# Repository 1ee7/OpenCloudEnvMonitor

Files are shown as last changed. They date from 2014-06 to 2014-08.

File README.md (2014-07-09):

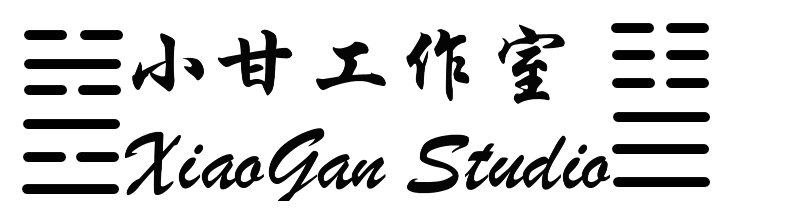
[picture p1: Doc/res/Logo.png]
小甘工作室

OpenCloudEnvMonitor
===================

**开源个人环境监测平台**

##系统简介
  系统框图请参考[这里](https://github.com/xiaogan-Studio/OpenCloudEnvMonitor/blob/master/Doc/design/%E7%B3%BB%E7%BB%9F%E6%A1%86%E5%9B%BE.xlsx)
  (Tips：点击 View Raw 下载excel文件查看。或者感兴趣的话，可以clone下来整个项目再查看。各种资料请到Doc目录下查看.)
  
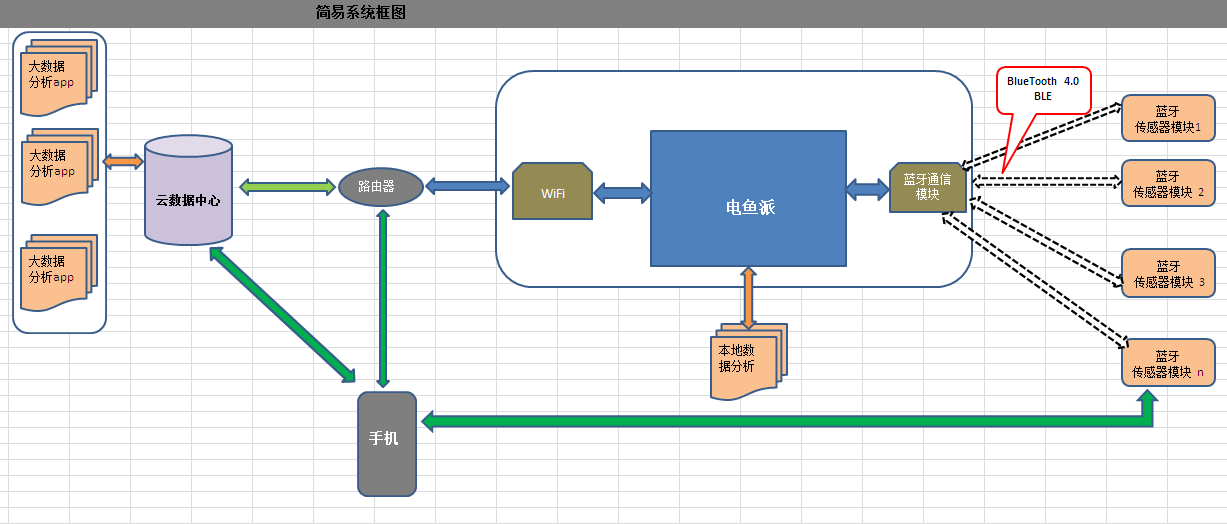
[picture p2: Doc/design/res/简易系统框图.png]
简易系统框图
         

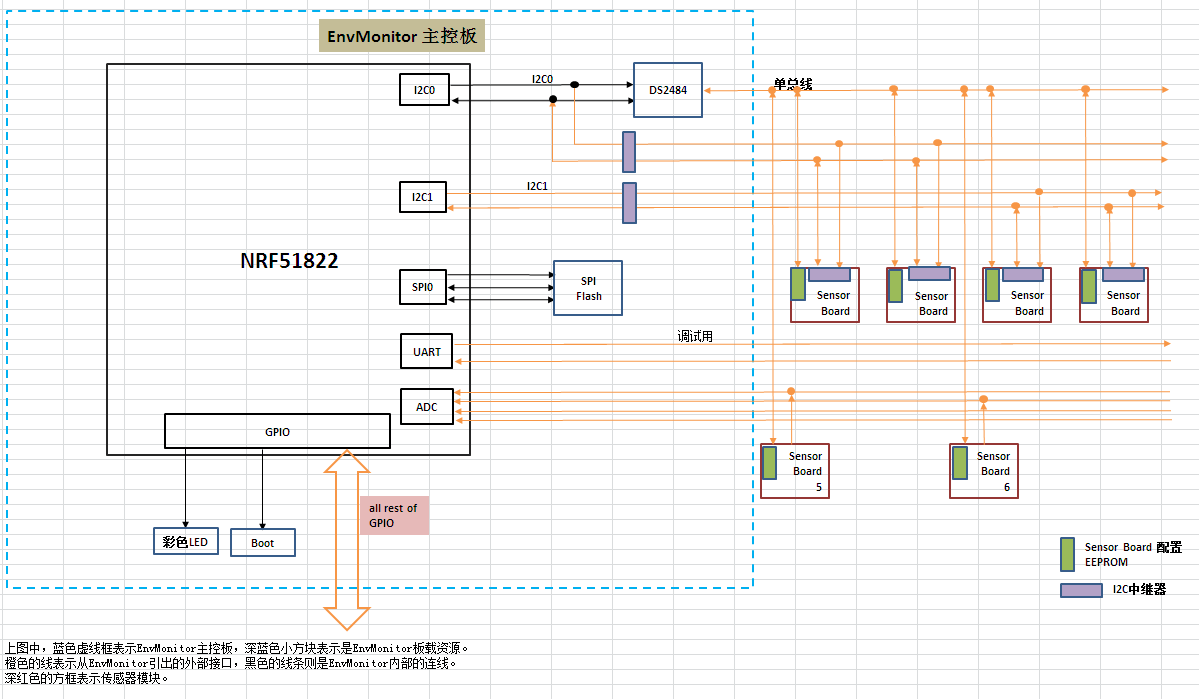
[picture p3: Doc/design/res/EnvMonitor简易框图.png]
蓝牙采集模块简易框图
  

## 相关资源列表
[oneNote共享笔记](https://onedrive.live.com/edit.aspx/Knowledge/OpenCloudEnvMonitor?cid=be5c272d3ffda8af&id=documents?&)，用于记录软硬件开发过程，包括各种问题的探讨资料。共享笔记，任何人均可编辑。其中：
- *envMonitor软件UML设计* 包含软件前期设计时一些分析资料。
- *硬件相关探讨* 与硬件相关的探讨。

### 硬件设计资源
[envMonitor MainBoard工程目录](./Doc/hardware/原理图),包含PDF版本的原理图以及AD工程文件

[envMonitor MainBoard原理图设计分析](./Doc/design/EnvMonitor原理图分析.docx)，简单分析，等硬件稳定后会提供详细分析文档。

### 软件设计资源

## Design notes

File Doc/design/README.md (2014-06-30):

# 本目录主要存放一些设计方面的文档资料。

## 系统框图.xlsx
  保存整个系统硬件方面的详细设计框图。包括如下内容：
  - 系统整体简略示意图                  （已作成）
  - EnvMonitor系统框图                  （已作成）
  - EnvMonitor的详细设计图              （TODO）
  - 各个Sensor board的系统框图          （TODO）
    1. 粉尘传感器Module框图              (TODO)
  - 各个Sensor board的详细设计图        （TODO）

## nRF51822硬件设计相关分析.xlsx
  保存硬件设计时的一些检讨资料。比如电源方案的探讨，外部通信接口的探讨等一些在设计时讨论资料。
  目前有如下内容：
  - 电源方案选择
  - 硬件模块化探讨
  - 增加USB功能的探讨：讨论与上位机USB通信的方法

## 软件框图.xlsx
   保存软件前期设计中的一些检讨资料。
   目前有如下内容：
   - EnvMonitor整体功能拆分
   - Sequence Diagram: 系统比较典型的一些序列图
   - BootLoader模型详细设计
   - Main模块详细设计
   - Initializer模块详细设计
   - Scheduler模块详细设计
   - SensorManager模块详细设计
   - SensorCapture模块详细设计
   - SensorUpload模块详细设计
   - SensorQuery模块详细设计
   - ConfigParser模块详细设计
   - BoardManager模块详细设计
   - OneWire Driver模块设计
   - I2C Driver模块设计
   - ADC Driver模块设计
   - DataCapture模块设计
   - SPI FlashDriver模块详细设计
   - SPI Driver模块详细设计
   - GPIO Driver模块详细设计
   - UART Driver模块详细设计
   - SystemDebug模块详细设计
   - PinMuxCfg模块详细设计
   - BLE Service Driver模块详细设计

## envMonitor.asta
  系统UML设计图表,保存系统软件设计相关的UML图纸。请使用[astah打开](http://astah.net/editions/community)
  - System overview
  - 用户升级序列图(sequence diagram)
  - 固件启动序列图(sequence diagram)
  - System Detail Design

## memory_layout.xlsx
  内部Flash和外部SPI Flash数据布局设计文件。标明数据在Flash中的摆放顺序。
  - 内部Flash Layout
  - 外部SPI Flash Layout
  - 1-Wire EEPROM Layout

## EnvMonitor原理图分析.docx
  关于原理图设计的一些简单分析。后期会提供比较详尽的电路分析资料
  
## 原理图Review记录.md
  EnvMonitor MainBoard原理图Review记录。保存Review过程中的一些问题。

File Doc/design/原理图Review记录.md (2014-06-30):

#EnvMonitor MainBoard原理图第一次Review
**时间:** 2014年6月27日

**参加人员：** 不限，有兴趣者都可编辑此文件，参与探讨

**6月29日 Review完成，TODO List如下**  
- [ ] 系统强制断电：由张建芳完成
- [x] USB转SPI芯片选型
      - → **放弃该方案**
- [x] SPI Flash 芯片SPI线和WP信号引出来，方便烧写器直接烧写
-     图纸更改时，可直接引出。
- [x] SPI Flash更换大容量的型号
-     型号已有，可以使用MX66L1G45G，1Gb，合计128MB。旺宏电子，SPI Flash最大的容量。

##1.EnvMonitor MainBoard图纸
- 原理图PDF版本：[6月27日原理图](https://github.com/xiaogan-Studio/OpenCloudEnvMonitor/blob/master/Doc/hardware/%E5%8E%9F%E7%90%86%E5%9B%BE/EnvMonitor%202014-6-27.pdf)
- 关于原理图的设计，请参考[here](https://github.com/xiaogan-Studio/OpenCloudEnvMonitor/blob/master/Doc/design/EnvMonitor%E5%8E%9F%E7%90%86%E5%9B%BE%E5%88%86%E6%9E%90.docx)

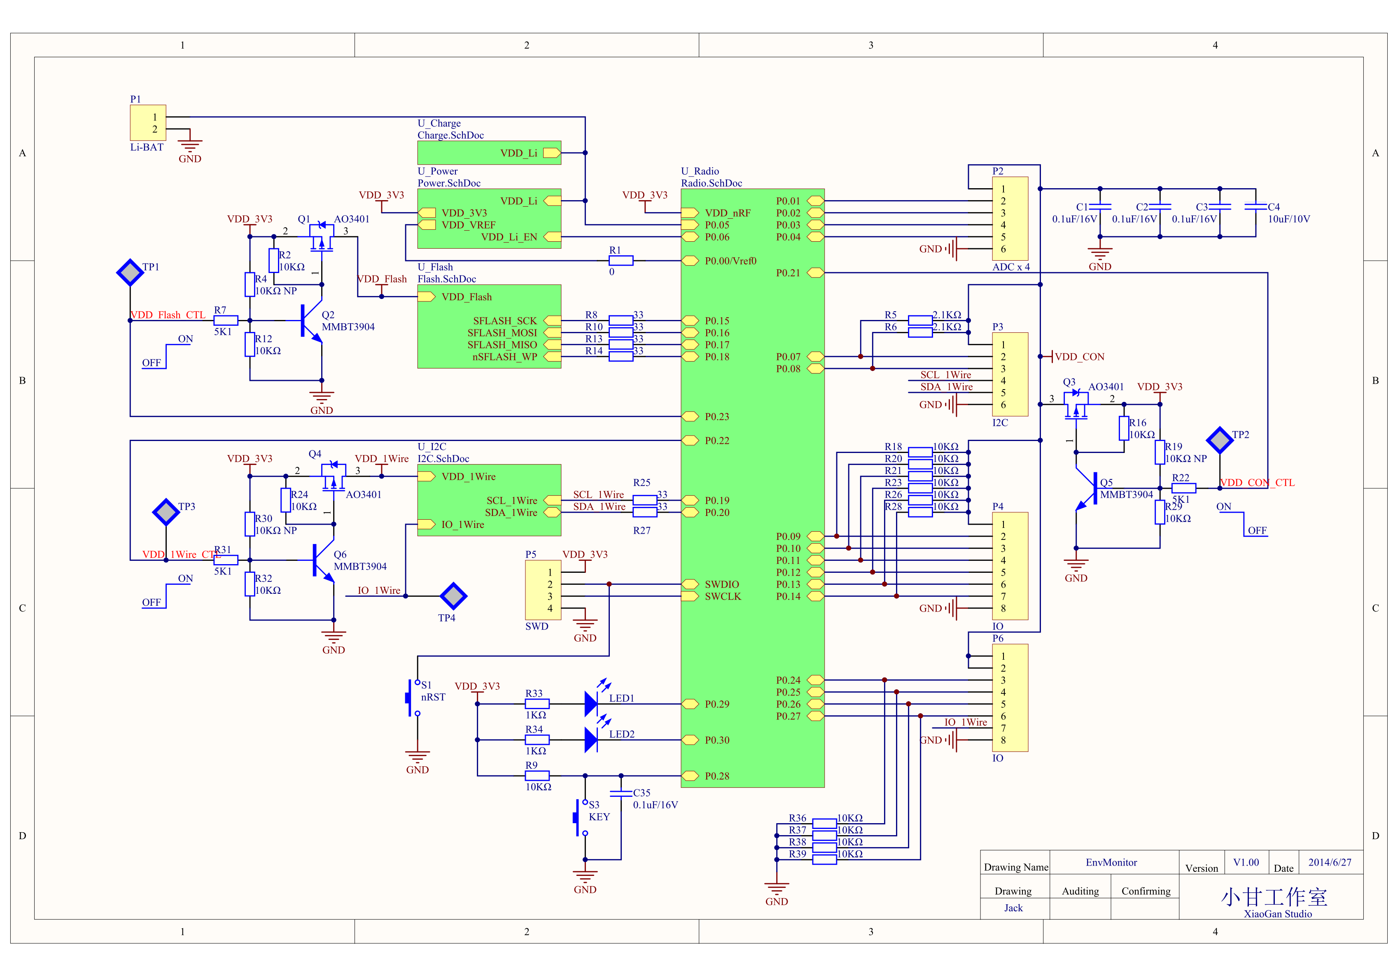
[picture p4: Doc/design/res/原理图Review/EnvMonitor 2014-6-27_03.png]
Overview

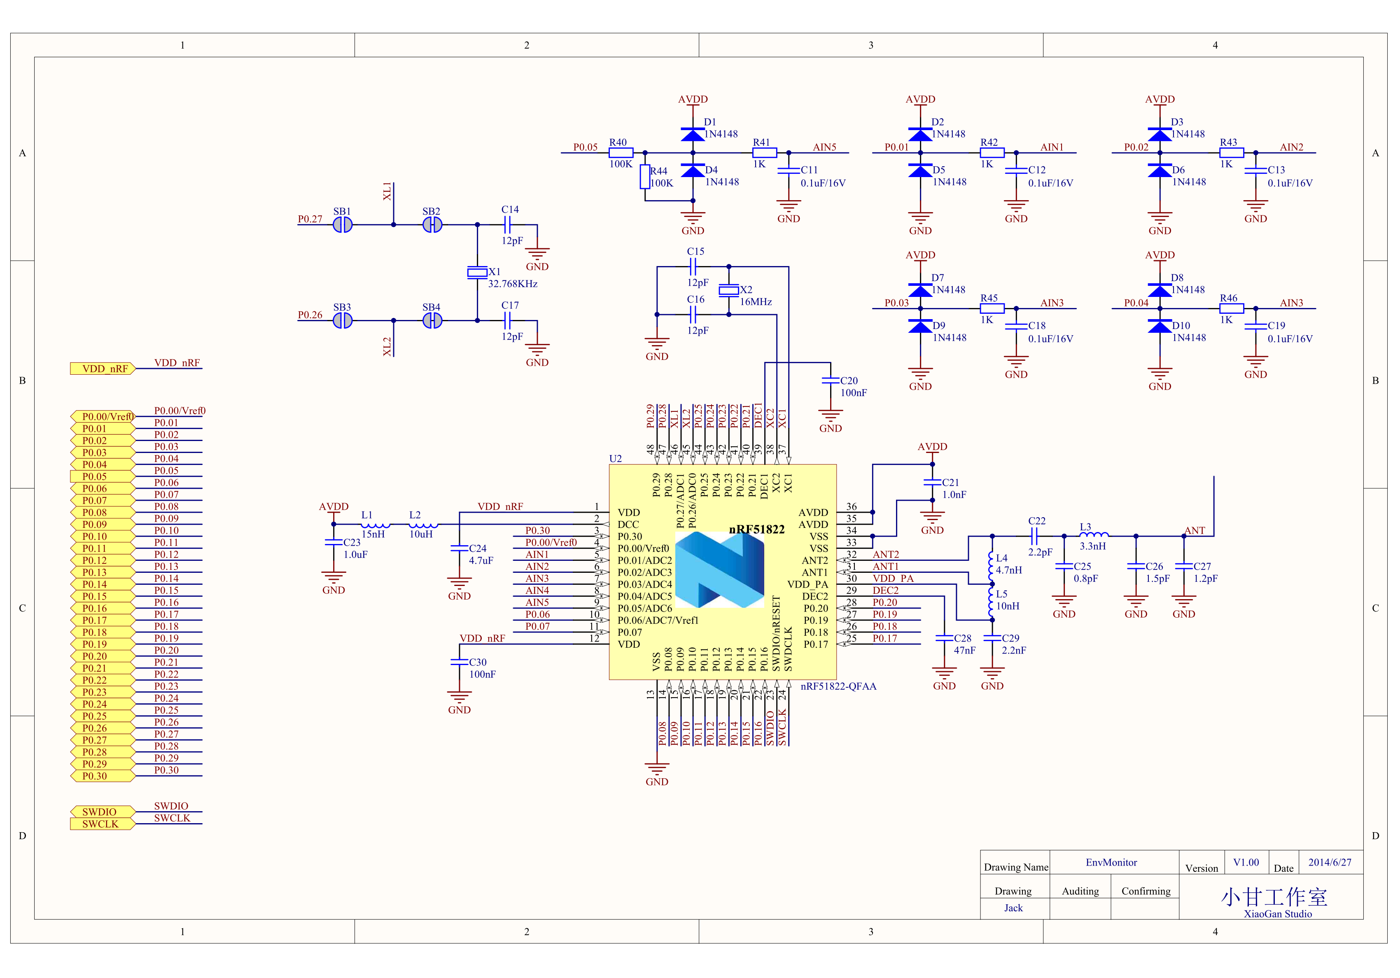
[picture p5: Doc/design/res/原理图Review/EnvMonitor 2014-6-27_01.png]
nRF51822

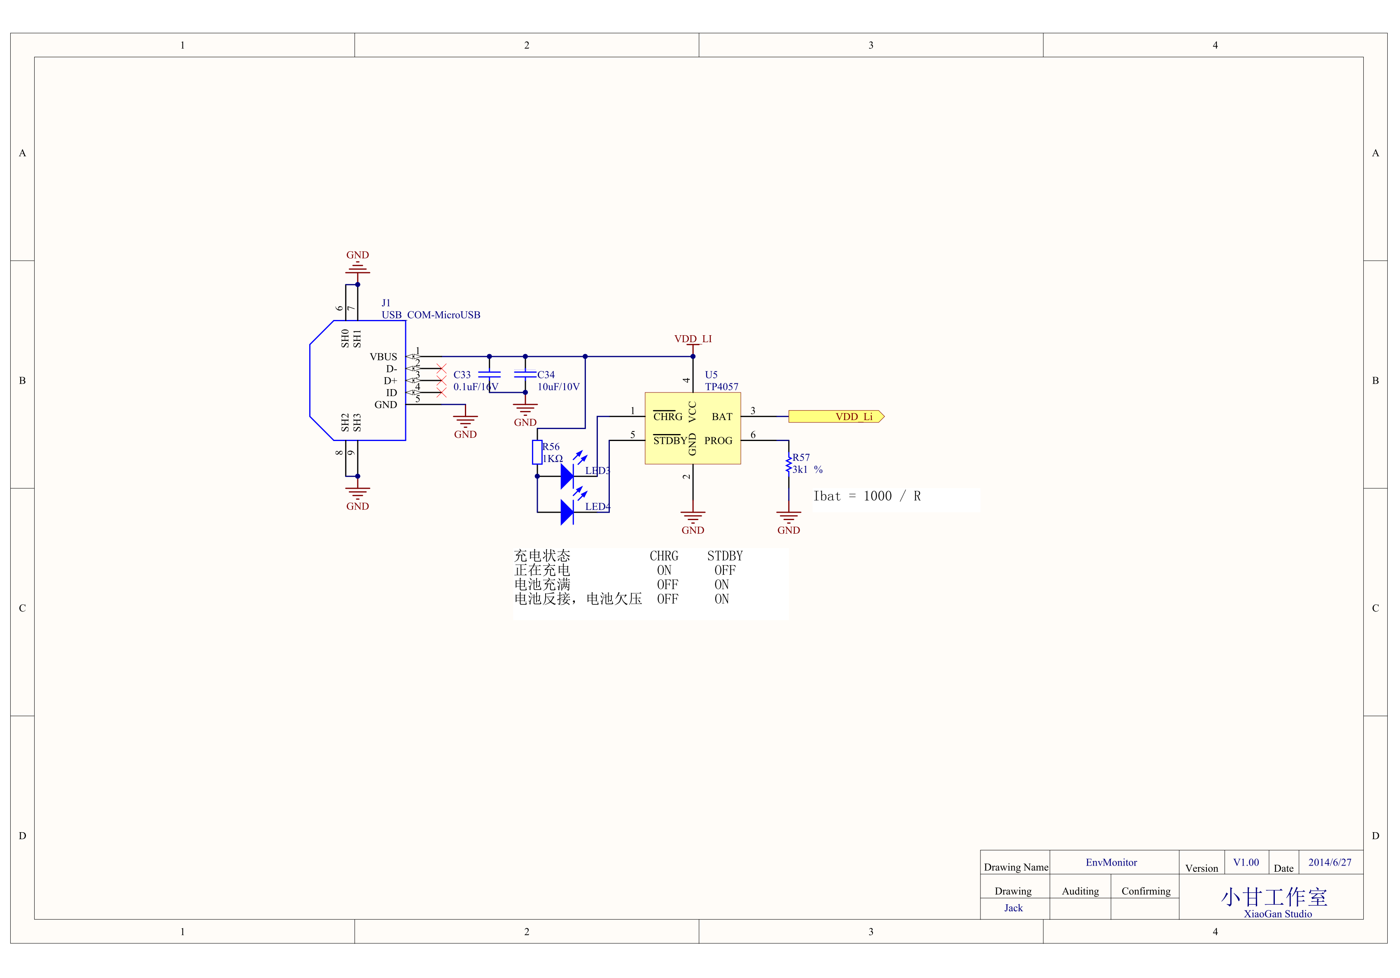
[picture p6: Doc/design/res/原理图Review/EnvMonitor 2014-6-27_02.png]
充电电路

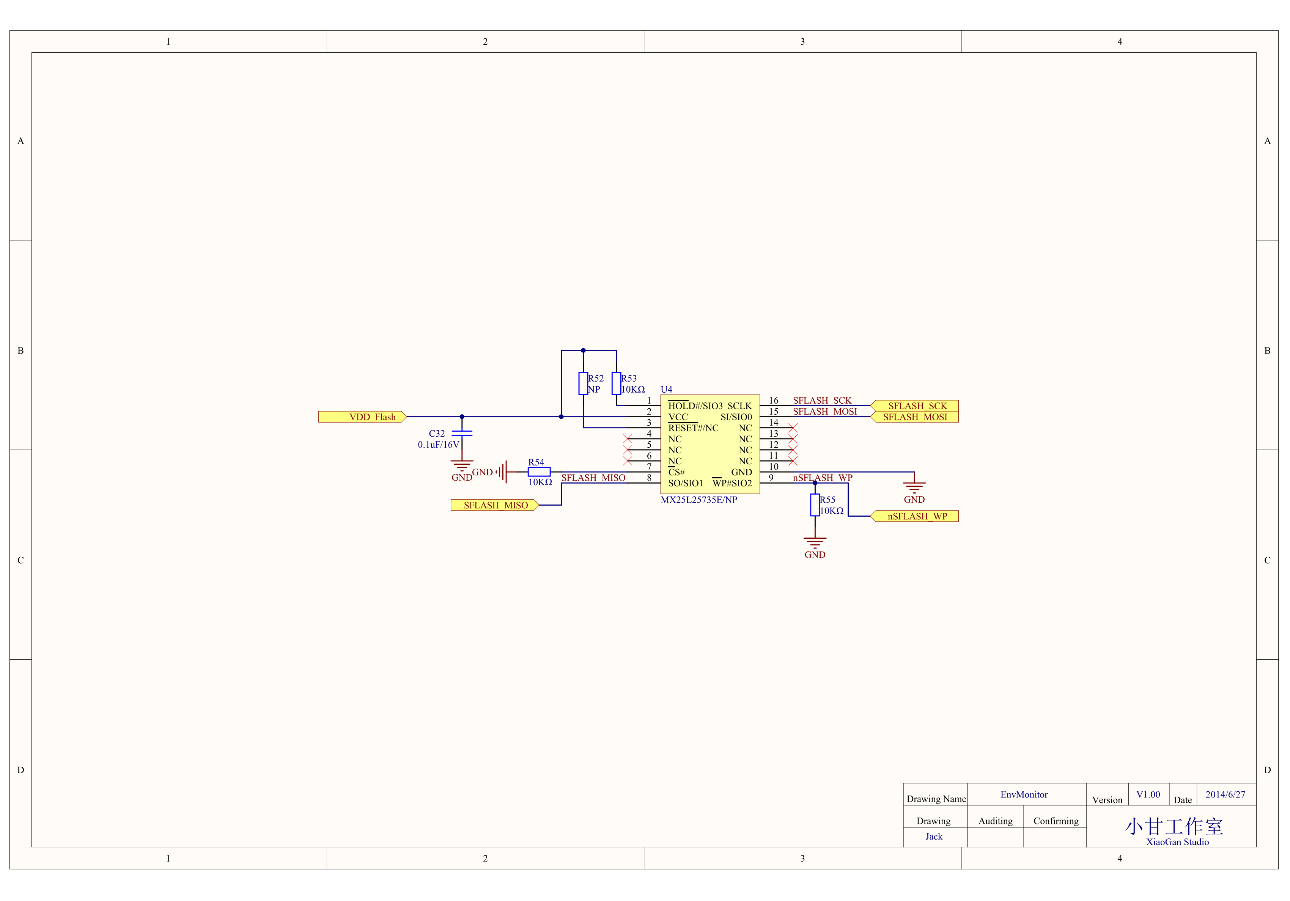
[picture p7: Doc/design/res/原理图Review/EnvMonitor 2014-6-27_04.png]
SPI Flash

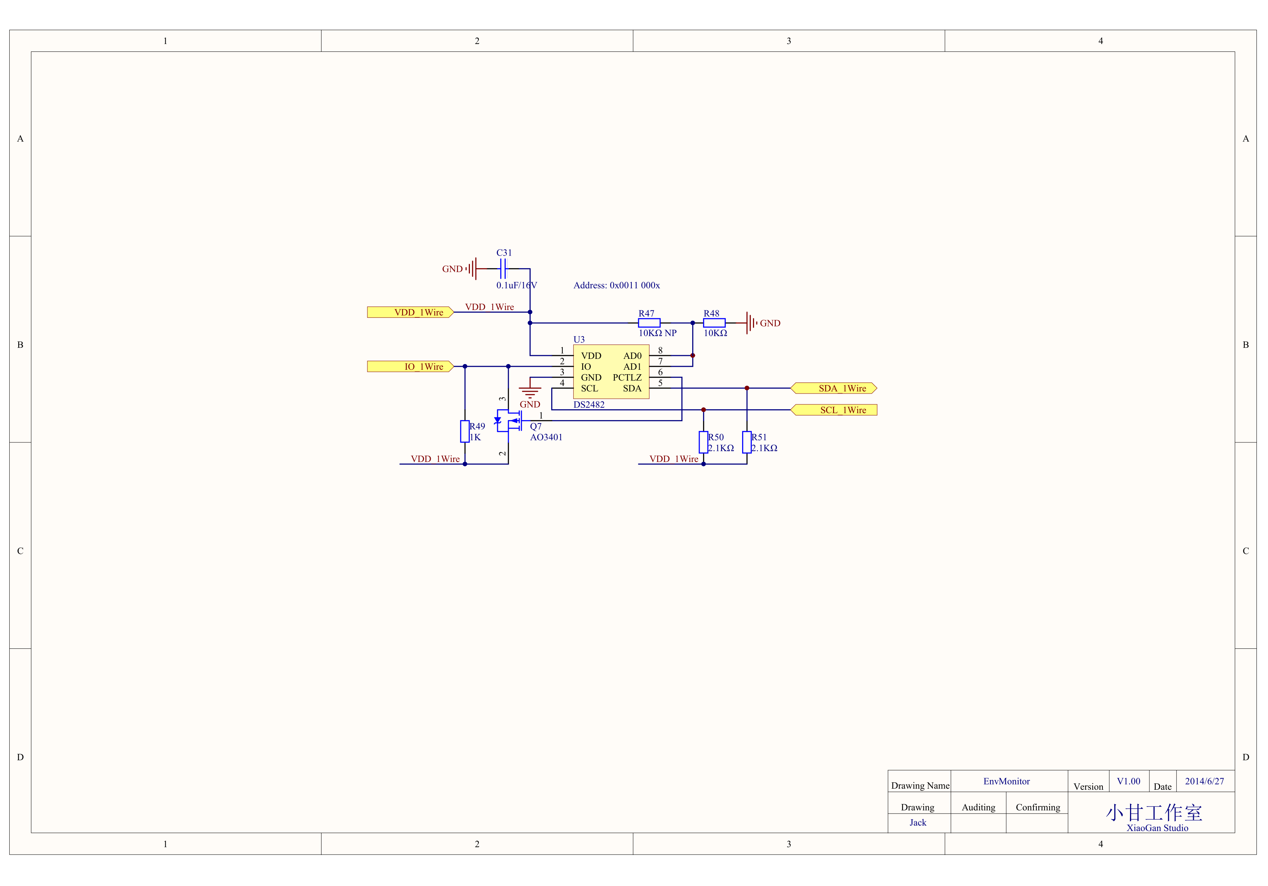
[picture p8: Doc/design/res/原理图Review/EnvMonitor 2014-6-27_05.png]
单总线

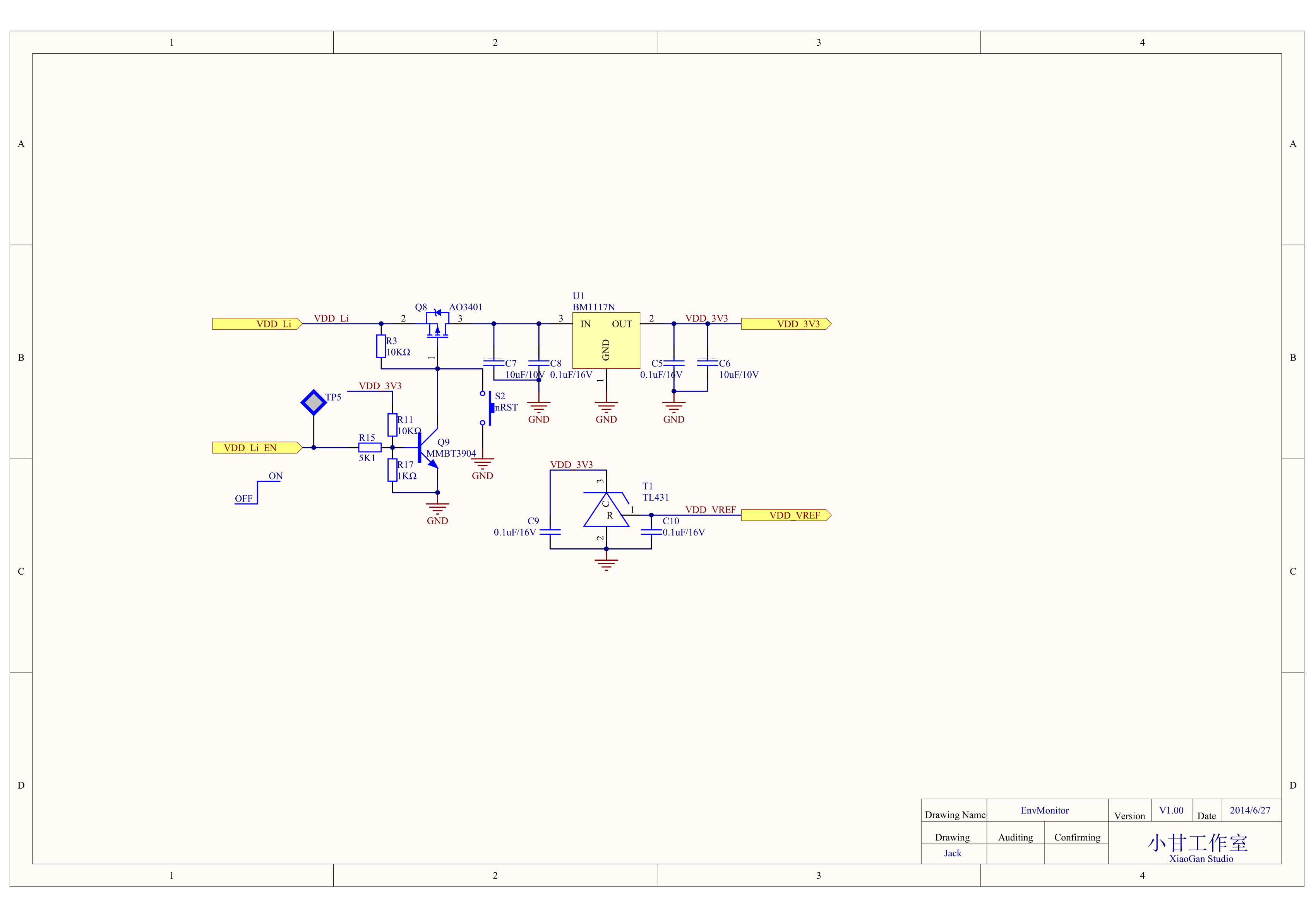
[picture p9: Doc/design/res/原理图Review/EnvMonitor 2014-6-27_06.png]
电源及ADC Reference


## 2.相关问题探讨
### 2.1 按键升级
添加一个按键，用来指示是否进入升级模式。即，在Bootloader启动过程中，判断该按键的状态，从而判断是否进入升级模式。

### 2.2 消减一路I2C
目前单总线芯片DS2482独占一路I2C（P0.19 P0.20）。浪费资源，并且系统只有两路硬件I2C，考虑从下面两路I2C中去除一路：
- P0.07 P0.08
- P0.09 P0.10
然后将P0.19 P0.20这一路I2C同时导出给外设(SensorBoard)使用。

最新版图纸已修改。

### 2.3 电源启动方式修改
将`VDD_Li_EN`信号上拉到`VCC_3V3`，之所以这样做，原因如下：

目前的启动方法是，长按S2开关，等系统启动后，立马去拉高`VDD__Li__EN`，这时才可以松开S2。在nRF1822置高`VDD_Li_EN`之前，不能松开S2，但是这个时机比较难掌控
恐用户使用起来不方便。
不能在原来基础上增添`VDD_Li_EN`的上拉电阻，但是只能从`VDD_3V3`上拉，而不是`VDD_Li`上拉，否则会造成系统无法断电。

最新版图纸已修改。将`VDD_Li_EN`信号上拉到`VCC_3V3`后，开机时，S2不需要按下很长（如2S），即可启动系统。

**强制断电，需要如何操作？**

### 2.4 USB访问SPI Flash功能
**第一版不准备使用该功能，因为有蓝牙和串口通信，感觉USB通信没什么必要**

想法是这样的：当插入USB后，不仅可以对锂电池充电，而且可以更新固件，读取存储在Flash中的环境数据。

但是由于nRF51822不支持USB，只能外扩芯片来解决。目前想到的方法有如下两种：
- [ ] 通过USB转SPI芯片，上位机直接访问SPI Flash。
      - 优点 ：简单，nRF51822不需要增加太多的代码
      - 缺点 ：USB连接时，无法进行数据采集工作。因为SPI Flash由USB上位机控制，nRF51822无法访问，此时只能采集一次数据就上传给蓝牙主机。
- [x] nRF51822外扩一个SPI转USB的芯片，从而增加USB功能。上位机通过USB与nRF51822通信，然后再由nRF51822将SPI Flash的数据传输给上位机
     - 优点： SPI Flash由nRF1822控制，所以USB连接时，可以同时进行数据采集。交互性更好，可以实现更多其他的功能。
     - 缺点： 增加代码空间较大，调试复杂 

待探讨确认问题：
- [x] 方案选择: 使用第二种方案，nRF51822外扩SPI转USB芯片，与上位机通信。
- [ ] 确保USB上位机及nRF51822不同时访问SPI Flash。
    - 方法1： 通过某种方式让nRF51822知道USB的连接状态，当USB连接后，自动禁止本身对SPI Flash的访问
    - 方法2： 上位机与nRF51822通信，相互协商，确保不同时访问SPI Flash。通信方式可以选择SPI，nRF51822支持SPI从机功能。
- [ ] 芯片选型，目前找到如下三款芯片：
   -  [Silicon Labs CP2130](http://www.silabs.com/products/interface/usbtouart/pages/usb-to-spi-bridge.aspx)
   -  [MAX3421](http://www.maximintegrated.com/cn/products/interface/controllers-expanders/MAX3421E.html) 芯片太贵  
   -  [MCP2210](http://www.microchip.com/wwwproducts/Devices.aspx?product=MCP2210)

更详细的讨论，请参考[硬件设计文档](https://github.com/xiaogan-Studio/OpenCloudEnvMonitor/blob/master/Doc/design/nRF51822%E7%A1%AC%E4%BB%B6%E8%AE%BE%E8%AE%A1%E7%9B%B8%E5%85%B3%E5%88%86%E6%9E%90.xlsx)
中“增加USB功能的探讨”一页。

### 2.5 充电时间的考虑
目前USB充电电流为1000/R57= 1000/3000 约为333mA。是否考虑增大充电电流，从而减少充电时间。

充电时间取决于锂电池的容量，一般的充电电流建议在0.2C~1C（C即锂电池的容量，如果锂电池的容量为700mAH，C即为700mA），电流越大，充电越快，同时电池发热也越大。而且，过大的电流充电，容量不够满，因为电池内部的电化学反应需要时间。就跟倒啤酒一样，倒太快的话会产生泡沫，反而不满。
还有，后期如果选择电池容量较大，充电时间较长，可根据实际需要进行调整电阻的阻值。

### 2.6 SPI Flash Reset时序
就原理图上看，MX25L25735E芯片的RESET引脚是上拉VDD_Flash的。会不会影响芯片上电时序？

不会。这里的上拉电阻为兼容设计，对于MX25L芯片来说，引脚对应的是NC，电阻不焊接。

### 2.7 S1防抖
S1复位开关，需要接防抖电路吗？

个人认为，加不加，对于复位电路来说，意义不大。

### 2.8 SPI Flash 容量
目前为256Mb，32MB，感觉有点小。在价格合适的情况下，考虑增大容量。

容量粗略计算：

每秒10次采样，最多10个设备，那么按照每秒1KB的数据量(平均每个设备10字节/次的数据量)，则一天的数据量为：`1KB*60*60*24=86400KB` 约85MB。

再考虑到固件及其他的数据，使用128MB是最小的容量。

可以考虑加大容量。

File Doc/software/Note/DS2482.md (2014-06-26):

# DataSheet学习
## 1.简介
## 2.状态寄存器
状态寄存器位图
DS2482用只读状态寄存器来向上位机报告1-Wire总线状态。所有1-Wire总线命令和DS2482复位命令，会将读指针放置到状态寄存器的位置，从而减少
协议开销。
状态寄存器只在执行某些特定的命令时才会被更新。
详情描述如下：
### 2.1.1 1-Wire Busy(1WB)
1-Wire总线忙标志位，1表示总线上有数据通信，0表示总线空闲。有关何时1WB状态变更，以及持续时间请参考[Function Commands一节](##Function Commands)。

### 2.1.2 Presence-Pulse Detect (PPD)
每次1-Wire复位命令会更新PPD位。在presence-detect阶段，如果DS2482在tMSP时间内检测到从机发送过来的在线脉冲，则PPD被置为1。

### 2.1.3 Short Detected（SD）
SD位在每次执行1-Wire复位操作时被更新。在presence-detect阶段，如果DS2482在tSI时间内检测总线为0，则SD被置为1。如果SD为1，则PPD为0。

### 2.1.4 Logic Level（LL）
LL位表示1-Wire总线的逻辑状态，而不需要初始化任何1-Wire通信。LL位在每次读取状态寄存器的时候被更新。

### 2.1.5 Device Reset（RST）
如果RST为1，则表明DS2482执行过内部复位流程，无论是上电复位或者是因为响应设备复位命令(Device Reset Command)引起的。当DS2482执行Write Configuration
命令后，RST被置为0。

### 2.1.6 Single Bit Result（SBR）
- 在1-Wire Single Bit命令时，SBR表示命令的结果；
- 在1-Wire Triplet命令时，SBR表示返回结果的第一位，第二位由TSB表示。 

### 2.1.7 Triplet Second Bit（TSB）
1-Wire Triplet命令的返回结果的第二位。只在Triplet命令时被更新，在其他情况下无意义。

### 2.1.8 Branch Direction Taken（DIR）
在1-Wire Triplet命令执行时，DIR表示在搜索时选择的方向。只在Triplet命令时被更新，在其他情况下无意义。

## Function Commands

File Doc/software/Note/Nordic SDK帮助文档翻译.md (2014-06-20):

# Scheduler handling library
  调度器的作用是将执行流程从中断上下文(Interrupt context)切换到Main上下文(Main context).

## 必要条件：
   - Main上下文：
     - 为所需要的所有事件定义一个处理函数(handler);
     - 在进入主循环之前，调用APP_SCHED_INIT()函数初始化调度器;
     - 在主循环中调用app_sched_execute()，当系统从任何一个等待事件中唤醒后（典型情况是`sd_app_evt_wait()`函数返回）。
  - Interrupt上下文：
    - 在中断处理函数中，调用`app_sched_event_put()`函数，将事件插入到调度器的队列中。`app_sched_execute()`函数将会从队列中取出该事件，并且
    调用该事件的处理函数。    
    
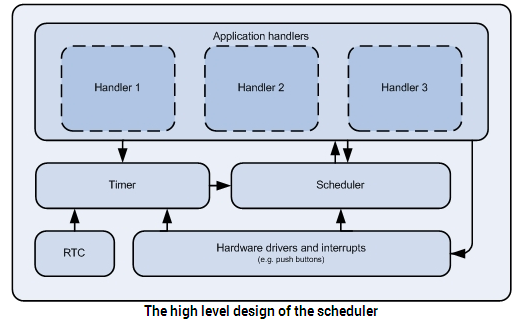
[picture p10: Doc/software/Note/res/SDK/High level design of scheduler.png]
调度器顶层设计


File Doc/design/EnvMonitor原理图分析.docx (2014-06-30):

EnvMonitor原理分析

1.电源

1）供电电源

系统使用单节锂电池供电。锂电池满电情况下是4.2V，最低可放电至3.0V，再低则有可能对锂电池造成永久性破坏。故系统软件需检测锂电池电压，建议放电低至3.3V，系统软关闭。

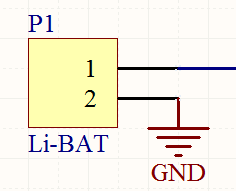
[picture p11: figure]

2）系统电源

系统电源通过Q8、BM1117N（低压差LDO芯片）进行降压至3.3V，BM1117N的输入与输出压差最低至0.2V左右，可最大限度的使用锂电池的电量。

系统通过IO口来控制是否使用锂电池放电。初始上电时，按下按键S2，Q8的栅极电压为低电平，Q8导通，BM1117N输出电压3.3V，然后MCU控制VDD_Li_EN输出高电平，维持Q8导通。当检测到锂电池电压欠压时，拉低VDD_Li_EN，使得Q8不导通，则MCU处于断电模式。

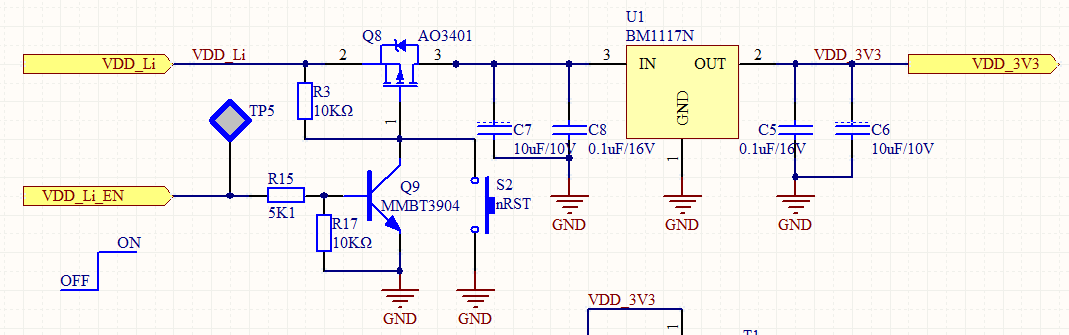
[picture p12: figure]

Q8：小功率P沟道MOS管。Vgs = -10V，Id = -4A，Rds = 42m欧姆，在本系统中的电压损耗为：Vmos = 0.04 x 0.02 = 0.0008V，基本可忽略。BM1117N输入电压基本与VDD_Li等同；

R3：默认拉高MOS管的栅极，避免MOS管关断不彻底；

R15：限流电阻，防止IO口输出高电平烧坏Q9；

R17：默认拉低VDD_Li_EN信号，使LDO没有输出；

Q9：小功率三极管，用来控制Q8的栅极电压；

S2：用来直接控制Q8是否导通，初始上电时用作开关；

C6、C7：储能电容；

C5、C8：滤波电容，滤除高频信号；

BM1117N：LDO芯片，输出200mA时，仅需压差200mV。芯片最大可输出1A电流。

3）充电电路

系统通过Micro-USB端口，对锂电池进行充电。

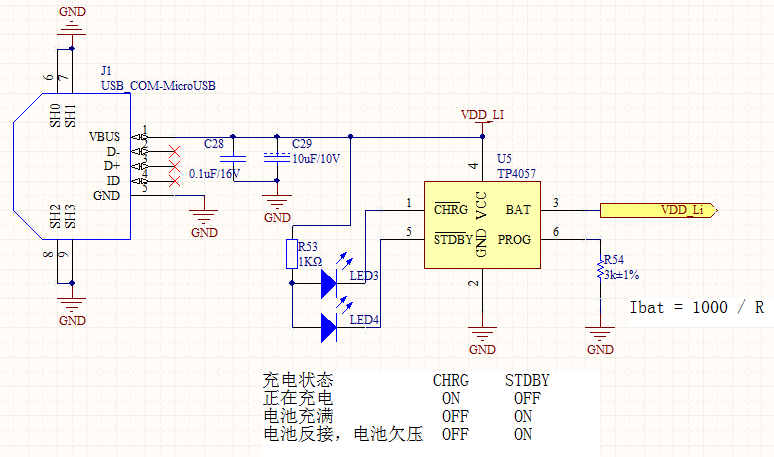
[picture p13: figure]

C28、C29：储能和滤波电容；

R53：充电状态指示灯的限流电阻；

LED3、LED4：充电状态指示灯；

R54：充电电流配置电阻，Ibat = 1000 / R，如果R54为3K欧姆，则Ibat = 333mA。

4）参考电源

AD使用的参考电源，使用TL431，可输出2.5V的参考基准电源。

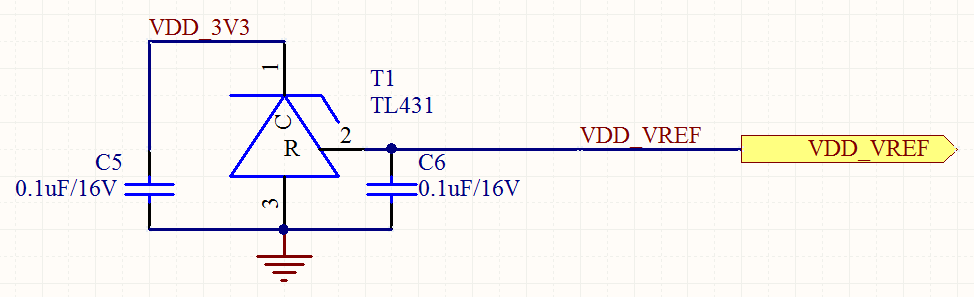
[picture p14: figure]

C5、C6：滤波电容。

5）其他电源

其他电源，如VDD_Flash、VDD_1Wire、VDD_CON，均通过IO口、MOS管进行独立控制。控制电路如下图所示。

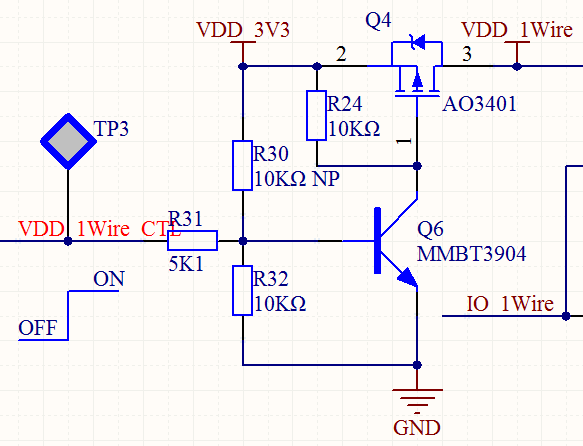
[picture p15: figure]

R31：限流电阻，防止IO口输出高电平时，烧坏Q2；

R30、R32：保持初始电平，默认Q4不导通，即不对外供电；

R24：默认拉高MOS管的栅极，避免MOS管关断不彻底；

Q4：小功率P沟道MOS管，导通损耗小；

Q6：小功率三极管，用来控制Q4的栅极电压；

2.I2C to 1Wire

通过DS2482，将I2C转换为1Wire，用于连接单总线设备。

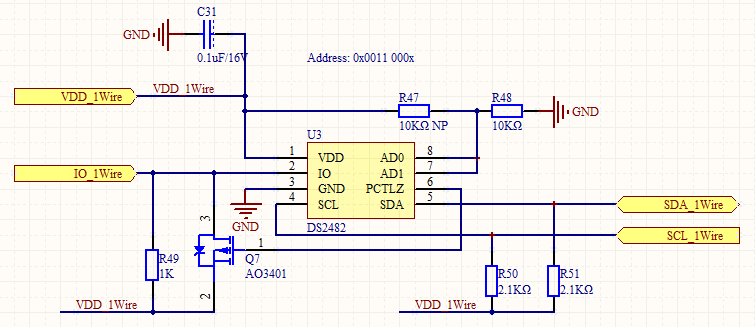
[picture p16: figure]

C31：退耦电容；

R47、R48：配置I2C地址；

R49、Q7：用于拉高1Wire，参数参考手册；

R50、R51：I2C上拉电阻，速度较高时，上拉电阻较小。这里取2.1K的电阻，使得I2C的速度可不受上拉电阻限制。

3.Flash

通过SPI接口，扩展一片Flash，容量为256Mb。

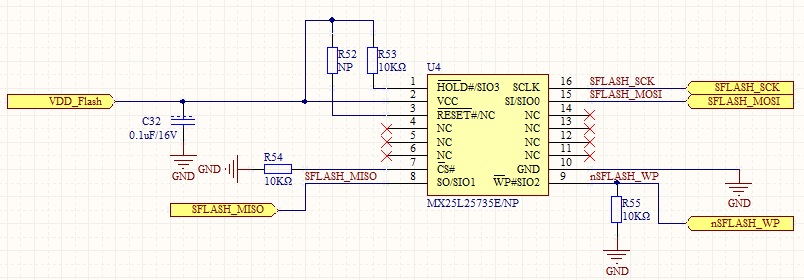
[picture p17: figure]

R32：兼容设计，有些Flash（如MX25L25735）的3脚为NC，有些为复位信号；

R51：拉高HOLD，不使用Flash内部的保持功能；

R33：拉低CS信号，默认有效；

R52：拉低WP信号，默认写保护。

4.MCU

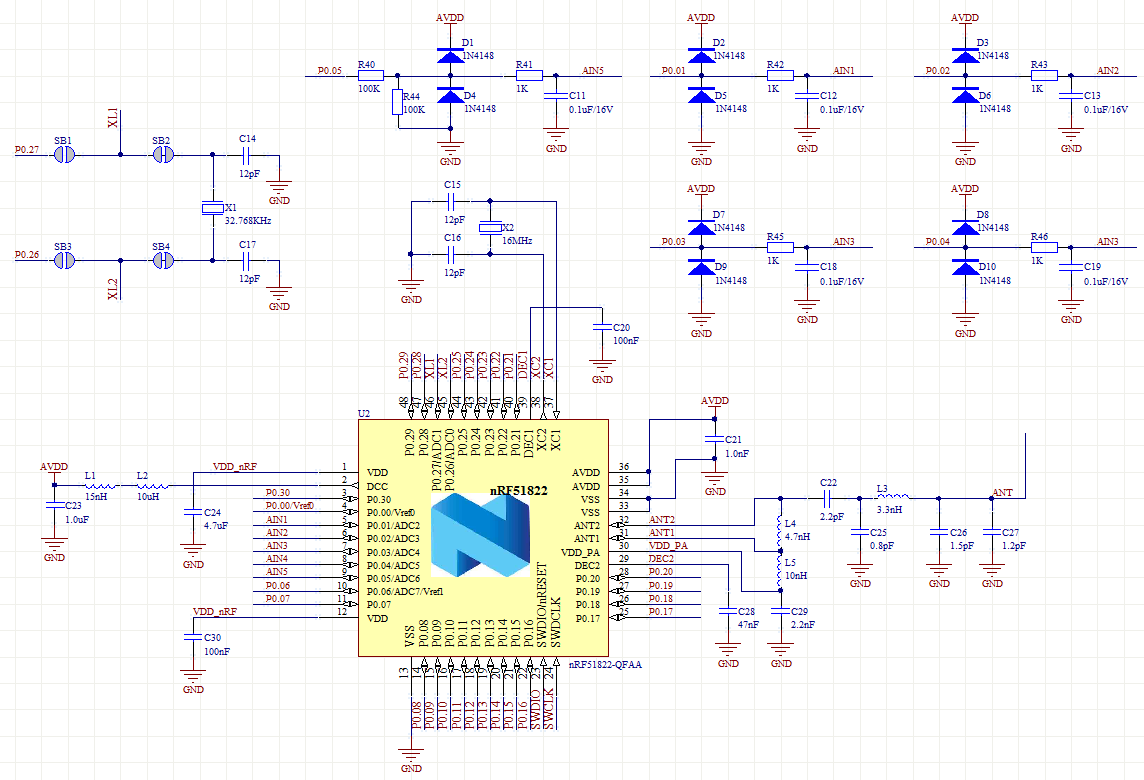
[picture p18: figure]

1）电源

使用芯片内部的DC-DC，输入电源通过VDD_nRF进入MCU，然后经过内部的DC-DC输出电压至系统内部使用，并通过L1、L2电感输出至AVDD，供模拟部分使用。

AVDD、VDD、DEC1、DEC2的滤波电容，均采用MCU推荐值。

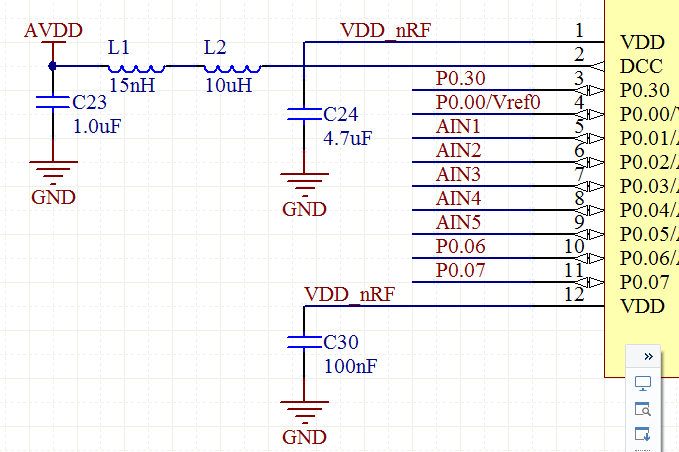
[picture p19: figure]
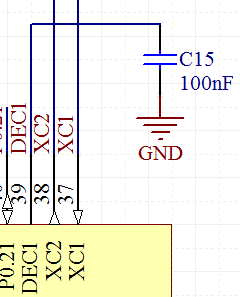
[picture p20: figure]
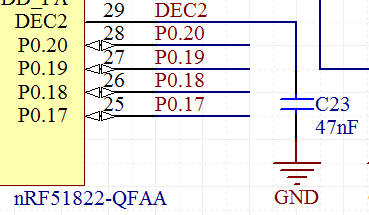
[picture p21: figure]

2）天线

天线部分使用MCU推荐电路，参数未作修改。

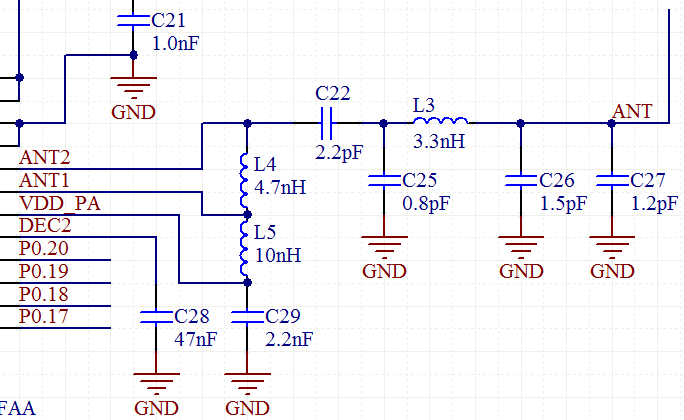
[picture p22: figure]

3）晶振

使用普通的无源晶振32.768KHz和16MHz。

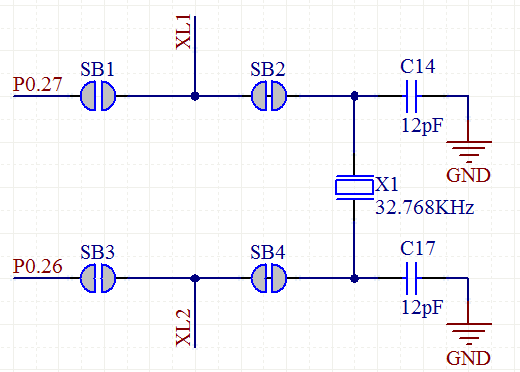
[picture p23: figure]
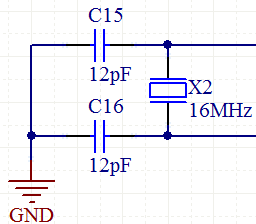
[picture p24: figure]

4）ADC

预留4路AD，用来连接输出模拟量的传感器。

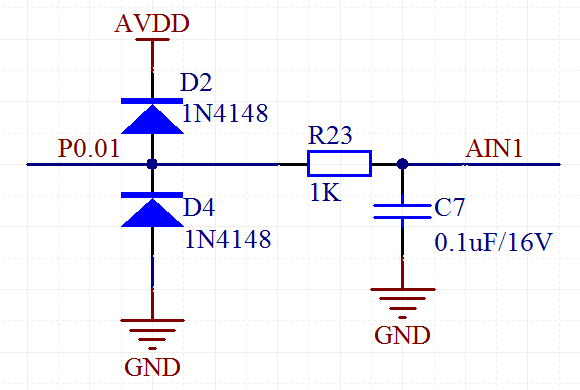
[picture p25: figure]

D2、D4：用来钳位，限制模拟量的输入电平，输入过高时，D2导通，将电压钳位在3.9V左右；如果输入电压过低，D4导通，将电压钳位在0.6V左右；

R23、C7：用来组成RC滤波，滤除不必要的信号。截至频率为 f = 1 /（2 pi R C），约等于1.6KHz。

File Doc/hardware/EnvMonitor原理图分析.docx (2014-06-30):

EnvMonitor原理分析

V1.0

小甘工作室 2014-6-27

1.电源

1）供电电源

系统使用单节锂电池供电。锂电池满电情况下是4.2V，最低可放电至3.0V，再低则有可能对锂电池造成永久性破坏。故系统软件需检测锂电池电压，建议放电低至3.3V，系统软关闭。


2）系统电源

系统电源通过Q8、BM1117N（低压差LDO芯片）进行降压至3.3V，BM1117N的输入与输出压差最低至0.2V左右，可最大限度的使用锂电池的电量。

系统通过IO口来控制是否使用锂电池放电。初始上电时，按下按键S2，BM1117N输出3.3V电压，继而通过电阻R11，使得Q9导通，Q8的栅极电压为低电平，Q8导通，维持BM1117N继续输出电压，然后MCU控制VDD_Li_EN输出高电平，维持Q8导通。当检测到锂电池电压欠压时，拉低VDD_Li_EN，使得Q9处于关断状态，Q8不导通，BM1117N无输出，则MCU处于断电模式。

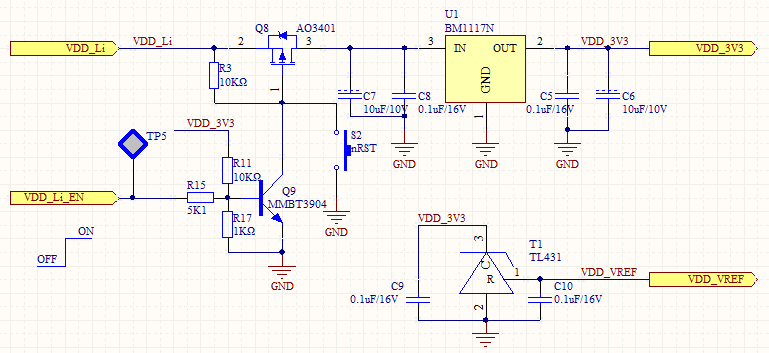
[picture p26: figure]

Q8：小功率P沟道MOS管。Vgs = -10V，Id = -4A，Rds = 42m欧姆，在本系统中的电压损耗为：Vmos = 0.04 x 0.02 = 0.0008V，基本可忽略。BM1117N输入电压基本与VDD_Li等同；

R3：默认拉高MOS管的栅极，避免MOS管关断不彻底；

R11：上拉电阻，当VDD_3V3有电时，拉高VDD_Li_EN信号；

R15：限流电阻，防止IO口输出高电平烧坏Q9；

R17：下拉电阻，使Q9可以可靠的截止；

Q9：小功率三极管，用来控制Q8的栅极电压；

S2：用来直接控制Q8是否导通，初始上电时用作开关；

C6、C7：储能电容；

C5、C8：滤波电容，滤除高频信号；

BM1117N：LDO芯片，输出200mA时，仅需压差200mV。芯片最大可输出1A电流。

3）充电电路

系统通过Micro-USB端口，对锂电池进行充电。


C28、C29：储能和滤波电容；

R53：充电状态指示灯的限流电阻；

LED3、LED4：充电状态指示灯；

R54：充电电流配置电阻，Ibat = 1000 / R，如果R54为3K欧姆，则Ibat = 333mA。

4）参考电源

AD使用的参考电源，使用TL431，可输出2.5V的参考基准电源。


C5、C6：滤波电容。

5）其他电源

其他电源，如VDD_Flash、VDD_1Wire、VDD_CON，均通过IO口、MOS管进行独立控制。控制电路如下图所示。


R31：限流电阻，防止IO口输出高电平时，烧坏Q2；

R30、R32：保持初始电平，默认Q4不导通，即不对外供电；

R24：默认拉高MOS管的栅极，避免MOS管关断不彻底；

Q4：小功率P沟道MOS管，导通损耗小；

Q6：小功率三极管，用来控制Q4的栅极电压；

2.I2C to 1Wire

通过DS2482，将I2C转换为1Wire，用于连接单总线设备。


C31：退耦电容；

R47、R48：配置I2C地址；

R49、Q7：用于拉高1Wire，参数参考手册；

R50、R51：I2C上拉电阻，速度较高时，上拉电阻较小。这里取2.1K的电阻，使得I2C的速度可不受上拉电阻限制。

3.Flash

通过SPI接口，扩展一片Flash，容量为256Mb。


R32：兼容设计，有些Flash（如MX25L25735）的3脚为NC，有些为复位信号；

R51：拉高HOLD，不使用Flash内部的保持功能；

R33：拉低CS信号，默认有效；

R52：拉低WP信号，默认写保护。

4.MCU


1）电源

使用芯片内部的DC-DC，输入电源通过VDD_nRF进入MCU，然后经过内部的DC-DC输出电压至系统内部使用，并通过L1、L2电感输出至AVDD，供模拟部分使用。

AVDD、VDD、DEC1、DEC2的滤波电容，均采用MCU推荐值。


2）天线

天线部分使用MCU推荐电路，参数未作修改。


3）晶振

使用普通的无源晶振32.768KHz和16MHz。


4）ADC

预留4路AD，用来连接输出模拟量的传感器。


D2、D4：用来钳位，限制模拟量的输入电平，输入过高时，D2导通，将电压钳位在3.9V左右；如果输入电压过低，D4导通，将电压钳位在0.6V左右；

R23、C7：用来组成RC滤波，滤除不必要的信号。截至频率为 f = 1 /（2 pi R C），约等于1.6KHz。

5）Update和LED

系统包含有1个检测是否升级的按键和2个LED指示灯。但S3按下时，系统通过蓝牙或者串口升级固件。

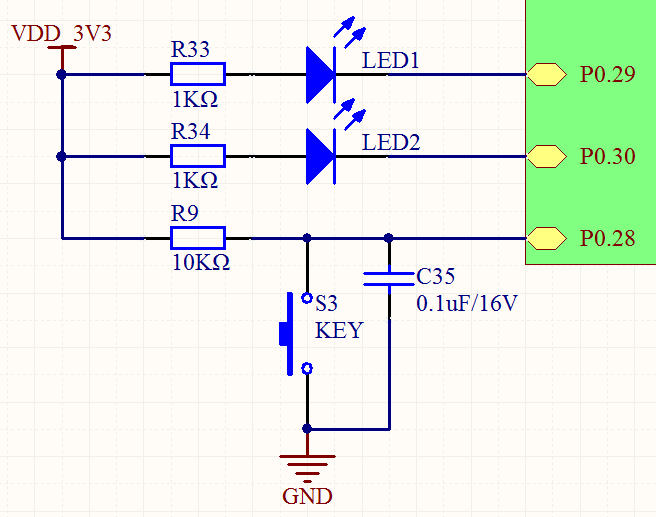
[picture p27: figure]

R33、R34：限流电阻；

R9：上拉电阻；

C35：消抖电容；

S3：检测是否升级的按键。

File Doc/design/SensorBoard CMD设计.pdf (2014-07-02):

存储位置; 页。page由ROMDriver管理。; 都由ROMDriver来封装。; 存储在SensorBoard上的EEPROM中，偏移位置为0x8; 存储位置 命令存储格式 分隔符 命令返回; ● 命令集分割符; 每个命令集必须由||包围，即命令集开头和结尾必须是||。; ● 命令分隔符; 每条命令必须包含命令分隔符;，即使命令集中仅有一条命令。; 使用空格分隔。; ● 参数分隔符; 分隔符; ● 命令采用字符格式存储； ● 区分大小写。; 命令存储格式; 命令返回; 无法引用上一条之前的命令的结果。; ● 数据型。返回结果为char或者int。; ● 指针型。返回结果为一个缓冲区指针。; 返回结果分类; 返回结果; 可变长度比较难管理，每条命令的返回结果具体有多长，需要参照手册，比较麻烦。; 对于只返回一个结果的命令，一般情况下，4字节足够盛放。; 对于返回多于一个结果的命令，此时可以使用缓冲区返回，返回结果为指向该缓冲区的指; 针，在32位机的情况下，正好是4字节。; 不如固定为4字节。考虑如下：; 返回结果长度固定为4字节？还是可变？; SensorBoard CMD设计

Tips:EEPROM是有Page的概念的，但是为了通用性考虑，这里忽略Page概念，不考虑是否跨

同时，也有可能更改存储芯片，所以这里的偏移位置只是针对存储器的开始来讲。具体实现

所谓命令集，是指attachCMD或者captureCMD或者detachCMD。每个CMD可以包含很多命令。而命令集分隔符是用来区分这些CMD集的。

example：||I2C 1 W 0x10 0x3;||GPIO 2 O H;||;||

有可能一条命令需要使用上一条命令的返回结果。目前限制，每条命令只能引用上一条命令的结果，

分区 SensorManager服务相关 的第 1 页

实现：只需定义一个全局变量即可。也不算浪费空间。; 位于ROM固定位置，每条命令执行完后，将结果都放于此位置。; 浪费又麻烦; ● 每条命令都分配，使用完后释放。; 与第一种情况类似，区别是不占用ROM，而是RAM。为了方便，还是使用第一种方; 法吧。不用malloc。; ● 模块初始化时分配，模块卸载时再释放。; 动态从堆上分配空间，并将返回结果存入。; 返回结果如何存储？; 指针型返回结果的长度; 数据类型; 由引用符号决定，定义如下：; ● $P1 表示缓冲区中的数据是以一个字节为单位的，例如char*类型; ● $P2 表示缓冲区中的数据是以两个字节为单位的，例如int16*类型; Tips：暂不支持结构体类型; ● $p4 表示缓冲区中的数据是以四个字节为单位的，例如int32*类型; 缓冲区长度; 很容易出错。; 冲区长度。; 虽然会浪费一个字节，但是不容易出错，比如缓冲区越界访问。; ► 在缓冲区第一个字节指定缓冲区的大小。; 的缓冲区的长度以及数据类型(char*、int*)？; 返回结果的引用; 在命令中用 $ 字符代表上一条命令的返回结果。; 为指针的话。; ► GPIO ● GPIO R GPIONumber; 参数说明：; R/W 表示读或者写GPIO端口，R表示Read，W表示Write; State: 只在输出有效，表示GPIO输出状态，0表示低，1表示高电平 返回结果：; Read返回当前输入状态，Write返回当前输出状态; ● GPIO W GPIONumber State; ► I2C ● I2C busNum R/W slvAddr subAddr data……; ：表示读取或者写入; slvAddr; ：I2C设备从地址; subAddress：设备子地址; ► 数学运算; 需要注意的是，运算操作类似forth语言。请参考forth语言编程指南。; ● 支持常用的数学运算符，+、-、*、/、|、&、~、^（求反）; ► 逻辑运算; 命令列表

由命令决定。每条命令具体返回多少数据，在命令手册中指定，然后引用者必须确保不会超过缓

数据型返回结果固定为4字节，但是对于返回缓冲区指针的指针型返回结果，如何确定其所指向

$P 表示以指针的方式来引用返回结果，后面跟数字表示指针类型，具体参考指针引用数据类型 $D 表示以数据的方式来引用返回结果，即将返回结果强制转换为数据，如果上一条命令的返回结果

- GPIONumber GPIO端口号。0~31，但是有些端口用途已固定，无法使用GPIO。具体哪些可以端口请参考引脚资源图 (https://github.com/xiaogan-Studio/OpenCloudEnvMonitor/blob/master/Doc/hardware/%E7%AE%A1%E8%84%9A%E8%B5%84%E6%BA%90.xlsx)
- | busNum | : 表示I2C总线号，目前支持两路I2C，所以busNum的取值为0,1
- | Data | ：要写入的数据。当为Read时，表示连续读取多少次；当为Write时，表示要写入的数据

分区 SensorManager服务相关 的第 2 页

● && || ！ 与C语言一致 ► 流程控制语句; ● LOOP n expression

- IF $D expression：根据上一条语句的执行结果，判断本条语句是否执行。当为True时，才执行。

循环执行本条语句。n表示执行次数，n为0表示不执行。expression表示要执行的语句

分区 SensorManager服务相关 的第 3 页

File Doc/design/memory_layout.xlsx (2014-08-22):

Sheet: 内部Flash Layout
SoftDevice | 0x0 | 80KB Nordic蓝牙协议栈
 | 0x00013FFF
Firmware | 0x00014000
 |  | 156KB系统固件
 | 0x0003AFFF
Bootloader | 0x0003B000 | 19KB BootLoader
 | 0x0003FBFF
Config Data | 0x0003FC00 | 1KB Configuration Data
 | 0x0003FFFF

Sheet: 1-Wire EEPROM Layout
Size | 0x0
 | 0x01
UUID | 0x2
 | 0x3
sensorType | 0x4
 | 0x4
busType | 0x5
 | 0x5
address | 0x6
 | 0x6
dataLength | 0x7
 | 0x7
保留 | 0x8
 | 0x8
detach CMD Size | 0x9
 | 0x9
capture CMD Size | 0xa
 | 0xa
attach CMD Size | 0xb
 | 0xb
Attach CMD | 0xc
Capture CMD
Detach CMD

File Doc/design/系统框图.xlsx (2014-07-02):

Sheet: 简介
简易系统框图

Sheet: EnvMonitor MainBoard框图
 |  | 上图中，蓝色虚线框表示EnvMonitor主控板，深蓝色小方块表示是EnvMonitor板载资源。
 |  | 橙色的线表示从EnvMonitor引出的外部接口，黑色的线条则是EnvMonitor内部的连线。
 |  | 深红色的方框表示传感器模块。
☆ | EnvMonitor主控板与Sensor模块通信方式
 | EnvMonitor主板与Sensor Board的数据通信，有I2C和ADC两种，以I2C为主。EnvMonitor预留有两路I2C，最大接入设备限制为10个。
 | 如上图所示，每个Sensor Board上有一个I2C中继器，用紫色方块表示。同时，在EnvMonitor一端也有中继器。目的有两个：
 | ● | 减少设备之间的干扰和降低总线电容特性
 | ● | 热拔插。在总线通信的过程中，可以接入其他设备，而不会影响总线通信。
 | 每个Sensor Board的配置信息都写入在Sensor Board板载的EEPROM中，并且EnvMonitor通过单总线读取这些信息。
 | 配置信息主要包括如下一些分类，但是不限于这些:
 | ● | 传感器类型：标示采集何种环境信息。
 | ● | 通信类型：I2C还是ADC
 | ● | 通信地址：对于I2C通信方式就是I2C从机设备地址。ADC就是所使用的ADC编号。
 | ● | 通信频率：多久需要EnvMonitor采样一次数据。
 | ● | 通信数据量：每次通信的数据的长度
 | ● | 通信命令：由于不同的传感器，采集数据的命令可能不一致，此处保存采样命令。对于I2C，就是需要读写哪些寄存器才能或得数据。而对于ADC则是采样的ADC值与实际物理量之间的转换关系。
 | ● | 校验码：对存储在设备中的配置信息的校验。防止意外更改。
 | 对于ADC，只是作为备用通信方式使用。当以模拟量为输出的传感器的个数比较少，可以直接考虑使用ADC总线。
☆ | EnvMonitor数据暂存方案
 | 考虑到NRF51822本身只用256KB ROM，而且蓝牙协议栈占用了固定的80KB，只剩下176KB的空间。当设备离线时，根本不够保存采集到的环境数据。
 | 故增加一块SPI Flash，保存一定时间的离线数据。
 | 最小容量，有待计算。
☆ | EnvMonitor GPIO
 | ● | 彩色LED留2个。
 | ● | 预留一个按键
 | ● | 剩余GPIO全部引出，并且有一半上拉，一半下拉。或者上下拉都有，焊接时确定使用哪个，方便调试。

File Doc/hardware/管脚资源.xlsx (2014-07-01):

NRF51822管脚配置表 QFN48封装
 |  |  |  |  |  |  |  | OpenCloudEvnMonitor
管脚位置 | 管脚名称 | 复用功能 1 | 复用功能 2 | 复用功能 3 | 描述 | 注意事项 | 输入/输出 | 用途 | 默认状态 | 上拉/下拉 | 其他考虑 | 描述
1 | VDD | 电源输入 | 无 | 无 | 供电引脚 Power Supply |  | - | POWER | -
2 | DCC | 电源 | 无 | 无 | DC/DC output voltage to external LC filter. |  | - | DC/DC Output | -
3 | P0.30 | GPIO | 无 | 无 | 通用IO口 |  | 输出 | Debug LED2 | - | 无
4 | P0.00 AREF0 | GPIO | ADC/LPCOMP参考输入 AREF0 | 无 | 模拟输入和低功耗比较器的输入参考电压 |  | 输入 | ADC 输入参考电压 | - | 无
5 | P0.01 AIN2 | GPIO | ADC/LPCOMP输入2 AIN2 | 无 | ADC/LPCOMP 输入 |  | 输入 | ADC总线 AIN1 | - | 无
6 | P0.02 AIN3 | GPIO | ADC/LPCOMP输入3 AIN3 | 无 | ADC/LPCOMP 输入 |  | 输入 | ADC总线 AIN2 | - | 无
7 | P0.03 AIN4 | GPIO | ADC/LPCOMP输入4 AIN4 | 无 | ADC/LPCOMP 输入 |  | 输入 | ADC总线 AIN3 | - | 无
8 | P0.04 AIN5 | GPIO | ADC/LPCOMP输入5 AIN5 | 无 | ADC/LPCOMP 输入 |  | 输入 | ADC总线 AIN4 | - | 无
9 | P0.05 AIN6 | GPIO | ADC/LPCOMP输入6 AIN6 | 无 | ADC/LPCOMP 输入 |  | 输入 | 电池电压采样 ADC For Battery | - | 无
10 | P0.06 AIN7 AFRE1 | GPIO | ADC/LPCOMP输入7 | ADC/LPCOMP参考输入1 | ADC/LPCOMP 输入或者其输入参考电压 |  | 输出 | 锂电池供电控制 VDD_Li_EN | - | 无 |  | 高电平使能锂电池供电 低电平关闭锂电池
11 | P0.07 | GPIO | 无 | 无 |  |  | 输出 | I2C0 SCL信号 | High | PullUp
12 | VDD | 电源输入 | 无 | 无 | Power Supply |  | 输入 | POWER | - | -
13 | VSS | 电源 | 无 | 无 | Groud（地） |  | - | GND | - | -
14 | P0.08 | GPIO | 无 | 无 | GPIO |  | 输出 | I2C0 SDA信号 | High | PullUp
15 | P0.09 | GPIO | 无 | 无 | GPIO |  |  | GPIO | High | PullUp
16 | P0.10 | GPIO | 无 | 无 | GPIO |  |  | GPIO | High | PullUp
17 | P0.11 | GPIO | 无 | 无 | GPIO |  |  | GPIO | High | PullUp
18 | P0.12 | GPIO | 无 | 无 | GPIO |  |  | GPIO | High | PullUp
19 | P0.13 | GPIO | 无 | 无 | GPIO |  |  | GPIO | High | PullUp
20 | P0.14 | GPIO | 无 | 无 | GPIO |  |  | GPIO | High | PullUp
21 | P0.15 | GPIO | 无 | 无 | GPIO |  | 输出 | SPI SCK for SPI Flash |  | 无
22 | P0.16 | GPIO | 无 | 无 | GPIO |  | 输出 | SPI MOSI For SPI Flash
23 | SWDIO nRESET | RESET(低有效) | Debug接口 | 无 | DEBUG Interface |  |  | SWD Debug IO/ RESET Key |  | PullUp |  | 内部有上拉
24 | SWDCLK | SWDCLK Debug时钟输入 | 无 | 无 | DEGUB Interface |  | 输入 | SWD Debug Clock |  | PullUp |  | 内部有上拉
25 | P0.17 | GPIO | 无 | 无 | GPIO |  | 输入 | SPI MISO for SPI Flash
26 | P0.18 | GPIO | 无 | 无 | GPIO |  | 输出 | SPI Flash写保护 nSFLASH_WP | low | PullDown |  | R55 10K下拉
27 | P0.19 | GPIO | 无 | 无 | GPIO |  | 输出 | I2C1 SCL 单总线 | High | PullUp
28 | P0.20 | GPIO | 无 | 无 | GPIO |  |  | I2C1 SDA 单总线 | High | PullUp
29 | DEC2 | Power decoupling | 无 | 无 | 电源去耦用接口 |  | - | 去耦电容
30 | VDD_PA | Power Output | 无 | 无 | Power supply output (+1.6 V) for on-chip RF power amp |  | 输出
31 | ANT1 | RF | 无 | 无 | Differential antenna connection (TX and RX). |  | 输出 | 天线
32 | ANT2 | RF | 无 | 无 | Differential antenna connection (TX and RX). |  | 输出 | 天线
33 | VSS | 电源地 | 无 | 无 | Ground（0V） |  | 输入 | POWER
34 | VSS | 电源地 | 无 | 无 | Ground（0V） |  | 输入 | POWER
35 | AVDD | 模拟电源输入 | 无 | 无 | Analog Power supply |  | 输入 | POWER
36 | AVDD | 模拟电源输入 | 无 | 无 | Analog Power supply |  | 输入 | POWER
37 | XC1 | 晶振输入 | 无 | 无 | 16/32MHz晶振或外部16/32MHz时钟输入 |  | 输入 | 16MHz晶振
38 | XC2 | 晶振输出 | 无 | 无 | 16/32MHz晶振输出 |  | 输入 | 16MHz晶振
39 | DEC1 | Power decoupling | 无 | 无 | 电源去耦用接口 |  | - | 去耦电容
40 | P0.21 | GPIO | 无 | 无 | GPIO |  | 输出 | 外扩总线电源控制 VDD_CON_CTL |  |  |  | 高电平打开电源 低电平关闭电源
41 | P0.22 | GPIO | 无 | 无 | GPIO |  | 输出 | 单总线芯片供电控制 VDD_1Wire_CTL |  |  |  | 高电平打开电源 低电平关闭电源
42 | P0.23 | GPIO | 无 | 无 | GPIO |  | 输出 | SPI Flash供电控制 VDD_Flash_CTL |  |  |  | 高电平打开电源 低电平关闭电源
43 | P0.24 | GPIO | 无 | 无 | GPIO |  |  | GPIO
44 | P0.25 | GPIO | 无 | 无 | GPIO |  |  | GPIO
45 | P0.26 AIN0 XL2 | GPIO | ADC/LPCOMP输入0 | 32.768KHz晶振输出 |  |  |  | GPIO
46 | P0.27 AIN1 XL1 | GPIO | ADC/LPCOMP输入1 | 32.768KHz晶振输入 | 32.768KHz晶振或外部32.768KHz时钟输入 |  |  | GPIO
47 | P0.28 | GPIO | 无 | 无 | GPIO |  | 输入 | 升级按键 | High | PullUp
48 | P0.29 | GPIO | 无 | 无 | GPIO |  | 输出 | Debug LED1

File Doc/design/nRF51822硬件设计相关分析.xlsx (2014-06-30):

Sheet: 电源方案选择
一、相关引脚介绍
可以分为如下类：
● | VDD | Input | 数字电源输入
● | AVDD | Input | 模拟电源输入
● | DEC |  | 内部LDO输出电源去耦用
● | DCC | Output | DC/DC模块滤波电路
● | VSS | Input | 电源地
● | VDD_PA | Output
二、nRF51822电源简介
nRF51系列芯片支持三种不同的电源输入方式：
 | ● Internal DC/DC Converter
 | ● Internal LDO
 | ● Low Voltage Mode
1.Internal DC/DC输入方式
 | 示意图如下（从Reference Manual中摘抄）
 |  |  |  | ☆ DC/DC降压模块可通过内部DCDCEN寄存器使能或禁能
 |  |  |  | ☆ DC/DC降压模块需要一个外部LC滤波电路，从DCC引脚接入
 |  |  |  | ☆ AVDD和VDD在CPU内部直接连接，当DC/DC禁能时。这样会在VDD和AVDD之间引入一个阻值很小的串联电阻。
 |  |  |  | ☆ DC/DC使用时机：
 |  |  |  | ☆ 输入电压范围：
2.Internal LDO输入
 | 示意图如下
 |  |  |  | ☆ 注意与DC/DC输入方式的连接区别，DCDCEN寄存器禁能DC/DC模块。并且VDD和AVDD在芯片外部就相连。
 |  |  |  | ☆ 输入电压范围：
3.Low Voltage模式
 | 示意图如下
 |  |  |  | ☆ 内部LDO被bypass，VDD直接给芯片内部供电。所以VDD必须确保稳定性。
 |  |  |  | ☆ 输入电压范围：
△电源输入电压VDD Setup Time（最大值）
三、方案对比及选择
 | ☆ 输入电压范围对比
 | △ 建议三种方式都留着位置，等板子做好后，调试下，看看哪种情况最省电。
 | △ 这三种方式，如果可以通过两个I/O口控制会更好。到时候可以动态切换。
四、电源草案
 | 使用三种输入方式动态切换。ADC采样电池电量，决定使用哪一种方式。
 | □ 默认状态是哪种？或者寻找可以记住状态的开关？
 | □ 在开发板上测试切换
 | □ 计算功耗，如果功耗大，是否可以考虑预留直流电源接口（不使用电池）
 | □ 考虑IO电平。当VDD低于1.9V时，IO口最大才输出1.9+0.3=2.2V，正好是TTL电平的阀值。是否需要使用1.8V的器件？
☆ | 由于考虑到功耗和使用时间，电源准备使用可充电电池，输出为3~4.2V。使用DC/DC输入方式。
 | TODO: | 上图中电感电容计算：

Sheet: 硬件模块化探讨
一、需求
 | ○ 热拔插，自动侦测设备状态。是否有设备插入或拔出。
 | ○ 自动识别传感器类型
 | ○ 传感器模块上不希望使用MCU。如果能使用MCU，还不如直接集成到一块板子上。
二、拔插检测方案探讨
☆ | ADC检测模块的分压电阻。
 |  | …
☆ | 1-Wire总线方案
三、 | 方案选择
 | 使用单总线的形式，每个Sensor Board都添加一个EEPROM用来标示自己。

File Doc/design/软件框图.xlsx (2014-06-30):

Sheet: 目录
目录
EnvMonitor System Overview
 | 各模块功能简介

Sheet: EnvMonitor整体功能拆分
一、EnvMonitor系统功能划分简图
 | 上图中的方块表示系统中的一个功能模块，负责处理某些特定的事情。各模块之间的虚线表示模块之间的依赖关系
 | 根据项目情况，将系统拆分为22个子模块，每个模块的介绍及功能如下
二、各模块功能简介
 | 1.Bootloader模块
 |  | ●判断系统有效性，并启动系统主模块Main。
 |  |  | 计算固件的校验码，并跟Flash中保存的校验码比较。若一致，则启动Main模块。如果不一致，则尝试启动保存在SPI Flash中的固件。
 |  |  | 若两个固件都无效，则调用SystemDebug模块提示用户启动失败。
 |  | ●升级系统固件。
 |  |  | 如果在启动Main模块之前，用户押按Boot按键，则进入升级模式。支持蓝牙和串口升级。
 |  |  | 固件在NRF51822 Internal Flash和外部SPI Flash中各保存一份。这样做为了防止升级失败后，系统无法正常启动。
 | 2.PinMuxCfg模块
 |  | 负责记录每个管脚的功能，比如串口的TX使用哪个管脚。
 |  | 讨论：是否提供动态切换的功能？
 | 3.SystemDebug模块
 |  | 系统调试模块，负责系统调试信息输出。输出方式有三种：
 |  | ●串口输出
 |  | ●蓝牙输出
 |  | ●彩色LED灯：通过两个彩色LED灯的不同颜色和不同频率，来提示系统运行情况。
 | 4.Main模块
 |  | ●调用Initializer模块，初始化系统所有子模块；
 |  | ●启动Scheduler模块，开始所有系统服务。系统有四个服务：
 |  |  | ＊传感器状态监测服务：由SensorManager模块提供。主要提供如下功能：
 |  |  |  | ○ 负责SensorBoard拔插检测；
 |  |  |  | ○ SensorBoard配置信息读取解析，并将SensorBoard的状态写入到SPI Flash中；
 |  |  |  | ○ 向数据采集服务注册或注销传感器采集请求。
 |  |  | ＊数据采集服务：从传感器采集数据，并保存到SPI Flash中。由SensorCapture模块提供。
 |  |  |  | ○ 根据数据采集请求队列中的请求，向相应传感器发送采集命令采集数据；
 |  |  |  | ○ 将采集来的数据转换为实际物理量，并保存到SPI Flash中。
 |  |  | ＊数据上传服务：将保存在SPI Flash中的数据上传给server，由SensorUpload模块提供。
 |  |  | ＊数据查询服务：分析用户从蓝牙或者串口发送过来的查询命令，并将结果返回。由SensorQuery模块提供
 | 5.Scheduler模块
 |  | 负责任务调度。时分复用，优先级排序。
 |  | 讨论：如何在Nordic SDK的基础上实现scheudler
 | 6.Initializer模块
 |  | 负责系统所有子模块的初始化任务（除了Main模块和Bootloader模块）
 |  | 讨论：如何简单且统一得初始化所有模块？
 | 7.I2C Driver模块
 |  | 提供访问I2C总线的函数。
 | 8.SPI Driver模块
 |  | 操作SPI总线的函数。
 | 9.ADC Driver模块
 |  | 从ADC总线上读取传感器数据
 | 10.GPIO Driver模块
 |  | 操作GPIO的函数的总和
 | 11.UART Driver模块
 |  | 操作串口的模块
 | 12.BLE Services Driver模块
 |  | 抽象Nordic BLE Stack提供的服务，提供统一简单的接口给其他模块使用
 | 13.oneWire Driver模块
 |  | 单总线驱动模块。
 | 14.SPI FlashDriver模块
 |  | 管理SPI Flash设备，抽象出统一的Flash读写函数
 | 15.DataCapture模块
 |  | 数据采集模块。抽象隔离I2C总线和ADC总线的差异，为其他模块提供统一接口。
 | 16.DataStorage模块
 |  | 数据管理模块，管理和组织所有SPI Flash上的数据。
 |  | 讨论：FATFS的可行性。主要限制是Internal Flash 和 SRAM的大小，寻找对内存和Flash要求都比较低的库。
 | 17.BoardManager模块
 |  | SensorBoard管理模块，负责读取和解析SensorBoard的配置信息，并写入到SPI Flash中备份。同时，为SensorManager提供设备状态查询接口。
 | 18.ConfigParser模块
 |  | SensorBoard配置信息解析模块，对其他模块隐藏板子的配置信息存储方式及每个字节的含义。
 | 19.SensorManager模块
 |  | 定时查询SensorBoard的连接情况，实时更新存储在Flash中的SensorBoard的状态信息。并向SensorCapture服务注册数据采集请求
 | 20.SensorCapture模块
 |  | 数据采集模块。按照指定的频率从指定的传感器采集指定的数据。
 | 21.SensorUpload模块
 |  | 定时向Server发送采集到的传感器数据
 | 22.SensorQuery模块
 |  | 接收从串口或蓝牙发送的数据查询命令，执行并将结果返回给server。

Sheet: Sequence Diagram
一、用户升级
二、固件启动
三、

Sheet: Scheduler模块详细设计
一、方案探讨
 |  | 预设的四个系统服务：
 |  | 名称 | 优先级 | 运行周期(ms) | 备注
 |  | SensorManager | 2 | 2000 | 考虑到实际应用时，用户动态插入采集板的概率很低，2分钟运行一次多有点多。
 |  | SensorCapture | 1 | 100 | 采样频率尽量快，为了能较好的还原数据动态曲线，每秒采集10次数据
 |  | SensorUploader | 3 | 1100 | 由于有本地数据备份，运行周期可以相对长一些，但是当存储空间不足时，应该缩减运行周期
 |  | SensorQuery | 4 | 1300 | 每秒响应一次用户查询命令
 |  |  |  |  |  | SensorCapture
 |  |  |  |  |  | SensorUploader
 |  |  |  |  |  | SensorQuery
 |  |  |  |  |  | SensorManager
 | ☆调度原理分析
 |  | 基于Nordic SDK中app_timer实现四个服务的调度，先看下app_timer的实现

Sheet: SensorManager模块详细设计
一、SensorManager需求
 | ○ SensorBoard配置信息
 |  | □长度：整个配置的总长度，以字节为单位.uint32 → SensorManager不需要知道
 |  | □传感器类型：char
 |  | □总线地址：目前准备支持I2C总线 char
 |  | □设备地址：char
 |  | □数据长度:以字节为单位的数据长度。char
 |  | □Attach命令：插入时，需要执行的命令，用来初始化设备
 |  | □Capture命令：每次采集数据时，需要执行的命令
 |  | □Detach命令：卸载时，执行的命令，当系统电源不足，需要关闭某些设备时，执行该命令卸载设备。
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

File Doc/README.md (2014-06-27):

#目录介绍
## design目录
一些设计相关的资料会放在这里，比如软硬件框图。

## hardware目录
硬件相关的资料，比如原理图、芯片的datasheet、协议等资料，还有一些开发板的资料。

## software
开发笔记，相关技术资料的翻译，各模块Review记录，代码静态检查等一些软件开发相关的资料。

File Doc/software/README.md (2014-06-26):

#目录介绍
## Note
主要收集整理一些软件开发中遇到的问题，或者开发需要涉及的资料的翻译及分析。

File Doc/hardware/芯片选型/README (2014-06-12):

注意点：

  1. 由于将传感器模块独立化，与nRF51822主控板的主要通信方式为I2C和ADC。
     所以选型时，尽量选择有I2C接口的传感器。没有的话，寻找下是否有可用的转换到I2C的芯片。
     
  2. 功耗。选型时注意芯片的功耗，尽量选择低功耗的。因为系统是使用电池供电的。

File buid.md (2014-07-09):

**目录**
===============
- [开发环境](#建立开发环境)
- [编译](#编译)
- [下载](#下载)

-----------------------

#建立开发环境

EnvMonitor支持三种开发环境，这三种环境都支持Windows和Linux系统。

- Leo Editor开发环境

- Eclipse开发环境

- 命令行开发环境
  
##0. 交叉工具链
###0.1 Windows
Windows版本的交叉工具链，已经放在仓库中，不需要下载及安装。

###0.2 Linux
- [ ] TODO:添加Linux下交叉工具链的安装方法。

##1. Leo Editor

Leo编辑器是一款大纲编辑器，基于Python和QT开发。其最大的特点是文学编程和强大的扩展性。Leo官网是这样描述其自身的：
 
“Leo是一个可以帮组程序员、作家、网页设计者等人员加速其工作流程及工作效率的PIM工具、IDE、大纲编辑器。Leo独一无二的功能让你以革命性的新方式管理你的数据。”

[Leo官网链接地址](www.leoeditor.com),其中包含有Leo编辑器的教程。

由于Leo是基于Python和QT，要建立Leo开发环境，需要安装如下软件：

- python

- PyQt

- Leo Editor 

### 1.1 Windows
#### 1.1.1 安装Python

到[Python官网](https://www.python.org/downloads/)下载Windows版本安装软件。根据自己的喜好，下载Python3或者Python2，然后安装提示安装Python。

#### 1.1.2 安装PyQt
到[官网](http://www.riverbankcomputing.co.uk/software/pyqt/download)下载PyQt二进制安装包，并安装提示安装。注意需下载与你安装的Python版本相对应的PyQt安装包。

Tips：可以到[这里](http://www.mirrorservice.org/sites/pythonxy.com/)下载安装Python(x,y),该软件包含了Python，PyQt，iPython，numpy等一系列Python相关的常用工具。这是比较简单的安装方法。

#### 1.1.3 Leo Editor
到[官网](http://www.leoeditor.com/download.html)下载Leo。建议到[SourceForge](http://sourceforge.net/projects/leo/files/)上下载[Leo Windows安装包](http://sourceforge.net/projects/leo/files/Leo/4.11-final/LeoSetup-4.11-final.exe/download)

leo截屏

### 1.2 Linux
#### 1.2.1 Python

Linux常用发行版本中一般都会默认安装Python。

#### 1.2.2 PyQt

- Ubuntu：`sudo apt-get install python-qt4`

- gentoo: `emerge -av pyqt`

- fedora: `yum install python-qt`

#### 1.2.3 Leo

1. 到[这里](http://sourceforge.net/projects/leo/files/Leo/)下载Leo最新的稳定版,下载zip压缩包。
2. 解压缩到任何目录,uzip /path/to/leo-4.11-final.zip. 例如：将leo-4.11-final.zip下载到了~/download,则用如下命令解压：

    `cd ~/download`
   
    `unzip leo-4.11-final.zip`
3. 进入上一步解压缩的目录中，例如 `cd leo-4.11-final`，然后执行`sudo python setup.py install` 安装Leo。

##2. Eclipse
Eclipse的安装方法网络上已有很多，就不在此赘述了。但注意请安装Eclipse for C/C++版本。

##3. 命令行

- [ ] 添加Windows和Linux下使用的编译脚本

# 编译

# 下载

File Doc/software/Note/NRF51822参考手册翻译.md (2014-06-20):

# 14 GPIO Task and Event(GPIOTE)
## 14.1 功能描述
GPIOTE(GPIO Task and Event的简称)模块为开发人员提供了一种通过Task和Event来操作GPIO的功能。

Task可以对GPIO输出端口执行如下三种操作:
- 输出高电平;
- 输出低电平;
- 翻转输出状态，由高变为低或由低变为高。

通过GPIO Detect信号，Event可以被以下三种方式触发：
- 上升沿;
- 下降沿;
- 任意状态变化，即从高电平变为低电平或从低电平变为高电平;

### 14.1.1 Pin tasks and envents
GPIOTE模块有4个Task和4个Event，可以操作单个GPIO端口；用OUT[n] Task和IN[n] Event来表示，其中n<4。
Task可以用来操作单个GPIO输出端口的状态，而任何一个GPIO输入端口的状态变更都可以触发IN[n] Event

Tasks和Events由CONFIG[n]来配置。每一对OUT[n] Task和IN[n] Events共用一个CONFIG[n]寄存器。也就是说OUT[n] Task
和IN[n] Events的总数不能超过4。

GPIOTE模块和GPIO模块互斥，并且GPIOTE模块的优先级高于GPIO模块。一个GPIO端口如果被GPIOTE模块控制，
则GPIO模块就无法操作此端口，任何GPIO模块对该端口的操作都会被忽略，直到GPIOTE模块释放对该端口的控制权。

GPIO端口的初始状态可由CONFIG[n]寄存器的OUTINIT配置，当该端口被配置为Task。

### 14.1.2 PORT事件
PORT事件是一个可由多个GPIO输入端口来触发的一个事件，并且只能由GPIO Detect信号的上升沿来触发。请参考_13.1小节_
以便获取关于GPIO Detect信号更多的信息。

这个功能（PORT事件被触发）一直有效，尽管设备有可能处于空闲状态，换句话说，该功能不需要时钟和额外的电源。因此，
该功能可以用来将CPU从WFI、WFE类型的睡眠状态唤醒，当系统处于System ON并且所有外设和CPU都处于空闲状态，也就是
说System On模式下的最低功耗状态。

## 14.2 寄存器描述
寄存器概览 

### 14.2.1 CONFIG\[n\] \(n=0,1,2,3\)
CONFIG寄存器描述

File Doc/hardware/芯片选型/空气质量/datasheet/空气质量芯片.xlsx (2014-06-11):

型号
传感器增益
安装类型
宽度
封装类型
尺寸
引脚数目
接口类型
最低工作温度
最大工作电源电压
最小工作电源电压
最高工作温度
精确度
输出类型
长度
高度

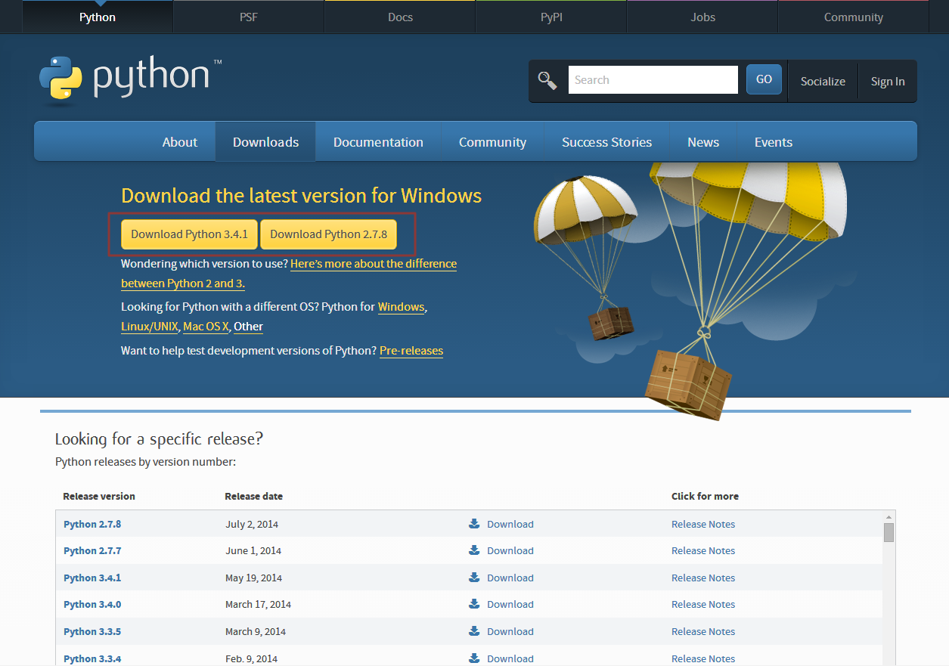
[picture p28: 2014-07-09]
Doc/res/python-website.png

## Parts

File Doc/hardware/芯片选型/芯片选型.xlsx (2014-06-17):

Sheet: 目录
目录

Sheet: 电磁辐射
一、目的：
 | 用来检测空气中的电磁辐射强度，为特殊人群提供参考信息。

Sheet: 毒性气体
一、目的

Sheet: 粉尘浓度
本来有找到另外一款SM-PWM-01A的传感器，但是没有找到DataSheet，所以就放弃使用。就不需要选型了。
GP2Y1010A粉尘检测传感器

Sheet: 温度
名称 | 精度（℃） | ADC分辨率 ℃/bits | 工作温度（℃） | 工作电压（V) | 功耗 | 转换时间 | 通信接口 | 封装 | 厂商 | 报价
~~AD595~~
~~LM35~~
~~MAX31855~~
~~MCP9700~~ | ~~±2(MCP9700A) ±4(MCP9700)~~ | ~~10mV/℃ 19.5mV/℃~~ | ~~-40~125 -40~150~~ | ~~2.3~5.5 3.1~5.5~~ | ~~6uA (typ.)~~ |  | ~~电压输出~~ |  | ~~MicroChip~~
TC74 | ±2(25~85℃) ±3(0~125℃) | 0.234/8 0.488/8 | -40~125 | 2.7~5.5 | 200uA(Operation) 5uA(shutdown) | 125ms | I2C | SOT-23/ TO-220 | MicroChip | ~5元
LM75AD LM75ADP | ±2 | 0.125/11 | -25~100 -55~125 | 2.8~5.5 | 1000uA(Operation) 35uA(shutdown) |  | I2C(400K) | SO8 MSOP8 | NXP | ~1元
SE95D SE95DP | ±1 | 0.03125/13 | -25~100 -55~125 | 2.8~3.6 | 1000uA(Operation) 7.5uA(shutdown) |  | I2C(400K) | SO8 MSOP8 | NXP | ~10元
SE98DP | ±2 | 0.125/11 | -20~125 | 3.0~3.6 | 250uA(Operation) 15uA(shutdown) |  | I2C(400K) | TSSOP8 | NXP | 淘宝很少卖，周立功有卖 | 8个地址 | DDR温度监控
~~NE1619~~ | ~~±3~~ | ~~1.0/8~~ | ~~-55~125~~ | ~~2.8~5.5~~ | ~~500uA(Operation) 100uA(shutdown)~~ |  | ~~I2C(400K)~~ | ~~QSOP16~~ | ~~NXP~~ | ~~10~20~~
DS1631 | ±0.5(0~70℃） | 12Bits | -55~125 | 2.7~5.5 | 1mA | 750ms(MAX) | I2C(400K) |  | MicroChip | 8~10
DS1731 | ±0.5(-10~70℃） |  |  |  | 1mA |  |  |  | MicroChip | 10~35
TMP102 | ±2(-25~80℃） | 12Bis | -40~125 | 1.4~3.6 | 10uA |  | I2C |  | TI | 5~10
TMP103 | ±3(-40~125℃） | 12Bits | -40~125 | 1.4~3.6 | 1.5uA |  | I2C |  | TI | 5~10 | 8个地址
目前暂定TI的TMP103芯片
低功耗且有8个I2C地址。

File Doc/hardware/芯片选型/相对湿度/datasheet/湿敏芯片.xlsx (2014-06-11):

型号 | SHT25 Humidity and Temperature | 6100 Series Humidity-Temperature | HIH-5030-5031 Low Voltage Humidity | SHT75/11/71 | HS1101LF
传感器增益 | 分辨率12位 | 分辨率14 位 |  |  | 湿敏电容 HS1101LF 为宽温度工作范围：-60---140度 且为环保型产品，符合欧美标准 HTF3223:用HS1101做的频率输出湿度模块，适用于需要精确可靠检测湿度的OEM用户，有很小的易于安装 的接头，可以非常节省成本的机械自动安装。由于它是线性的频率输出湿度检测模块，因此可以 直接与微处理器相接，HTF3223比HF3223多一个热敏电阻在PCB板上用于温度测量，采用专利电容HS1101设计制造 宽量程：10~95%RH，稳定，比例线性的频率输出 精度±5%RH ，工作温度范围 –40~80℃ 可选的10KΩ+/-3% NTC 温度传感器（HTF3223）
安装类型 | 表面贴装 | 表面贴装 | 表面贴装 | 通孔
宽度 | 3mm | 1.905mm | 4.17mm | 5.08mm
封装类型 | DFN | SOIC | 表面安装器件 | DIP-4
尺寸 | 3 x 3 x 1.1mm | 4.9 x 3.9 x 1.905mm | 8.59 x 4.17 x 2.67mm
引脚数目 | 6 | 8 | 3 | 4
接口类型 | 串行 - I2C | I2C |  | 表面安装器件:：单列直插
最低工作温度 | -40 °C | -25 °C | -40 °C | -40°C
最大工作电源电压 | 3.6 V | 5.5 V | 5.5 V | 2.4V DC 至 5.5V DC
最小工作电源电压 | 2.1 V | 2.3 V | 2.7 V
最高工作温度 | +125 °C | +85 °C | +85 °C | 123.8°C
精确度 | ±1.8%RH | ±4%RH | ±3%RH | ±1%
输出类型 | 数字 | 数字 | 模拟
长度 | 3mm | 4.9mm | 8.59mm | 3.1mm
高度 | 1.1mm | 1.905mm | 2.67mm | 3.1mm
备注 |  |  | 纯粹湿度传感器

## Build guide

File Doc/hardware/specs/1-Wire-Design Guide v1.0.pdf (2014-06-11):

# SPRINGBOK DIGITRONICS

# Innovative Hardware and Software for the modern world

# Design Guide v1.0

# 1-Wire

# FFAAQQ

INNOVATIVE HARDWARE A N D SOFTWARE

# Understanding 1-Wire Series

## Credits:

Much of this document was taken from papers written by Dan Awtrey. In particular, our thanks to Dan for sharing his recent private papers, without which this document would not have been created.

## Standard Document Format

Use of Icons: Through out this document you may find various help icons. By clicking on the icon you will be linked to information about each category of information. Valuable information may include links to datasheets, manuals and other reference material. Contact information is assumed to be names and addresses of people and companies. Internet links are hyperlinks to reference documents available on the Internet; quite often they are original sources for public information like data sheets. Always consult these links for the latest information from other companies.

MORE I N FO
Valuable information
Contact information

Internet links

Application notes

- Springbok Digitronics

# Table of Contents

STANDARD DOCUMENT FORMAT | I

The Reset Sequence with Reset Pulse and Presence

What sort of cable should we use to make our

Example 2 - With a single 1-Wire slave at the end

Example 3 - With one slave at midpoint and a

Calculating the slowest slew rate - example........34

Review of how 1-Wire communications works......54

Inductance and NEXT (Near-End Crosstalk)......80

FINAL THOUGHTS - A GENERAL REMARK... 95 Contact info to the authors and contributors.......95

# A design guide for the layman: understanding, designing and building MicroLan™ (1-Wire)

networks.

# Or an introduction to everything you wanted to know but didn’t know

enough to ask.

# Chapter

1

DESIGN GUIDE – INTRODUCTION TO 1- W I RE NETW ORK ISSUES

# OOvveerrvviieeww

Our doubts are traitors, And make us lose the good we oft might win, By fearing to attempt. – William Shakespeare,Measure for Measure

## Introduction

### What is 1-Wire?

The 1-Wire® network, originally known as a MicroLAN™, as defined by Dallas Semiconductor (http://www.maxim-ic.com/1-Wire.cfm) is a communication system between electrical devices. It consists of three main elements: the 1-Wire interface called a bus master, slave devices, and the electrical connection between the bus master and slave devices.

Taking a quick
look at 1-Wire.

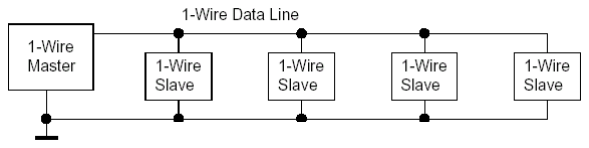
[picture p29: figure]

Figure 1. Drawing of a 1-Wire network with 1 bus master and 4 slaves In many ways it’s similar to a very old fashion party line telephone system. In a party line telephone communications system, one person places a call to another. The caller or the originator of the call (known as the 1-Wire bus master) dials onto the communications network (the 1-Wire network). The signal (traveling through wires) may be first routed through a switch at a central office (Not shown in above drawing), where it is routed to the correct party line. This can be done using what is known as MicroLan hubs in the case of a 1-Wire system. All members of the party line (this is known as multi-drop capability) receive the rings of the incoming call. The number of rings (the address) tells you which person (a slave device) should answer the call. Like a telephone conversation, where one person talks while the other listens, the bus master tells the slave(s) who answer the call what it wants. It can ask for information or tell it what to do. And the person (the slave device(s)) on the other end of the phone listens to what is said and responds. Like a telephone conversation if both people were to talk at the same time, they could not understand one another, the same holds true for 1-Wire communications. So in the case of a 1-Wire system it is up to the calling system (the bus master) to control the conversation

Version 1.0 8/19/04 | 4

### A more technical description

All 1-Wire communications takes place digitally (on or off logic states), over a wire cable (typically twisted pair). The network is defined with an open drain (wired-AND) master/slave multi-drop architecture that uses a resistor pull-up to a nominal 5 Volt supply at the master. We will talk later more about this pull-up resistor and the important part it plays later in this document.

The master device initiates and controls all activities on the network bus. This is why it is known as the bus master. The bus master acts as a protocol and timing interface between a PC or microcomputer and the 1-Wire network. Both the bus master and all slave devices internally act as transceivers. These are devices that can both send and receive data on a single data line. You can think of this single communications line as a single lane road, where traffic takes turns, first going one way, then the other. So data can flow in either direction, but only one direction at a time (half duplex operation). Data transfers are bit sequential with the least significant bit of a byte being transmitted first, over a single pair of wires, a data and a ground return line. Synchronizing of the devices is handled by the 1-Wire data protocol (regulating who talks and who listens at any given time). This allows tight control of the data bus because the protocol allows no slave to speak unless requested by the master, and then communication is only allowed between the selected slave and the bus master; no communication is allowed slave to slave.

## The Signals

In order to understand how all this works and the implications for a network design we have to delve deeper into our understanding of the data signals used, the protocol and the effects of how we interconnect the various elements, on the data signals. Since we know the 1-Wire information is transmitted digitally, let’s start by taking a quick look at the logic levels used in 1-
Wire components.

What voltages
define the 1-Wire
signals?

### The Logic Levels

A 1-Wire network’s logic levels are roughly compatible with conventional CMOS/TTL logic levels, with an approximate1 maximum 0.8V (known as the V
IL MAX) for logic “zero”
and an approximate minimum 2.2V (known as VIH MIN) for logic “one”. In the region between these two voltages, the logic level is indeterminate. Consequently any signal transi-

Logic0Area

Indeterminate Area

Logic 1 Area

0 volts

2.2

.8v

5 volts

Version 1.0 8/19/04 | 5

1 Approximate values are given because this varies slightly according to the 1-wire slave devices used. Consult your device datasheets.

tions through this area should ideally be fast since the logic state is undefined in this region.

### Defining the 1-Wire bus lines

What are the two The Data or OWIO line lines in a 1-Wire
network called?

The actual 1-Wire data signal line is commonly marked as the DQ, Data or OWIO (One Wire I/O) line. In this document, we will use the name OWIO or data line interchangeably when referring to this line. Though the actual voltage on this line changes as the logic level changes, for the purposes of this document it will be assumed to be a signal falling between 0 and 5 volts, and operating at a frequency of up to 1MHz. (1µs pulse duration) This signal carries the bi-directional data based on the 1-Wire protocol. The name 1-Wire is derived from the fact only 1 wire is used to carry communications in both directions. The actual data bit stream is read as a series of discreet timed events defined by the 1-Wire protocol.

The Ground return or OWRTN line

The ground return line
The second line of the 1-Wire network is the 1-Wire signal return line (or ground return). Again it is commonly marked as GND or Return or OWRTN. We will use the nomenclature OWRTN (One Wire Return) or return for this line. Though this line is often at ground level it should NOT be confused with a true ground in that it may or may not be tied to a true earth ground level depending on the system. There is only one ground point in a 1-Wire network, and that is done at the 1-Wire bus master device.

### The Pull-Up resistor

A resistor typically connects the data line of the 1-Wire network to the 5V supply of the bus master (this acts as a “resistive” or “weak” pull-up). So the data line is constantly being pulled towards the logic 1 state by this weak pull-up resistor. By means of their open-drain output (think of it as a switch that can be closed to ground) the master and slaves can short-circuit the data line (over coming the weak-pull-up resistor) to the ground reference to change the logical state from a 1 to a 0. So the non-transmitting or default idle state of the bus is a logic 1 or high level (≥2.2 volts). And the transmitting state is a logic 0 or low level (≤.8 volts,). This defines the bus as what as known as an inverted logic bus.

What is the pull-up
resistor and what
function does it
perform?

1-Wire Data

Resistor

+5V

Version 1.0 8/19/04 | 6

While the bus is in the default idle (high or logic 1 state), a small amount of current (power) limited by the size of the pull-up resistor is available to slave devices during that time. This fact is used in the clever design of 1-Wire components to power the interface logic of slave devices. The high level charges a small internal capacitor (typically 800pf) in the slave device, which can hold enough reserve power for slave operations while the bus is in a low state. In other words it acts as a small battery for the device. Since its energy storage capacity is small, it must be recharged constantly or the device will lose too much power (the battery dies) and turn off.

Some devices are able to use only this power for all their normal operations and are known as true parasitic devices (they draw their power from the data signal line only). Other more power hungry 1-wire devices require additional power sources for their operation. But all 1-wire slave devices use this parasitic power for their fundamental 1-wire interface power.2

The resistance value
The pull-up resistor value must be low enough to provide sufficient current through it to power devices on the bus, but not so low that the open drain slaves are unable to successfully pull the data line down to a logic 0 level.

Slave devices are typically able to pull the bus line down to about 0.4 volts when faced with 4 ma of pull-up current due to their internal resistance of approximately 100 ohms. Any additional resistance (due to wiring or other devices) will limit this ability even more. This defines what is referred to as the base floor for logic 0 states. As you may have recognized from this the theoretical noise immunity has been cut in half. To only 0.4 volts (0.8 -0.4 = 0.4 volts)

Typical values for the pull-up resistor are between about 1K ohms to 4.7K ohms. This sets the current range to between 5 ma and 1.06ma. A DS2480B (DS9097, etc) based bus master’s range is between 1.5-5ma, and is typically 3 ma3. The LINK bus master (a more advanced design) weak-pull-up is about 4.93ma by comparison4.

While this weak pull-up current (the power source for the data line) is adequate for powering small 1-Wire nets, large networks or networks with parasitic device (explained latter in this document) may require additional pull-up current at times. This is known as the active pull-up current. The DS2480B can increase it’s pull-up current

2 This is why slave devices may show up on the 1-wire bus even if they are not connected to any other power device.

3 Consult the Dallas semiconductor DS2480B datasheet (http://pdfserv.maxim-ic.com/en/ds/DS2480B.pdf) for actual values

4 Calculated from the Link (http://www.ibuttonlink.com/) schematic. Note the Link uses an out of spec higher logic 0 level to increase the noise immunity at the bus master.

Version 1.0 8/19/04 | 7

to 9-15ma while the LINK can generate as much as 47.08 ma. Consult your manufacturer’s datasheets for details on these and other bus master devices.

## The 1-Wire Protocol

Now that we know about the 1-Wire signal levels used, let’s take a closer look at how the 1-Wire protocol allows you to transmit and receive data at a signal level. 1-Wire signals require a strict protocol to insure data integrity. The bus master as we said before, initiates all communications on the bus. The basic 1-Wire protocol consists of four types of signaling on the data or OWIO line: These are

How does it work?

### 1. Reset Sequence with Reset Pulse and Presence Pulse

The reset pulse is used to put all devices on the 1-wire bus into a known state. When a slave, or slaves, sees the Reset Pulse, they acknowledge receipt by returning a Presence Pulse to indicate their “presence” or existence in an active state on the bus.

### 2. Write 0

Send a ‘0’ bit to the 1-Wire slaves (Write 0 time slot).

### 3. Write 1

Send a ‘1’ bit to the 1-Wire slaves (Write 1 time slot)

4. Read Data

Read data sequences are similar to the write 1 time slot but the bus master samples the bus state after it releases the line to read data back from a slave device. In this manner it is able to read back either a 0 or a 1 from the slave.

Lets take a closer look at each of these signals and see exactly how they are done.

Version 1.0 8/19/04 | 8

### The Reset Sequence with Reset Pulse and Presence Pulse

The initialization sequence required to begin any communication with a slave device is shown below. It starts out when the bus master transmits the negative going Reset Pulse (TX) of tRSTL µs duration.

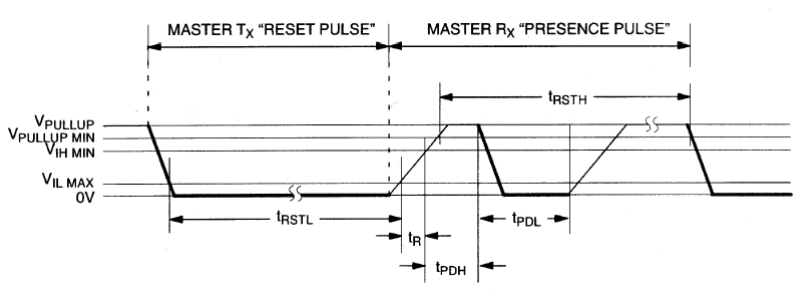
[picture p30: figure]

Figure 2. Reset Sequence with reset pulse and presence pulse. The bus master then releases the line and goes into receive mode (RX). The 1-Wire bus is pulled back to a high state via the pull-up resistor. After detecting the rising edge on its data line, any slave device on the bus will wait (tPDH) µs and then transmit a Presence Pulse (tPDL) back to the bus master. The line is again pulled back (if needed) to its high state via the pull-up resistor.

In this way the bus master is able to detect if any 1-Wire slave devices are on the bus.

But what does this look like in the real world? Let’s take a look at an oscilloscope image of a real Reset sequence waveform.

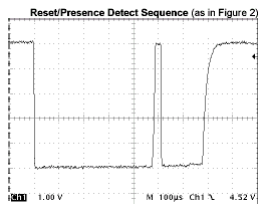
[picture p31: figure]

Figure 2a. You can clearly see the negative going reset and the presence pulse

Version 1.0 8/19/04 | 9

### Writing data

A write time slot is initiated when the bus master pulls the data line from a high (inactive) logic level to a low logic level. There are two types of write time slots: Write 1 time slots and Write 0 time slots. All write time slots must be a minimum of 60 µs in duration with a minimum of a 1 µs recovery time between individual write cycles. The slave device samples the I/O line in a window of 15 µs to 60 µs after the I/O line falls. If the line is high, a Write 1 occurs. If the line is low, a Write 0 occurs (See Write 0 drawing below). . For the bus master to generate a Write 0 time slot, the data line must be pulled to a logic low level and remain low for the duration of the write time slot. For the bus master to generate a Write 1 time slot, the data line must be pulled to a logic low level and then released, allowing the data line to pull up to a high level within 15 microseconds after the start of the write time slot. (See Write 1 drawing below)

Write 0

Figure 3. An example of typical slave device, the DS2438 write 0 time slot.

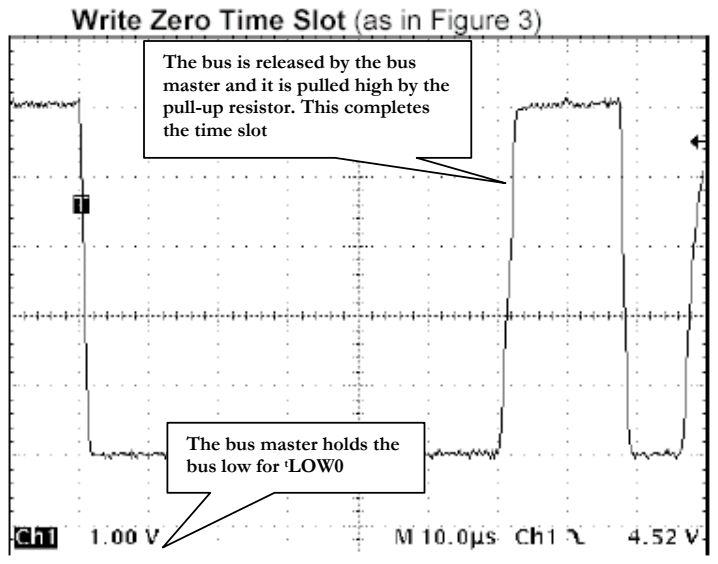
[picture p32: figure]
The bus is released by the bus master and it is pulled high by the pull-up resistor. This completes the time slot; The bus master holds the bus low for t; LOW0

In this real world
image of a write 0
timeframe you can
see the write 0
time slot. It is
being followed by
the next time slot,
which is a write 1.
Version 1.0 8/19/04 | 10

Write 1

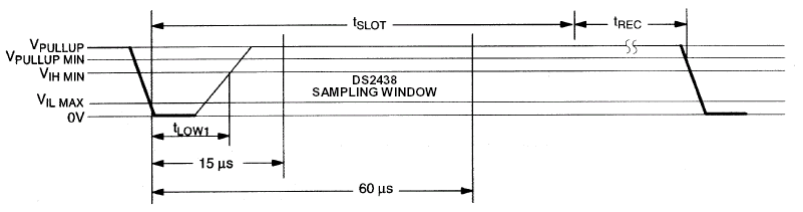
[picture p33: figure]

Figure 4. An example of typical slave device, the DS2438 write 1 time slot.

In this real world image you can see a write 1 time slot. Note that this is the same wave shape as a read 1 time slot.

Version 1.0 8/19/04 | 11

### Read Data

The bus master generates read time slots when data is to be read from the slave device. A read time slot is initiated when the bus master pulls the data line from a logic high level to logic low level. The data line must remain at a low logic level for a minimum of 1 µs; output data from the slave is then valid within the next 14 µs maximum. The bus master therefore must stop driving the I/O pin low in order to read its state 15 µs from the start of the read slot. (See the following idealized drawing). By the end of the read time slot, the I/O pin will pull back high via the external pull-up resistor. All read time slots must be a minimum of 60 µs in duration with a minimum of a 1 µs recovery time between individual read slots.

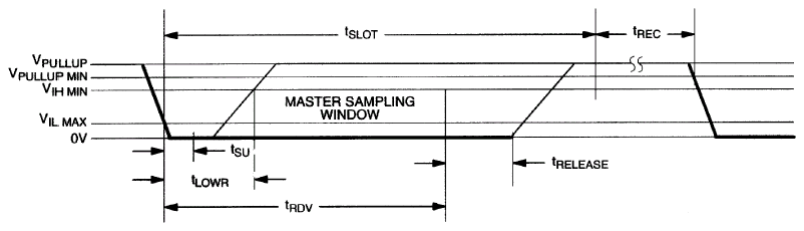
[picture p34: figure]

Figure 5. A read time slot

In this real world image of a read 0 wave shape you can clearly see when the slave device took over control of the bus from the bus master and continued to hold down the bus. Thus returning a 0 to the bus master. The bus voltage rises slightly but is still ≤.8 volts

Version 1.0 8/19/04 | 12

### A typical 1-Wire conversation

Ok… but how is all
this put together?

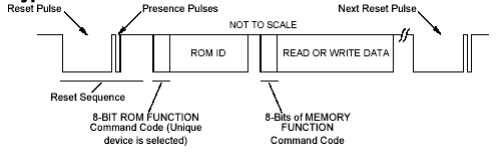
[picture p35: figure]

Diagram 1 typical 1-Wire communication sequence.
So in a typical 1-Wire communication sequence:
- The master resets the network by holding the bus low for at least 480 microseconds, (See Diagram 1 again) releasing it, and then looking for a responding Presence pulse from any slave connected to the line. This is the Reset Sequence with Reset Pulse and Presence Pulse that we talked about before.
- If a Presence pulse is detected, it then accesses the slave by calling its address. Using Write 0 and Write 1 sequences.
- Within each 1-Wire slave created is stored a lasered ROM section with its own guaranteed unique, 64-bit serial number (assigned at the factory), that acts as its node address. This unique address is composed of eight bytes divided into three main sections.
- Starting with the LSB, the first byte stores the 8-bit family code5 that identifies the device type. The next 6 bytes store the unique 48-bit address, while the last byte (MSB) contains a cyclic redundancy checksum (CRC6) with a value based on the data contained in the first seven bytes. This allows the bus master to determine if an address was

5 For a good table of 1-wire family codes try this internet web site: Complete 1-wire family command codes (http://owfs.sourceforge.net/family.html)

6 Refer to Dallas Semiconductor Application note #27: Understanding and Using Cyclic Redundancy Checks with Dallas Semiconductor iButtonTM Products (http://www.maxim-ic.com/appnotes.cfm/appnote_number/542) for details of calculating 1-Wire CRC’s.

Version 1.0 8/19/04 | 13

read without error. With 2⁴⁸ serial numbers set by the factory, conflicting or duplicate node addresses on the 1-Wire network will never be a problem.

- The master issues any device specific commands required (the memory function desired), and performs any needed data transfers between it and the slave. It controls the information transfer by generating time slots and examining the response from the slave. These may include both reads and write sequences.
- Except for the presence detect cycle, Search, Skip and Read ROM commands, only one slave device of then will be responding when addressed by the bus master.

Details of how a 1-wire bus master can search for a particular device can be found in the App Note 187: 1-Wire Search Algorithm (http://www.maxim-ic.com/appnotes.cfm/appnote_number/950)

Version 1.0 8/19/04 | 14

## Building a network of devices

So you now have a rough idea of the protocol and what the idealized form of the signals on the bus should look like. Let’s put a bus master together with some slave devices to form a 1-Wire network. Like this:

How do I organize
the 1-Wire parts
into a system?

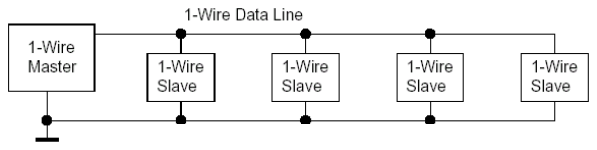
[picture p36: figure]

In the above drawing, you can see the single bus master to the left (there is only one on a 1-Wire network) connected to four slave devices. The 1-Wire data bus line (OWIO) is on the top and the ground return line is on the bottom (OWRTN). These two wires form the 1-Wire bus communications network. A network with this sort of topology is known as having a linear topology. We will talk more about this later in this document.

Version 1.0 8/19/04 | 15

### 1-Wire Slave Devices

We will start looking at our 1-Wire devices in more detail by looking at a slave device first. A typical slave device model, has an internal interface that might be represented like this:

Internal power for the slaves 1-wire network operation is developed from
the data line when it in its high state. A
blocking diode (Di) keeps power from

being lost when the data line is low. The current is limited in the slave by the internal 1000-ohm resistor (Ri). The current charges the 800pf capacitor (CLOAD), which acts as a local power source for the chip. This power source is known as the parasitic power circuitry and is used to power the basic 1-Wire functions of the chip. Some chips require additional power sources for their operation (not shown in the drawing). Also notice that there is a 30pf (average) input capacitance (CIN) between the Data and Return lines

How do all the 1-
Wire parts work?

Every slave contains an internal oscillator that is synchronized by each falling edge of the data signal. This oscillator controls the slaves timing responses. Timing responses are basically done as self-timed events (think of it as 1-shots timers) triggered by the falling edge of the data line. Because the protocol allows for considerable slop in timing responses while not an issue in communications, it explains why devices may respond at slightly different times.

When the slave device wishes to transmit (TX), it does so through the open drain transistor. This port transistor inside the slave allows it to place a logic zero on the network. While this structure allows multiple paralleling of slaves on a single pair of conductors (multi-drop), it does not allow for the bus or cable to be terminated in its characteristic impedance. When the 1-Wire port transistor is on, its impedance is nominally less than 100Ω, which provides a 0.4V logic zero with a 4mA current sink.

A constant discharge current 5µ (Idisc) per slave is required to keep its interface synchronized with the communication protocol. This increases to 10µA (Iop) during communications

If multiple 1-Wire devices are residing on the bus, you should multiply Cin, Idisc, Iop and Cload by the number of slave devices. Ri needs to be divided by the number of devices.

Version 1.0 8/19/04 | 16

### 1-Wire Master Device

While there are many possible forms a Master device can take we will look at only at a simplified model for now. The weak current pull-up resistor (Rpullup) is used to pull the data line high. Values for this resistor typically are between 1000-4700 ohms with a Vs voltage of 5 volts. This works out to a possible weak current range of 5ma to 1.06ma. You must supply enough current for quick pull-up
of the line but not too much which would raise the
0 state voltage floor of the farthest slave device.

An internal buffer is used to sense the level of the data line (RX). A pull-down transistor switch is used to short the data line to the return line in order to pull the data line low.

There are other features of most bus master devices, some of which we will touch on later in this document. But this simplified version is enough for our understanding for now.

Version 1.0 8/19/04 | 17

### Connecting the Slave and the bus master

So far we have defined both our 1-wire slave and bus master devices, we now need to interconnect them. This is where things begin to get complex and where most of the issues in designing and building successful 1-wire networks happen.

What sort of cable should we use to make our network?
To answer that, we first need to look at the characteristics of 1-Wire slave and bus master devices along with some details about cable (wire) itself.

What sort of wire
should I use in my
network?
Basic Cable Factors
When selecting a cable for 1-Wire use it is helpful to start with the basic factors affecting all wire. Every wire cable has certain
characteristics such as resistance, capacitance,
inductance and impedance. The wiring (between the
master and the slaves), can be modeled by the inductance and resistance of the data and return lines, and the lumped capacitance of the cable. A simple model for a 1-Wire cable is shown in the
image to the right.

What is Cable capacitance and resistance?

Cable capacitance is simply the product of cable length times its unit capacitance. This is roughly about 50pF/m for Category 5 twisted pair cable. Better quality CAT5E or CAT6 cable can have lower numbers. Similarly, line resistance represents cable length multiplied by the specified resistance per meter of a single wire.

What is cable impedance?
Characteristic impedance is the impedance that a cable would have if the cable were infinitely long. Impedance is a type of resistance that opposes the flow of alternating current (ac). A cable's characteristic impedance is a complex property resulting from the combined effects of the cable's inductive, capacitive, and resistive results. These values are determined by physical parameters such as the size of the conductors, distance between conductors, and the properties of the cable's insulation material.

The characteristic impedance of a cable is given in its simplified form by:

Zo = √L/C | Equation 1

Where Zo = square root of ( L / C ), where L is inductance per unit length, and C is capacitance per unit length. This is the input impedance of either an infinite length of the cable, or more practically of a finite length terminated by impedance equal to the

Version 1.0 8/19/04 | 18

characteristic impedance. Real cables have resistive losses, which must also be taken into account.

The characteristic impedance (Zo) of a cable is independent
of its length.

### Twisted Pair versus Ribbon Cable

The two most popular cables used for 1-Wire networks today are twisted pair cable (typically CAT5 or better) and flat ribbon cable.

Example of a 6-conductor flat ribbon cable used for a 1-Wire network

}

30m 6 Conductor Phone (26 AWG) Red/Green ~ 96 Ohm Impedance

1,870pf

Connecting conductor No. 5 (Shown as Yellow) to No. 3 (Red) raises the load capacitance to 2,150pf

POWER

POWER

GND

DATA

NC

NC

COMPARISON OF CAT 5 (RECOMMENDED) AND 6-CONDUCTOR PHONE CABLE

Type | Wire Size | Resistance | Capacitance | Inductance | Impedance
CAT 5 UTP | 24AWG | .083Ω/m | 48.5pF/m | .58µH/m | Zo = 100Ω
6 Conductor phone¹ | 26AWG | .133Ω/m | 62.5pF/m | .52µH/m | Zo = 96Ω

Table 1. - ¹Data given for the inner most 2 wires Twisted pair cabling is currently the preferred cabling choice for 1-Wire networks because of its lower capacitance, and resistance values. As network cable lengths increase this becomes very important. There are relatively few variations from manufacture to manufacture due to standard testing and it is widely available at low cost. However flat ribbon “silver satin” type telephone cable was the original 1-Wire network cable used even though it does not have these benefits and is still found in many older 1-Wire installations.

Version 1.0 8/19/04 | 19

Let’s look at what twisted pair cable actually looks like. The individual pairs are twisted together, and then these pairs are twisted also. This helps lessen crosstalk (induced noise) between any two wires.

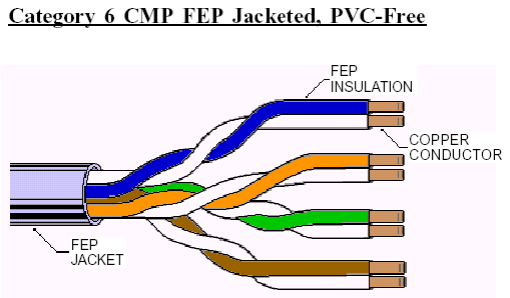
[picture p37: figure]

If we were to compare the inner most twisted pair wires with a flat ribbon cable of the same length it would look like the following image. Note that the capacitance figures are lower in the twisted pair cable, both in the wires and in between wires. This is very important, as wire lengths get longer.

30m CAT 5 UTP (24 AWG) 100 Ohm | 30m 6 Cond.Phone (26AWG) red/grn ~96 Ohm

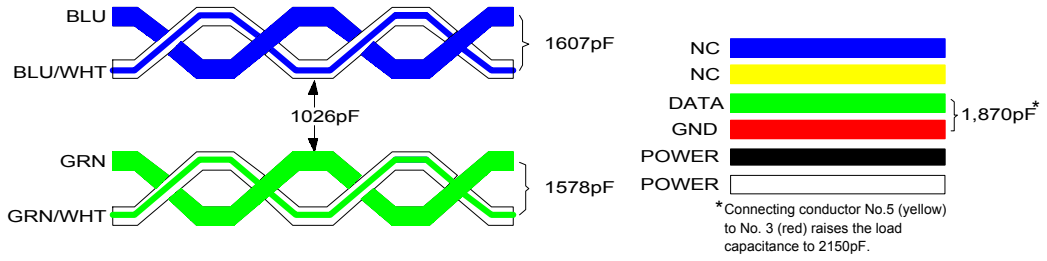
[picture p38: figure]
Connecting conductor No.5 (yellow) to No. 3 (red) raises the load capacitance to 2150pF.; DATA GND POWER; POWER *; BLU; BLU/WHT; GRN; GRN/WHT

Version 1.0 8/19/04 | 20

Categories of Twisted-Pair Cable
Twisted-pair cable has been used for decades to transmit both analog and digital information. The existing telephone system is mostly wired with voice-grade twisted-pair wires (the wire is not twisted in some cases). As we said before, twisted-pair wire is now the preferred wire for 1-Wire network cabling. The twisting of pairs, the quality of the conductive material, the type of insulator, and the shielding largely determine the rate at which data can be transmitted over twisted-pair cable.

The following categories of cable are recognized throughout the industry, and Category 3, Category 4, and Category 5 cable are specified in the TIA/EIA 568-A specification.

- Category 1 Traditional unshielded twisted-pair telephone cable that is suited for voice. Most telephone cable installed before 1983 is Category 1 cable. It is not recommended for network use, although modems do a good job of transmitting over it.
- Category 2 Unshielded twisted-pair cable certified for data transmissions up to 4 Mbits/sec. This cable has four twisted pairs. It was commonly used for IBM mainframe and minicomputer terminal connections and was also recommended for low-speed ARCNET networks. This cable should not be used for high-speed networking or 1-Wire network use.
- Category 3 This category is rated for signals up to 16 MHz and supports 10-Mbit/sec Ethernet, 4-Mbit/sec token ring, and 100VG-AnyLAN networks. The cable has four pairs and three twists per foot (although the number of twists is not specified). Costs are around 10 cents per foot. Plenum cable costs about 40 cents per foot. This cable is installed at many sites as telephone cabling. While some installations use this cable for 1-Wire networks using the newer CAT5 or above cable is a better choice due to its stricter design. Best to use a better cable such as CAT5E than save a few pennies. You will have fewer problems if you do.
- Category 4 This category is rated for signals up to 20 MHz and is certified to handle 16-Mbit/sec token ring networks. The cable has four pairs and costs under 20 cents per foot. Plenum cable costs less than50 cents per foot. While some installations use this cable for 1-Wire networks using the newer CAT5 or above cable is a better choice due to its stricter design tolerances.
- Category 5 This category has four twisted pairs with eight twists per foot and is rated for signals up to 100 MHz at a maximum distance of 100 meters. Ethernet 100Base-TX, FDDI, and ATM at 155 Mbits/sec use this cabling. The cable has low capacitance and exhibits low crosstalk due to the high number of twists per foot. It costs less than 30 cents per foot. Plenum cable costs under 60 cents per foot. This is the predominant cable installed in all new
Version 1.0 8/19/04 | 21

buildings since the early 1990s. This is the lowest CAT type cabling currently recommended for 1-Wire installations.

- Even though Category 5 is widely used, there are many factors that can prevent a cabling system from delivering the intended data rate. Category 5 installations must use Category 5 connectors, patch panels, wall plates, and other components. In addition, proper twisting must be maintained all the way up to connectors, even if you use screw terminals or directly solder your connections.

Enhanced Cabling
Even though Category 5 was once considered future-proof, new Ethernet gigabit-per-second networking schemes have emerged that call for a better class of cable. As mentioned, you can have existing Category 5 cable tested to see if it supports Gigabit Ethernet, but if you are installing new cable for Gigabit Ethernet, choose Category 5E cable, or if you really want to future-proof your installation, consider Category 6 and Category 7 cable. Since these cables also have improved specifications they make excellent choices for 1-Wire networks. Though care may be needed with CAT7 cables.
- Category 5E (Enhanced). This cable has all the characteristics of Category 5, but is manufactured with higher quality to minimize crosstalk. The cable has more twists than traditional Category 5. It is rated at frequencies up to 200 MHz, which is double the transmission capability of traditional Category 5. However, at these frequencies, crosstalk can be a problem, and the cable does not have shielding to reduce crosstalk. This cable is defined in TIA/EIA-568A-5. With its improved crosstalk numbers this is our recommended minimum cable for use when you must include power in the same cable as the 1-Wire network.
- TIA Category 6 and ISO Class E These cable types are designed to support frequencies over 200 MHz using specially designed components that reduce delay distortion and other problems. They have a higher twist ration than CAT5E. The TIA and ISO are cooperating on this category.
- TIA Category 7 and ISO Class F. These cable types are designed to support frequencies up to 600 MHz. Each pair is individually shielded and a shielded jacket then surrounds the entire cable. Connectors are expected to be specially designed proprietary components. The TIA and ISO are cooperating on this category. At this time (7/4/2004) we have no experience with CAT 7 cables and its additional shielding may be a problem with 1-Wire networks.
Version 1.0 8/19/04 | 22

### Cable Summary

While the number of 1-Wire devices on the line affects the performance of the MicroLAN, it is the cable connecting the master and the 1-Wire devices that largely controls and limits the MicroLAN network. For short runs (where the total length of the 1-Wire bus is < 30 meters and the network only has a few slave devices on it), cable selection for use on the MicroLAN is reasonably simple, as even flat modular phone cable can work with a small numbers of 1-Wire slave devices. However, the longer the MicroLAN, the more important cable properties and therefore cable selection become.

Cables display distinctive properties of resistance, capacitance and inductance, which in turn are determined by cable geometry, and the size and spacing of the conductors and their surrounding dielectric. These physical properties define the characteristic impedance, the signal bandwidth supported and the propagation velocity of the cable. Specifically, cable resistance reduces the 0 logic level noise margin. Although resistance values up to 100 ohms are acceptable. Cable capacitance, however, which can range from 30 pF/m to 100 pF/m, loads the MicroLAN driver, increasing not only the pull-up time (The time it takes for the weak-pull-up resistor to restore the signal level to its high state) constant (RC) but also the peak current flowing in the cable as the master transistor turns on and discharges the line. If this transistor turns off before the charge stored in the line capacitance is completely discharged, the residual current left flowing in the line determines the amplitude of the inductive voltage generated. The resulting voltage seen at the driver can become large enough to interfere with communication. At the far end of the cable, this inductively generated voltage swings negative, reverse biasing the substrate of the 1-Wire device closest to the cable end, which in turn clamps the voltage at a diode drop.

The inductance of concern is the differential inductance, which is that measured across the cable input with the two wires of the line shorted together at the far end. Differential inductance is substantially lower than the inductance of a single wire because the current flows in opposite directions in the pair, and in the ideal case would cancel completely. Differential inductance decreases as the distance between conductors is reduced, so use of adjacent pairs or, preferably, twisted pair is recommended. Twisted pairs reduce unwanted coupling from nearby interference sources because the currents induced in the wires flow in opposite directions in the two conductors and tend to cancel. Category 5 twisted pair is recommended for all but the most demanding performance requirements.

A characteristic of cable that must not be overlooked is its fire rating. Cable installed in the plenum space, which is the airspace between the ceiling and the next floor or roof, must be installed in metal conduit, or must meet local fire codes. In the event of a fire, the cable must not produce noxious or hazardous gases that would be pumped to other parts of a structure through the plenum. Non-plenum cables have PVC (polyvinyl chloride) jackets while plenum-rated cables have jackets made with fluoropolymers such as Du Pont's Teflon, which can be very expensive.

Version 1.0 8/19/04 | 23

### The Entire network model

So now that we know a little about each of the various parts of a 1-wire network we can start to put them all together into something like the simplified model below.

Version 1.0 8/19/04 | 24

## Signal integrity

Up to now we have been dealing with semi-idealized forms of timing and waveforms. We now need to turn our attention into understanding real world situations and effects.

### The Rise and Fall time of a signal

The time it takes a signal to switch between voltage levels is known as the signals transition time. This is shown as the tr or tf

in the drawing below. The time it takes the signal to rise from 10% of the low level to 90% of the high is known as the rise time (or tr

), conversely the same is true with a signal that goes in the opposite direction (tf ).

With a typical FET such as the popular 2N2700, this time, tr

or tf

is around 5 ns. So we
can see it takes a definitive time for a signal to change state. This rate of change can also be known as a signals slew rate by measuring the change of voltage over time. If the signal level is 0 and changes to 5 volts in 5 ns, the slew rate is 1000 volts per µs.
Version 1.0 8/19/04 | 25

### Calculating propagation time

Calculating Cable
Line Length

The speed of light in a vacuum is about 299,792,458 meters per second. A typical CAT5E cable has a NVP (the acronym for Nominal Velocity of Propagation) of 69% of the speed of light. Knowing the NVP of a CAT5 cable the speed of a signal in a CAT5 cable can be roughly calculated as follows:

Speed of Light * NVP = Signal Speed in Meters per second or

299,792,458 * 69% = 206,856,796.02 meters per second

Converting that, into meters per nanosecond gives us 0.206856796.

Or expressed in inches 8.143952059 inches per nanosecond

So an electrical signal travels a little over 8 inches every nanosecond in CAT5E cable. We can now calculate our cable line length like this:

Cable Line Length = (Output Rise or Fall Time)/ 2* (Signal delay per unit length)

The signal delay per unit of line length depends on the line’s characteristic impedance and the load on the line. This is the length of the signal line at which transmission-line ringing becomes a major factor. When this time is less than the time it takes for the signal to travel the length of the line and return, a transmission line exists.

If the time it takes a signal to switch between voltage levels (transition time) is less than the time it takes for the signal to travel the length of the line and return, a transmission line environment exists.

Using the above our 5 ns signal will travel a total of 5 * 0.206856796 meters or 1.03428398 meters (A little above 3.3 feet) total while it changes levels. The signal at the cable end will just be starting to change when the signal at the beginning of the cable will already be at its maximum level. When we divide by 2 (to allow for the return path of the signal), we find that the maximum length the cable can be without becoming a transmission line is 0.517142 meters of cable (About 20 inches). So we can

Version 1.0 8/19/04 | 26

see that any network greater than 0.517142 meters will be working in what is known as a transmission line environment when the transition time is 5 ns. You can use the supplied spreadsheet Calc-Line.xls⁷ to calculate this point for any given time or slew rate.
Impedance Effects.
Example 1 - A Properly Terminated line
Let’s stop for a moment and consider the idealized properties of two conductors such as those in the CAT 5 cable Dallas Semiconductor currently recommends for use on the 1-Wire net. This twisted pair cable is characterized as having an impedance of 100 Ohms. If a zero to 5V step function is introduced to the left-hand end of the cable from a 100Ω source, the signal will propagate through to the right-hand end where it will be smoothly absorbed without reflections –assuming a 100Ω resistance is across the ends.

In the absence of the 100Ω terminating resistance, however, only half the step function amplitude will exist on the line until it reaches the right-hand end where it will then jump back to full swing and be reflected back toward the start! When this reflection (echo) arrives back at the 100Ω source at the left-hand end it will be smoothly absorbed without reflections.

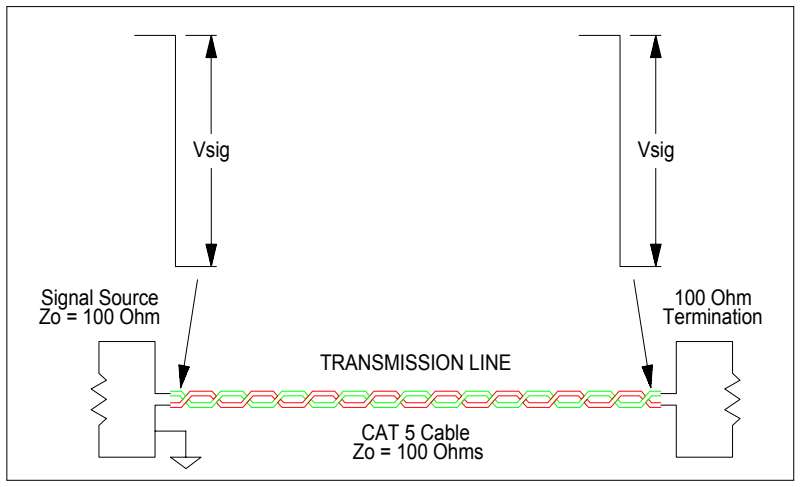
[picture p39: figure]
TRANSMISSION LINE; CAT 5 Cable Zo = 100 Ohms; Signal Source Zo = 100 Ohm; 100 Ohm Termination; Vsig

FIGURE 1 To achieve the best performance a cable can provide, you must drive it with signal source of equal impedance and terminate the opposite end in the cable’s characteristic impedance.

7 A spreadsheet, Calc-Line.xls, is provided as a companion to this document to ease doing some of the calculations

Version 1.0 8/19/04 | 27

A signal transition that instantaneously switches between two levels is termed a step function. When a step function (Vsig) is introduced to a transmission line, it initially propagates at a level equal to the source impedance divided by the line impedance (Z0). That is:
Vsiq = Vinit (Zsource/Z0) Equation 2

An example of this can be seen in these images of a 1-wire system.

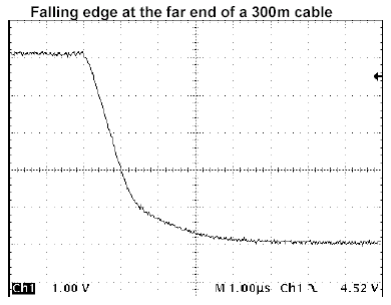
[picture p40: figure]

Version 1.0 8/19/04 | 28

Example 2 - With a single 1-Wire slave at the end of the line
With these facts in mind, consider what occurs when the 1-Wire master is an n-channel MOSFET without slew-rate control and the ‘end termination’ is a single 1-Wire slave. The normal quiescent state of the 1-Wire network is 5V with communication starting when the master pulls the line low. For convenience sake, we will assume the on-resistance of the FET to be 10Ω, only one-tenth the 100Ω impedance of the cable. Since the FET acts as a switch, it can pull the line to ground in 10 nanoseconds or less creating a negative transition that goes below ground. For practical purposes this transition represents a step function as previously described, meaning that 1-Wire communication would be occurring in a transmission line environment for any cable length exceeding about 20 to 40 inches (roughly 0.5 to 1 meters).

When this signal reaches the 1-Wire slave at the other end of the cable it sees an unterminated line as the slave is quiescence and in a high impedance state. At this point two things happen closely in time, the unterminated open end of the cable reflects the signal and the slave responds to the signal by turning on its internal pull down transistor assuming 1-Wire communication is in process. The mismatch between the 50Ω on-resistance of this transistor with the natural impedance of the cable generates a perturbation that sends a second small step of oppose polarity following the first reflection. When these reflections arrive back at the master and see the mismatched impedance of the FET they are again reflected as opposite polarity steps. This oscillatory condition will continue until the signal dies out exponentially due to

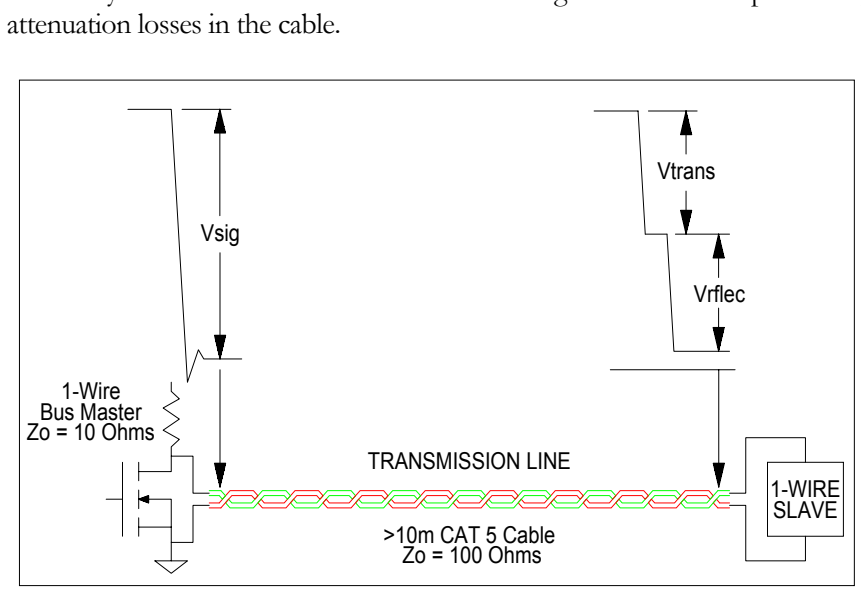
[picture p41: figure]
attenuation losses in the cable.; 1-WIRE SLAVE; 1-Wire Bus Master Zo = 10 Ohms; TRANSMISSION LINE; >10m CAT 5 Cable Zo = 100 Ohms; Vsig; Vtrans; Vrflec

Figure 2 Even a simple 1-Wire network can end up operating in a transmission line environment due to the fast pull down edge of a FET and the impedance mismatch to the cable

Version 1.0 8/19/04 | 29

If the impedance across the end of the line is higher than the natural impedance of the line (Z0), a step function will be reflected with the same magnitude and polarity as the incident signal. This is typically what occurs when a data transition arrives at the unterminated end of a 1-Wire net.

If the impedance across the end of the line is lower than the natural impedance of the line (Z0), a step function will be reflected with the same magnitude but of opposite polarity as the incident signal. This is typical of what happens at the master end of a 1-Wire network due to the low impedance of
the FET.

Example 3 - With one slave at midpoint and a second slave at line end
Again using a plain n-channel MOSFET pull-down transistor with 10 Ohms on-resistance as the signal source we launch a step function down the line. When the transition reaches midpoint on the line, it encounters a discontinuity due to the 1-Wire slave, which causes the signal to split into a reflected signal, which travels back toward the master, and the remnant of the original signal that continues down the line. Given that the propagation time for both signals is identical, the reflected signal arrives back at the master and is reflected as a negative step at the same time that the remnant of the original arrives at the cable end and second slave and is reflected in the same manner as described in Example one.

Notice that the reflected signal from each end of the line is now advancing toward each other and will arrive simultaneously at the midpoint slave. The case where both reflections arrive simultaneously only occurs at the midpoint making it unique, at all other points on the line a slave will see the two reflections at different times. If the slave is passive, that is, not communicating and in a high impedance state, two new signals will be generated –one new reflection from each of the two original signals making a total of four signals now transversing the line.

How the interaction of these two affect the slave depends on a number of variables including the physical length of the line, whether communication is in progress with the master, the amplitude of the reflections and the thresholds of the slave. From this example it should be apparent that placing 1-Wire slaves at integer fractions of the line length could lead to difficulties. And the reason moving a slave a short distance in either direction from where it is non-responding can result in reliable communication.

Version 1.0 8/19/04 | 30

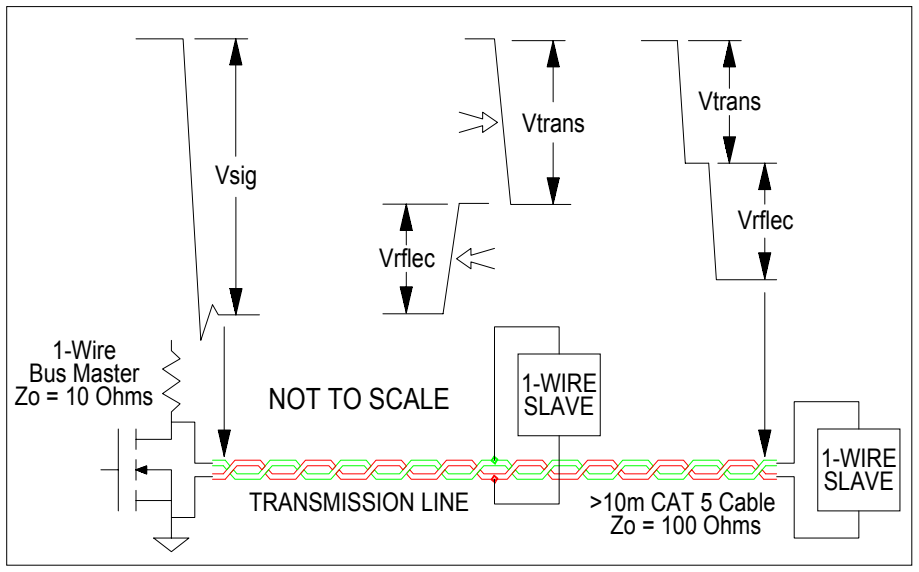
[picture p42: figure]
1-WIRE SLAVE; 1-Wire Bus Master; Zo = 10 Ohms; 1-WIRE; SLAVE; Vsig; Vrflec; Vtrans; TRANSMISSION LINE; >10m CAT 5 Cable Zo = 100 Ohms; NOT TO SCALE

FIGURE 3 Any discontinuity on the line, including slaves can cause reflections. Locations that are at integer fractions of the line length are particularly problematic as they can resonant.

When a step function (Vsig) is introduced to a transmission
line from a matched source (Z0), it travels down the line until
it encounters an impedance mismatch (Z1

). At that point the
signal will split into reflected (Vrflec) and transmitted (Vtrans) fractions. The reflected portion (Vrflec) travels back toward the driver, while the transmitted portion (Vtrans) continues down the line in the original direction. This phenomena occurs at each slave and connection positioned along the length of the 1-Wire net. The relationship between (Vtrans) and (Vrflec) is given as:
Vtrans = Vsig + Vrflec | Equation 3
Vrflec = Vsig (Z1-Z0) / (Z1 + Z0) | Equation 4
Version 1.0 8/19/04 | 31

### Wavelength effects

In addition to the adverse effects on communication that can occur due to placement of slaves at integer fractions of the line length, slaves that are located one-quarter of the length of the cable from an end are susceptible to resonant effects. For example, a 1MHz signal has a wavelength approximately 300m8 long; consequently a 1-Wire network of this length will be both a radiator and a receiver for signals with this frequency content. If a slave is placed 75m from either cable end it will be exposed to the maximum signal amplitude of a signal at the tuned frequency as illustrated in Figure 4.

FIGURE 4. Placing slaves at one-fourth the length of the cable can lead to communication problems.

The current required to change voltage (Vchg) on a
transmission line is given by:
I = Vchg / Z0 | Equation 5

You can use the supplied spreadsheet9 to help calculate wavelength nodal points for any cable length given. Don’t forget that with the use a hub chip you can change the effective total length of the cable.

8 EM radiation in air is approximately the same as a vacuum so it’s the speed of light / frequency or 299,279,458 / 1,000,000 Hz = 299.79246 meters or approximately 300 meters

9 See spreadsheet Calc-Line.xls⁹

Version 1.0 8/19/04 | 32

### Slew Rates

Because it is not possible to terminate the end of the cable in its characteristic impedance in order to help prevent ringing, the alternative is to control the slew rate (how fast the voltage changes logic states) of the bus master pull down transistor. This is done through additional circuitry in the bus master.10, which slows the rate of falling transitions from high to low. Devices like the DS2480B (http://pdfserv.maxim-ic.com/en/ds/DS2480B.pdf) have this circuitry built into the chip.

What are slew
rates

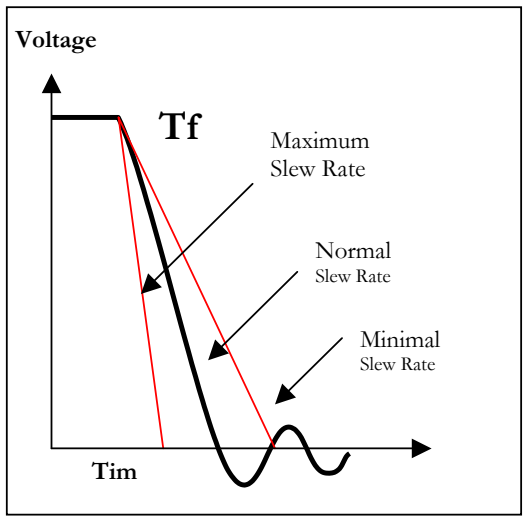
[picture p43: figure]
Voltage; Tim; Minimal Slew Rate; Normal Slew Rate; Maximum Slew Rate

Figure 5 showing the range of different slew rates
Excessively fast fall times (high slew rates) can cause ringing and generate signals on the 1-Wire bus that are unwanted and may interfere with valid data waveforms. This can be seen in Figure 5 where the falling voltage causes temporary ringing (voltage oscillations above and below the eventual steady-state level) Eventually the cable attenuates (dampens) these oscillations to the steady state level.

Ringing or Ring
back

By slowing the slew rate you can lessen the effects of ringing. Excessively slow rise and fall times may not meet timing requirements, and may expose the transition period to the effects of noise and reflections.

The maximal slew rate setting is achieved if the voltage drop from 5V to 0V takes twice as long as the signal propagation delay from the driver to the far end of the cable and back (roundtrip propagation delay).

Version 1.0 8/19/04 | 33

10 See App Note 244: Advanced 1-Wire Network Driver (http://www.maxim-ic.com/appnotes.cfm/appnote_number/2082)

The effect of differing slew rates in the time it takes to cross the 1-wire indeterminate region can be seen in the following table. Those in gold/green are the rates found in a DS2480B or DS2490 USB adapter. While the orange/yellow slew rate might be found in a non-slew rate controlled 2N7000 switch.

Time periods for slew rates
| | Vs to VIH | VIH to VIL | VIL to 0
Device Slew Rate | | Vs to VIH
| | Intermediate Region
Device | V/µs | VIL to 0
2N7000 | 1000.00 | 0.0028 | µs | 0.0014 | µs | 0.0008 | µs
DS2480B | 15.00 | 0.1867 | µs | 0.0933 | µs | 0.0533 | µs
DS2480B | 2.20 | 1.2727 | µs | 0.6364 | µs | 0.3636 | µs
DS2480B | 1.65 | 1.6970 | µs | 0.8485 | µs | 0.4848 | µs
DS2480B | 1.37 | 2.0438 | µs | 1.0219 | µs | 0.5839 | µs
DS2480B | 1.10 | 2.5455 | µs | 1.2727 | µs | 0.7273 | µs
DS2480B | 0.83 | 3.3735 | µs | 1.6867 | µs | 0.9639 | µs
DS2480B | 0.70 | 4.0000 | µs | 2.0000 | µs | 1.1429 | µs
DS2480B | 0.55 | 5.0909 | µs | 2.5455 | µs | 1.4545 | µs
From this it can be seen that an appreciable amount of time can be spent in this region with slower slew rates. This increases the likelihood of noise events effecting the 1-wire switching and causing communications errors. So finding the right balance between a slow slew rate and the cable length is important.

Calculating the slowest slew rate - example
Based on the DS2480B and Ds2450 datasheets, the maximum time you can take to slew from 5 Volts to <VIL MAX is 8 µs – tsu (1µs max) or about 7µs given the shortest possible sample point time11. This works out to about to a slew rate of 0.7V per µs. To use any slower slew rate you must delay the sample time. These relationships can be seen in the following drawing.

11 Calculated based on datasheet timings for the DS2450 and DS2480B bus controller.

The slew rate should never be slower than ½ of the roundtrip duration time of the sample time in the cable.

A common rule of thumb is to use a slew rate with a ratio of the falling edge (Tf) to the one-way electrical propagation length of the cable of 8 to 1. This ratio sets a minimal signal reflection for the signal based on the slew rate and gives maximum performance. When the slew rate is in the ratio of 5 to 1 it is considered normal range and a 2 to 1 ratio is used for minimal control of signal reflections. Consult the companion spreadsheet for help calculating these values.

The advantages of controlling the slew rates are:12

- Helps provide clean signals with minimal signal reflections
- Reduces to reduce RF emissions

Calculating Cable Length Slew Rates
The effect of changing the slew rates in a DS2480B on the theoretical point where line effects are a major issue in a CAT5 cable (69% NVP) can be seen in the following table with different ratios given (2,5 and 8). Additional effects such capacitive load will change these distances.

Cable Length Slew
Rates

Recommended cable lengths based on DS2480B slew rates Cable length should be < given value for performance category
Slew Rate | Slew Rate | 2 | 5 | 8
| | 2 to 1 ratio 5 to 1 ratio 8 to 1 ratio
Volts per µs Volts/µs | Minimal | Normal | Optimum | Units
2N7000 | 1000.00 | 0.517 | 0.207 | 0.129Meters
DS2480B | 15.00 | 34.476 | 13.790 | 8.619Meters
DS2480B | 2.20 | 235.065 | 94.026 | 58.766Meters
DS2480B | 1.65 | 313.419 | 125.368 | 78.355Meters
DS2480B | 1.37 | 377.476 | 150.990 | 94.369Meters
DS2480B | 1.10 | 470.129 | 188.052 | 117.532Meters
DS2480B | 0.83 | 623.063 | 249.225 | 155.766Meters
DS2480B | 0.70 | 738.774 | 295.510 | 184.694Meters
DS2480B | 0.55 | 940.258 | 376.103 | 235.065Meters

12 See App Note 132: Quick Guide to 1-Wire net (Has been replaced by App note #148) (http://pdfserv.maxim-ic.com/arpdf/AppNotes/app132.pdf)

Version 1.0 8/19/04 | 35

Undershoot
The falling edge (Tf

) of any falling edge must be monotonic (Single edged). Excessively fast fall times (high slew rates) cause ringing and undershoot or rings back) from its initial minimum- low level. . This may occur on a non-slew rate controlled edge and can also be seen on the falling edge of an uncontrolled slave presence pulse. Undershoot events can be the cause of increased errors. If the signal retreats to far, it can cause false clock triggering of 1-wire circuits.

Negative
Transitions

If the ringing is severe enough it may exceed the negative limits of the devices to handle. Therefore at a minimum, we recommend for good design practice to add an Schottky diode (like a BAT54S13 or a 1N581714) to help limit these signal excursions.

13 See Bat54S PDF datasheet (http://www.fairchildsemi.com/ds/BA/BAT54S.pdf)

14 See 1N5817 PDF datasheet (http://www.onsemi.com/pub/Collateral/1N5817-D.PDF)

Version 1.0 8/19/04 | 36

The following image shows a bus reset and presence sequence, but more importantly it shows the difference between the behavior of the slew-rate controlled master and an uncontrolled slave device15. The falling edge created by the master is clean and does not undershoot or ring. The falling edge caused by the slave device is uncontrolled, and it can be observed to cause ringing and undershoot on the bus.

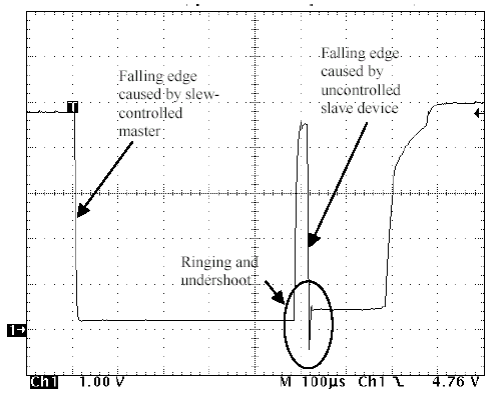
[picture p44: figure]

In order to help dampen undershoots that go below ground Schottky diodes are often used. It is recommended that these be used across each slave and at cable ends. Connect the diode across the cable with the cathode on the data line, and the anode on the return. Other circuit protection schemes are also possible. Remember to consider the impact of these diodes or other circuitry when considering your network loading (total capacitive loads of all devices on the network, including diodes, etc.)

15 Not all slave devices have uncontrolled presence pulses. Devices like the DS2408 and DS2431 use the new improved edge circuitry now offering controlled slew rates. Consult your datasheets for information.

Version 1.0 8/19/04 | 37

Phantom Presence pulse
If the net consists of a fixed collection of 1-Wire slaves, the slew rate problem of their Presence pulse can be overcome by generating a “Phantom Presence Pulse” with the bus master. This is simply an artificial slew rate controlled Presence pulse created by the bus master that starts at 10 µs and terminates at 60 µs. A sample pulse can then be generated at 70 µs to see if a slave is on the bus or node if desired. This technique masks the high slew rate of the slave high-to-low Presence pulse transitions because the bus is already at logic zero when they occur. However, the Phantom Presence pulse technique is obviously ineffective when dealing with newly connected slaves, which arrive at unpredictable times on the bus.

Figure 6 The bus master can generate a Phantom Presence pulse prior to any possible presence pulse from a slave. It must last until the slowest possible Presence pulse has started.

Version 1.0 8/19/04 | 38

Positive | Pull-Up Currents
Transitions | The Weak Pull-up The rising edge (Tr ) must be monotonic (Single edged).
| Once both master and slave turn off, the bus pull-up resistor pulls the data line high. As the capacitive load on the net increases by adding 1-Wire devices, the time to raise the data line to the supply voltage also increases. This also occurs when the network is lengthened due to the 50pF of capacitance added per meter of twisted pair cable. This can be seen in Figure 7 as the number of slaves is increased from 1 to 300. If the product of the total capacitive load (including cable, device, stray capacitance, etc.), and the pull-up resistor value results in a time constant (RC) that exceeds the bit time slot defined by 1-Wire protocol, communication stops.

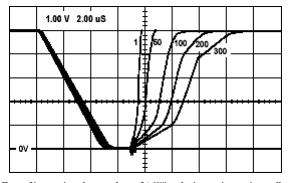
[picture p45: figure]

Figure 7 Loading effect of increasing the number of 1-Wire devices using active pull-up, and 2m cable. Protocol, communication stops because grounding unused wires or shields in a cable adds capacitance
Because grounding unused wires or shields in a cable adds capacitance, which can significantly increase the RC time constant, they should be left disconnected. You want to limit capacitance throughout a 1-wire system as much as possible to maximize cable length and limit RC effects.
Version 1.0 8/19/04 | 39

The product of the pull-up resistor value and the idle current of all devices on the line determine the maximum voltage to which the bus pull-up resistor can raise the data line. The more devices, the greater the voltage-drop across the pull-up resistor.

Calculating the
Max Fan Out.

The fan out limit of a particular 1-Wire net is reached as the voltage drop across the pull-up resistor reduces the net supply voltage to 2.8V. This is the minimum voltage that will recharge the parasitic power supply of the 1-Wire devices. From this, the maximum theoretical fan out may be calculated. It is equal to the supply voltage (Vs) minus 2.8V (the minimum operating voltage) divided by the pull-up resistor value. The resultant is divided by 15µA, the worse case device supply current. For a 5V supply and 1.5K minimum pull-up resistor value we have the following.

Fan out Max = (Vs-MaxOpV)/Resistance

Fan out Max = (5-2.8)/1.5K=1.47mA/15µA=98 devices

This represents the theoretical maximum number of 1-Wire devices that can successfully communicate with the master using a 1.5K pull-up resistor and 5V supply over worse case conditions of current and temperature. The assumptions being that all devices are drawing the maximum supply current and operating in a -40 to 85_ºC environment.

In the real world, all devices will only be drawing the 15µA maximum supply current during System Reset and Presence Detect. At that time all device oscillators turn on for 5T times. Since 1T time typically lasts 30 microseconds, 5T times represent 150 microseconds, with a worse case of 255 microseconds. The Dallas Semiconductor design team always referred to 1-Wire timing in terms of multiples of the divider output of the oscillators. So 5T times means five periods of the divided down internal oscillator. Circuit design ensures that all 1-Wire devices will be able to operate from their internal parasite power source for the duration of this interval once fully charged. Thereafter, they will be drawing 5µA maximum, which permits tripling the previously calculated fan out of 98. In addition, most systems will be operating over a much narrower temperature range, which allows still larger fan-outs. For example, in a typical lab environment, over 500 1-Wire devices in continuous communication had only a 1.2V drop across the pull-up resistor. This implies that typical idle current per device is less than 2µA when environmental and supply ranges are limited.

The starting
charge time for a
slave device
Version 1.0 8/19/04 | 40

Active Pull-up
Most bus masters use an additional circuit called the active pull-up to help the weak pull-up resistor insure that the bus returns to the high state in a timely manner. This acts as a power boast to the weak pull-up current resistor. This is done by having a circuit that turns on a current boast as soon as the voltage has risen sufficiently turning off the boost and allowing the weak pull-up current to finish pulling up the line. Its looks something like this:

Active Pull-up,
what is it?

You can see that on the rising edge, the voltage is originally is pulled up by the weak pull-up current. At the Active pull-up trip point the current is increased and the rate of the rising edge increases. At the Active Pull-up turn off point, the active pull-up current boast is stopped and it is left to the weak pull-up current to pull the line up the rest of the way.

The advantages of an active pull-up in the bus master are:

- Gets the signal to 5V faster
- Gets more energy to the slaves (good for recharging the parasitic capacitors)
- Minimizes the effects of the droop when the slaves start recharging their parasite power supply
- Allows more slave devices in the network

The slew rate for the rising edge is not that critical. As a recommendation it should be four times as fast as that of the falling edge, but not faster than 5V/µs.

Version 1.0 8/19/04 | 41

Care must be used to prevent the active pull-up circuit pulling the line high from fighting with a slave device trying to make the line low.

Avoiding false
triggers of a active
pull-up circuit

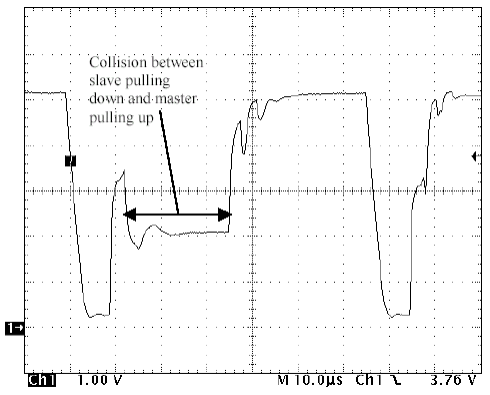
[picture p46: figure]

When a bus master has a dynamic pull-up as in the DS9097 or the LINK a situation can occur if the feature has been falsely turned on by a signal reflection. This image shows the resulting chaos that occurs when the dynamic pull-up is falsely triggered by reflections on the cable due to stubs and branches. This is a Read Zero time slot, where a reflection has caused the dynamic pull-up to activate and collide with the pull-down in the slave device.

Version 1.0 8/19/04 | 42

### Parasitic Power

Parasitic Power Threshold
1-Wire devices derive the power they need to communicate with the bus master from the DATA line by use of an internal diode and the 800pf capacitor that steals power from the bus (See 1-Wire Slave Devices). Whenever the DATA line is at or above approximately 2.8V, the internal capacitor charges to one diode drop below the voltage on the line. In the case where there are many 1-Wire devices on a long line, this recharging of the parasite power capacitors can produce perturbations that include voltage reversals, that is, the signal becomes non-monotonic.

Problems with
Parasitic power

Figure 8 Effects of charging parasitic power on Tr when a long 1-Wire network is heavily loaded.
Because this occurs at a level approximately one-diode drop above the logic one switching threshold a heavily loaded long line can potentially produce voltage reversals from parasite recharging that pass back through the switching threshold causing communication problems. This suggests that the active pull-up current (if any) should be increased in the 2.2 to 2.8V region.

At power up, capacitive loading of the cable and slave devices can require several milliseconds (See The original charge time for a slave device) to charge before communication can start on the net, especially if a passive (resistive) pull-up is used. Also on long lines with many slaves grouped at the end, the parasitic power requirements create a dip or slope change in the rising edge of the waveform at about 2.8V as the energy reservoirs of the devices are filled. Once full, the recovery time after each time slot will be sufficient to maintain the charge.

Capacitive loading
from Slave devices
and cable

Figure 7 shows the effect charging the parasite power capacitance has on different numbers of 1-Wire devices at the end of 100 meters of Category 5 cable. Notice that the slope of the rising edge decreases as it crosses the 2.8V threshold finally reversing

Version 1.0 8/19/04 | 43

direction to form a dip when loaded with 100 or more devices. These “dips” become more pronounced the longer the bus remains low.

Figure 9 Parasitic power loading during the 0 to 1 transition. Notice that the dip becomes more pronounced with increasing number of devices at end of 100m of cable.

What happens
when there is a
slow rise time or
insufficient
recovery period

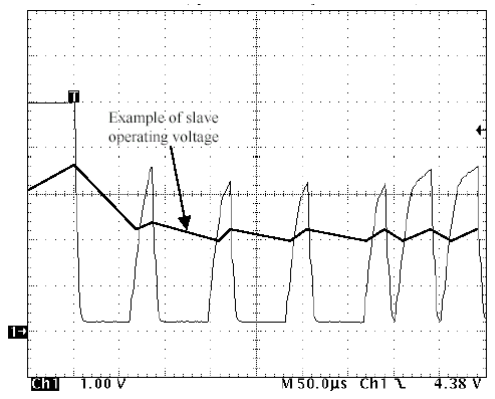
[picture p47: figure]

When the 1-Wire rise time is insufficient, recovery time (the period between time slots) may be insufficient to allow the bus to reach a level sufficient to recharge the slave devices. In the image above, the average DC level that the slaves have to work with has become dangerously low. Slaves may reset due to power starvation, especially during long strings of Write Zero time slots.

Version 1.0 8/19/04 | 44

### Cable Length Issues

Several factors determine how long the cable for the 1-Wire network can extend, all of which were not covered in the preceding examples.

Line Loading
One important factor not previously mentioned is line loading this consists not only of the number of slaves on the line but the loading due to the cable itself. Slaves add about 30pF apiece while CAT 5 cable adds almost 50pF/m (which increases the interval of time required for a passive pull-up to return the line to a valid logic one value. As this interval increases, there comes a time when the voltage on the line will not reach a level sufficient to recharge the internal energy capacitor in one or more slaves. These will then effectively cease to exist on the net. As a rule of thumb, when using a 1-Wire adapter such as the DS9097U, limit the maximum value of capacitance to 10,000pF or less. For example, twenty slaves would load the line with 600pF (30pF x 20 = 600pF) leaving 9,400pF for the cable. Dividing this value (9,400) by 50pF/m gives 188m for the maximum suggested line length.

Maxlength=(10,000pf-(30pf x Number_of_Slaves))/LineCapacitance

Given twenty slaves on the 1-Wire network and recalling the transmission line effects discussed in the preceding it is evident that where these are located on the line can have a profound bearing on communication reliability. In a system that consists of a single close grouping of slaves at one end with a remote master, reflections between individual slaves are less of a problem. However, a more typical system would have small numbers of slaves grouped at staggered intervals along the cable. Since, as it has been discussed, the line cannot be properly terminated and slaves act as discontinuities on the line, reflections will be a problem.

Capacitance
Once both master and slave turn off, the bus pull-up resistor pulls the data line high. As the capacitive load on the 1-Wire network increases by adding 1-Wire devices, the time to raise the data line to the supply voltage also increases. This also occurs when the network is lengthened due to the 50pF of capacitance added per meter of twisted pair cable. This can be seen in Figure 10 as the number of slaves is increased from 1 to
300. If the product of the total capacitive load (including cable, device, stray capacitance, etc.), and the pull-up resistor value results in a time constant (RC) that exceeds the bit time slot defined by 1-Wire protocol, communication stops. Because grounding unused wires or shields in a cable adds capacitance, which can significantly increase the RC time constant, they should be left disconnected.
Version 1.0 8/19/04 | 45

Figure 10 Loading effect of increasing the number of 1-Wire devices using active pull-up, and 2m cable. As can be seen in Figure 10, the input capacitance of the slaves, contribute to the total capacitive load on the network. However, the slaves’ internal 800pF parasitic power supply capacitance only exists at voltage levels above 2.8V minimum. Ignoring the capacitance of the parasitic power capacitor, the bus pull-up resistor value, together with the cable capacitance and 1- Wire device input capacitance represent the network time constant τ. This is a reasonable omission since parasitic capacitance does not become a factor until the bus has already passed the 2.2V logic one threshold. The network time constant determines the rate at which the data line returns to a logic one voltage. With the requirement that at τ equals 13.02 microseconds (the original data sample time) the 1-Wire voltage needs to have reached the 2.2V threshold of a logic one, the value of τ can be calculated as follows.

τ = 13.02 µs / ln (Vs/(Vs-2.2V)) = 22.4µs

Where Vs is the pull-up supply voltage. Using the recommended 1.5K minimum pull-up resistor value and 5V supply voltage τ is calculated as 22.4 microseconds. Assuming the 1-Wire network is loaded with the maximum fan out as calculated previously, the cable capacitance alone must not exceed 12nF to yield a network time constant no more than the value just calculated. Using 50 pF/m for the typical cable capacitance implies that the theoretical maximum cable length is 240 meters. If the data sample time is recalculated with the new value of 21.7 microseconds, τ becomes 37.4µs. This permits 22nF of cable capacitance, which represents a cable length that exceeds the maximum allowed round trip propagation time.

The effect of cable capacitance on the signal can be seen in Figure 11, where 100 1-Wire slaves were addressed at the end of a 2 and 100-meter cable. The 100-meter cable added 5000pF of capacitance.

Version 1.0 8/19/04 | 46

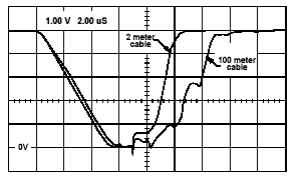
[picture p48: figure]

Figure 11 Effect of cable capacitance on signal driving 100 1-Wire devices.
The 100m cables adds 5nF. Reducing the value of the pull-up resistor, using lower capacitance cable, shortening the cable, or reducing the number of devices on the bus can improve the rise time. The pull-up resistor, however, should not be reduced below 1.5 k_. Reducing the value of the pull up resistor increases the logic zero voltage on the network, reducing system noise immunity. If the value of the pull-up resistor is already minimum, an active pull-up may be substituted. This also allows use of longer cables by decreasing the network time constant. Of course, the same rules apply to an active pull-up as to a pull down, and slew rate must be controlled to avoid operating in a transmission line environment. The effect of residual current flowing in the bus when the active pull-up turns off can be seen in Figure 12. This was of little concern with a passive pull-up as an RC time constant has an inherently slow slew rate.

### Effects of line capacitance (Long lines)

Figure 12 This image
shows the effect of
excessive weight when
using a master with
resistor pull-up only.
The network radius in
this example is 1000
feet and there are 30
devices at the far end
of the network. The
reflections from the
end of the network can
be clearly seen, as can
the very slow rise time.
Note that although this
is a Read One time
slot, the data level at

the sample time is near the borderline and could be misread by the master.

Version 1.0 8/19/04 | 47

Version 1.0 8/19/04 | 48

On the rising edge, as the capacitive load on the MicroLAN increases either by adding 1-Wire devices or cable capacitance by making the line longer, the time to return the line to the supply voltage increases. If the product of the total capacitive load (which includes line, device and stray capacitance) and the pull-up resistor value results in a time constant (RC) that exceeds the bit time slot defined by protocol, communication ceases. For this reason unused wires in a cable should be left unconnected. Grounding them can increase the capacitive load so significantly that the pull-up cannot raise the line above the logic-switching threshold in the bit time. If the value of the pull-up resistor is already the minimum (1100 ohm is recommended) that generates a recognized 0 level, an active pull-up must be substituted. Of course, the same rules apply to an active pull-up as to a pull down, and the slew rate must be controlled when operating in a transmission line environment. This is of little concern with a passive pull-up resistor as the RC time constant has an inherently slow slew rate.

Summary of
capacitive loading

Propagation time
Propagation time on the cable is also a factor, as a slave nearer to the master will see a command such as a RESET earlier than one more distant. In reply a slave will generate a Presence Pulse with a slew rate that places the 1-Wire network in a transmission line environment for line lengths greater than three meters. Given an example of 188m with twenty slaves it takes a little over 1µS (0.18cm/nSec times 5.55 times 188m) for the RESET from the master to reach a slave situated at cable end. The other nineteen slaves will have seen the command and started sequencing to respond before this last device even receives it! Therefore, a slave next to the master will transmit its Presence Pulse about 1µS before the one at the opposite end. The high-to-low transition at the start of this Presence Plus will propagate down the line generating reflections as it passes the discontinuity created by each slave reaching the last slave at about the time it is starting to generate it’s own Presence Plus. Whether this transition is reflected by an unterminated end, (same amplitude and phase) or one with a lower impedance, (same amplitude, opposite phase) is determined by the state of the end slave. In this example, slaves between the two end ones will be still be in a high impedance state preparing to generate their own Presence Pulse. This scenario illustrates one of the numerous interactions that can occur on a 1-Wire network when it is operating in a transmission line environment with an unterminated line.

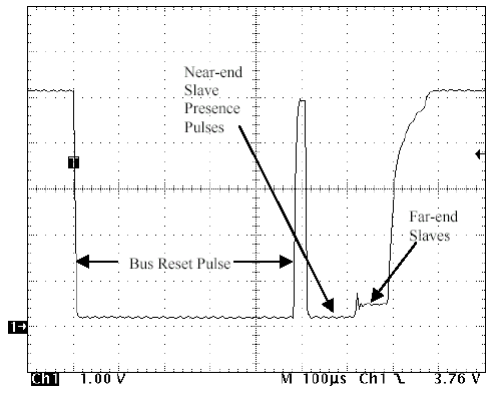
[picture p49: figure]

Figure 13. During Bus Reset sequences, the dynamic pull-up is used to overcome the network weight after the reset pulse, and then again after the end of the presence pulse(s). In this image, the overlap of near- and far-end presence pulses can be observed. The added resistance of the cable between the master and the far-end slave causes the low level to be higher for far-end devices than for near-end devices.

Version 1.0 8/19/04 | 49

Avoiding line | Line Inductance
inductance
problems

As line inductance increases, the product of L Ldata/Lreturn can generate voltage excursions that cause bit errors and reverse bias the substrate of at least the first 1-Wire device at the far end of the cable. The current still flowing in the data and return lines of the cable when the transistor in the master is turned off before the charge stored in the line capacitance is fully discharged generates these voltages. The obvious and recommended solution is to maintain the pull down transistor in the on state until the
current in the line discharges. | Note the voltage
overshoot

This pulse would
cause false triggering
of the slave devices

Figure 12. Inductively generated voltage spikes such as seen here, can occur on long lines due to residual current flow when pull down or pull-up circuits turn off.
The residual current left flowing in the line determines the amplitude of a transient voltage spike generated as a product of this current and the cable inductance. The resulting voltage spike seen at the driver can become large enough to interfere with communication. The effect of residual current flowing in the cable when the bus pull down transistor and the active pull up turns off can be seen in Figure 12. Notice that in each case, the spike generated is in the direction of the opposite rail. At the far end of the cable, when the pull down transistor turns off it’s inductively generated voltage spike swings negative, reverse biasing the substrate of the 1-Wire device closest to the cable end which clamps the voltage excursion at a diode drop. This device will then not respond to the bus master.

A reason why the
last slave device
on the cable may
disappear…

If it is not possible to stretch the timing, an Schottky diode placed across the bus at the far end is suggested to clamp the inductive generated voltage overshoot. This is good general advice anyway as noted when we talked about undershoots, since it can help prevent voltage excursions caused by other events also. Connect the diode across the cable with the cathode on the data line, and the anode on the return. Only one diode is required for each length of MicroLAN with problem inductance.

…How to fix it

Now that we have an idea of some of the many ways line issues can cause 1-Wire network problems, lets take a look at network topologies.

Version 1.0 8/19/04 | 50

## A introduction to Topology

A network may be represented as a collection of nodes, which are linked together by connections. Network topology is determined only by the configuration of connections between nodes; it is therefore a part of Graph theory. Distances between nodes, physical interconnections, transmission rates, and/or signal types are not a matter of network topology, although they may be affected by it in an actual physical network.

Linear Topology is the recommended topology for 1-Wire networks

Linear Topology
Example of Linear Topology using 1-bus master device and 4 slave devices

In linear topology, the 1-Wire bus starts at the bus master device and extends to the last slave device on the network. Each device is directly connected to the network so in essence the network passes through each device. This is the most desirable network configuration.

Bus | 1 | 2 | 3 | 4
Master

Example of a 1-Wire short stub network topology. Slave devices 2 and 3 have short stubs (indicated in red) to the main network bus. In a short stub network, very short lengths of wire connect the slave devices to the 1-Wire network bus. This can be seen in connections of slave devices number 2 and 3 in the above drawing. The devices are tapped onto a bus that extends through the slave devices 1 and 4. While Dallas Semiconductor recommends these to be <3 meters in length we suggest these should be kept as short as possible. With a range of centimeters in length (a few inches max) being desirable, with the shorter the better.

Version 1.0 8/19/04 | 51

Short Stub networks are often used because of the use of a PCB board design or physical limitations when installing a network.

Long Stubbed Topology

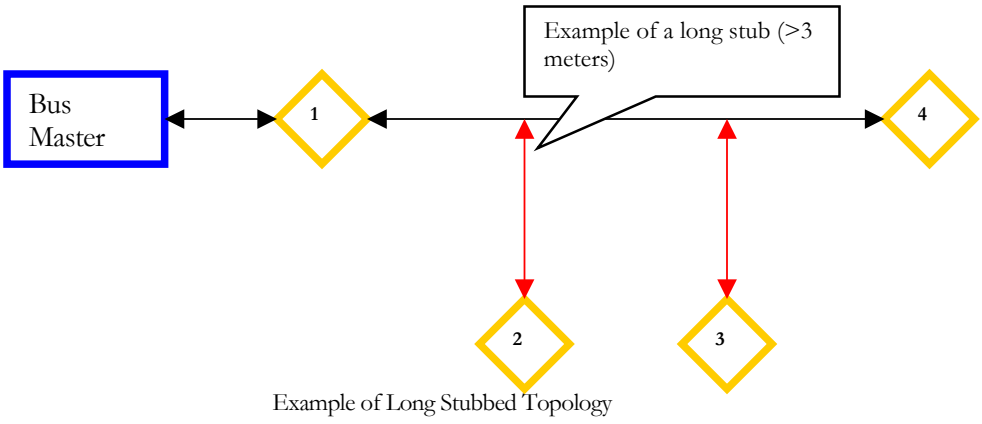
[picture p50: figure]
Example of Long Stubbed Topology; Example of a long stub (>3 meters); Bus; Master

In this example slave devices 2 and 3 are connected to the network with cable lengths > 3 meters.

In a long stub network, lengths of wire (> 3 meters) connect the slave to the 1-Wire network bus. This can be seen in connections of slave number 2 and 3 in the above drawing. The devices are tapped onto bus that extends through the slaves 1 and 4 with long leads of wire. Many first time designers build their networks like this because of the physical ease in doing so. However, this form of network can lead to severe problems due to signal reflections. If the lengths are “just right” the network may work (because the signal reflections and cancellations have been “tuned”), but the slightest change to the network may cause it to fail again. Do not build this sort of network!

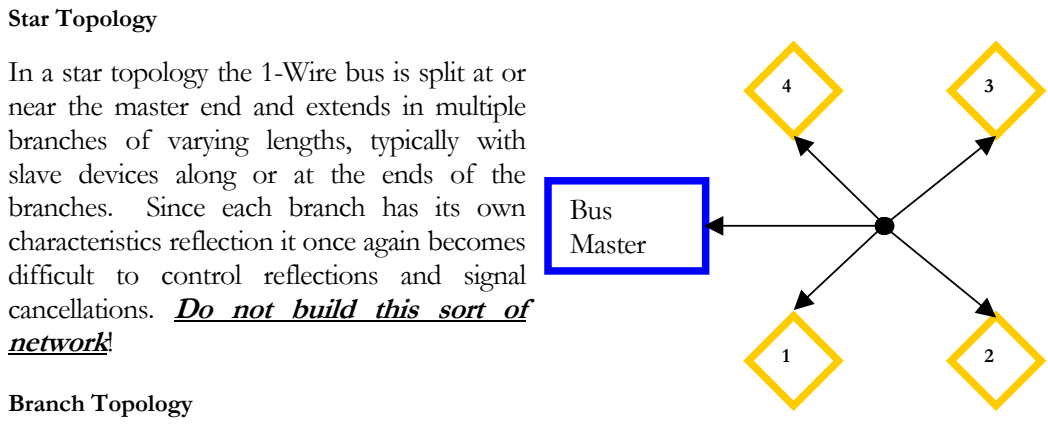
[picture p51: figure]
Star Topology; branches. Since each branch has its own; network!; Bus Master; Branch Topology

In a star topology the 1-Wire bus is split at or
near the master end and extends in multiple branches of varying lengths, typically with slave devices along or at the ends of the

characteristics reflection it once again becomes difficult to control reflections and signal cancellations. Do not build this sort of

Version 1.0 8/19/04 | 52

However branching topologies can be created. By using a device such as the DS2409 MicroLAN Coupler16 a 1-wire hub device, at the branch point, a tree structure is made. Branches made up of only wires (that is, without the supporting DS2409) are not considered branches but long stubs, and should not be used.

In this example the 1-Wire bus extends to the hub device, which splits it into two branches. Only one of which is active at any given time (If both were active then you would have created a stub) When a particular branch is active, only the slaves on that branch are available. So in essence the bus appears to be a linear topology at any given time.

This switched hub concept can be repeated as many times as needed (up to the limits imposed by the hub devices and the wire used to make the bus, since they add additional resistance to the bus each time) to develop a fuller “tree” with lots of branches.

Intermixing of topologies.
When different topologies are inter-mixed, it becomes even more difficult to determine the effects of signal reflections. As a general rule, don’t even think about it! Leave these forms of 1-Wire networks to experts on line transmission theory. While any given stub or star network configuration may work at a given time, they tend to become highly tuned networks, which may fail with the slightest change. Even a change in weather may be sufficient to change their operation.
Version 1.0 8/19/04 | 53

16 See the DS2409 Datasheet (http://pdfserv.maxim-ic.com/en/ds/DS2409.pdf) for more information on branching topologies

## SUMMARY

### Review of how 1-Wire communications works

Power is supplied to the 1-Wire slaves during idle communication periods and at bit times when the bus is in its default logic one (+5V) high state. During these bus high intervals, each slave stores energy by charging an internal capacitor that serves as its power source when the bus is in the logic zero (GND) state. Every slave also contains an internal oscillator that is synchronized by each falling edge of the data signal. The master reads and writes to a slave by pulling the line low for either long or short intervals that represent logic ones and zeros. A slave replies by continuing to hold the line in the logic zero state -or not- after the master releases it at which time a passive pull-up resistor pulls the line high.

In the case where a 1-Wire network is long enough that it is operating in a transmission line environment, additional ‘noise’ is created in the form of reflections at each discontinuity in the cable, such as a slave or connection, along the line and at its unterminated end. If this noise level (crosstalk, glitches, etc.) on the bus is sufficient to cause a slave to see an extra clock edge, the slave losses synchronization to the master and communication ceases or is no longer in synch with the bus master. If a simple 1-Wire device such as the DS2401 is affected, it simply loses communication with the bus master for that interval. However, if a slave that has control or memory functions is affected, not only could communication be lost, but the system adversely affected by unwanted changes to the slave’s function.

Working in a
transmission line
environment

Except in the simplest 1-Wire net, such as a single slave at the end of less than 2 meters of cable, it may take some careful planning or even tinkering to get a 1-Wire network to work acceptably due to transmission line effects. This is due to the 'bare-drain' I/O structure of the master and slave, which does not allow the line to be terminated. Further, some bus masters and all 1-Wire slaves have different characteristic impedance that does not match the 100Ω of the recommended CAT 5 cable. Worse, these impedance’s are neither specified or controlled and change dependent on logic state. In the case of a slave, the impedance exhibits three distinct values, a low value around 50Ω when in a logic zero state with a 5V supply; a very high impedance when the 1-Wire network is in a logic one state and a variable impedance when the internal capacitor is being charged through a 1KΩ resistor.

Planning is
important!

1-Wire networks provide for a unique class of unmatched low cost, long line multi-drop capable sensing. However, they do require careful planning and design to help ‘tune’ the system in order to help prevent signal integrity problems from occurring. Over the next few pages we will look at some of the things you should do (or be aware of) when designing and building a 1-wire network.

Version 1.0 8/19/04 | 54

## Rules to follow

### The Network

Network Design
Design your network on paper before you build it. Don’t forget to provide for any planned future devices.
1. Create a detailed drawing of your network design. Besides being very useful for reference purposes this makes it much easier if you need to ask someone else about your network. Keep good records, such as when you added or changed a component or a part in your network. While some 1-Wire devices may last for a lifetime, others may have a much shorter lifetime and may need to be replaced on a regular schedule. Things like batteries, and iButtons have a definitive lifetime associated with them. So good records can ease your maintaince worries.
2. Use a linear topology for your network. Do not use a ‘star’ or long stub architecture.
3. Calculate total device and cable capacitance values.
4. Figure out power requirements for the network. While power over the same cable as 1-Wire is not optimum it can be used with care.
a. 1-Wire devices are VERY susceptible to power transients due to the long time they may be in the indeterminate state (especially with long slew rates). So clean and noiseless power is highly recommend. The rising edge time in slave devices is of particular concern since voltage transients on the data bus can cause false clocking of the slave devices.
b. While parasitic power can be very attractive, it can lengthen the response time in some devices like temperature sensors and does not allow mass temperature conversions. Consult the individual datasheets as needed to understand these issues and the trade-offs.
c. When designing a network based on parasitic power, be sure to keep track of the total power requirements needed and check that you will be able to supply sufficient power to all the 1-Wire devices on the network. We suggest you add in a safety margin of at least 22%.
5. Figure out any power grounding issues. Help avoid ground loops by making sure there is only one network ground point back at the bus master device.
6. For outdoors installations, figure out how you are going to protect the network, from nature and induced man made EMI. (Lightning, power lines, etc)
Version 1.0 8/19/04 | 55

7. Build into your design logical protection points such as the transition from indoors to outdoors. Or the interface to the bus master. Don’t forget you may have expensive equipment to protect from the network and vice versa. Expect a worst-case scenario to happen eventually, (like a direct or a nearby lightning strike1718.).
8. Avoid fractional integer nodal points on the bus for slave devices
a. Avoid placing slaves at integer fractions of the cable length, as communication can prove unreliable at those positions due to interaction of reflections and resonance
effects. (Read about wavelength effects this here)
9. If the complexity of your network demands it, consider using a 1-Wire HUB19 multiplexer to split the network into branches. This creates a tree like topology with hub devices at the branch junction. In this way you can address a particular branch of your network. This can have several benefits:
- Logical clusters of similar devices
- Possible logical/physical device orientation instead of individual slave devices. For instance you can create an instrument cluster behind a HUB device that can be uniquely addressed. Or a named bus segment (i.e. The flag pole instruments for example, which again could be turned on or off as needed).
- Shorter total cable length (less capacitance due to shorter cable and fewer slaves on the network at a given time). Since only the branches that are turned on are enabled this helps a large system still appear and respond like a smaller system. A branch for instance could be a collection of temperature sensors in a particular location
- If temperature sensors are powered instead of using parasitic powered you can also do quicker temperature conversions along with mass conversions. All sensors on the branch can be told to do a temperature reading at the same time, and then each one quickly read one at a time.

17 For a circuit for 1-wire transient protection (http://www.simat.enta.net/transprot.html)

18 One discussion about Lightning Protection can be found in the Weather Station FAQ (http://www.ibutton.com/weather/fdbk3.html)

19 Hub multiplexers are available from several manufactures (consult the manufactures list on www.1wire.org for manufactures of units) or you can make your own using a DS2409 chip.

Version 1.0 8/19/04 | 56

- Better protection of the network against total network failure.
- When using a DS2409 as the HUB device, it offers some short circuit protection for the network. A shorted bus segment (maybe caused by a failed instrument or sensor) is automatically taken off the bus so the entire network does not fail, only that segment or branch of the network.
- It is also possible to use DS2409 HUB chips to help determine physical location of devices through a technique called “Chain Sequencing”20

While there are several commercial hubs available, most hubs are built around the DS2409 MicroLAN Coupler. Since the DS2409 adds resistance to the data path (like putting a resistor in series with the data line) care must be used in designing your network. Each time you add resistance in the data path you effectively raise the logic level 0 base data floor and decrease noise immunity. Note that there is a difference between the DS2409 data channels. The Main data branch has a resistance of 10 ohms while the AUX path has a resistance of 13 ohms. Be sure to include this value in your network calculations. And do your calculations for each branch

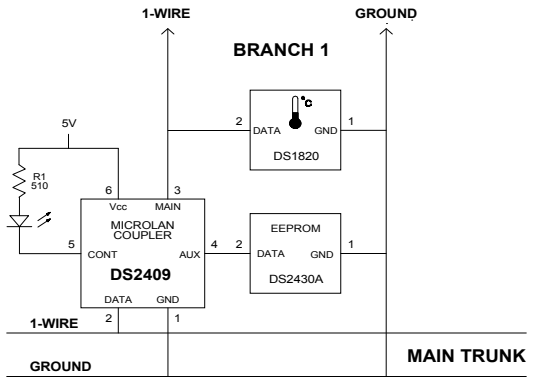
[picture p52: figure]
AUX; 4 CONT; DATA 2; Vcc; GND 1; MAIN; MICROLAN COUPLER; DATA; GND; 1 DATA; EEPROM; GROUND; 1-WIRE; MAIN TRUNK; BRANCH 1

Separating the 1-Wire bus into branches using the DS2409 MicroLAN Coupler

20 See the document Chain sequencing to electronically determine sequence

Version 1.0 8/19/04 | 57

Cable planning
1. Use High quality CAT5E or better, twisted pair cable (unshielded). Install it following good CAT wiring practices.
2. Follow a standard wiring scheme for all your 1-Wire wiring.
a. There are currently two standards available (links to both are available at www.1wire.org.
i. The Original RJ11/12 standard

ii. And a Proposed 1WRJ45 standard for RJ45 connections

3. Any unused wires in the 1-Wire cable should not be terminated. Because grounding unused conductors will increase the capacitive load seen by the line master, Dallas Semiconductor recommends that unused wires and shields be left unconnected at both ends of the cable. The wires should be left floating.
a. A look at some cable properties will help in understanding how such an arrangement affects the 1-Wire network performance. In a CAT 5 cable with multiple twisted pairs, on average any given conductor in a pair is adjacent to a second conductor in another pair for half its length. Typically, the capacitance seen between the two conductors of a twisted pair is approximately 50 pF/m while that between the conductors of two different pair runs about 30 pF/m.
b. If you must use flat ribbon cable (which is not recommended) flat 6-conductor phone (silver satin) may be used up to about 200 feet. Follow the Dallas standard21 for this sort of cable.
i. This arrangement helps shield the critical DATA lead from the additional capacitive load and cross talk of the external power leads. Note that the two conductors prior to the 1-Wire DATA line are to be left uncommitted. As previously emphasized, if connected they will substantially increase the capacitive load seen by the DATA line.
1. One possibility is to use 4- conductor silver satin and assemble the cable with these two slots in the RJ11 connector empty.
2. Unfortunately, a significant disadvantage of flat cable is that it lacks the noise rejection properties of twisted

21 See Dallas RJ11/12 standard here

Version 1.0 8/19/04 | 58

pair cable, so EMI can be a significant performance problem if the network is routed near sources of electrical noise.

3. If power is to be routed over flat phone wire along with 1-Wire DATA and GND, use the outer two conductors by 1-Wire GND to minimize cross talk and capacitive loading.
4. Quality of the cable can vary quite a bit depending on the manufacture. Think of moving toe CAT5 cable instead.
4. Use the same type of cabling for the entire network. Preferably the same cable. This helps avoid manufacturing impedance mismatches.
a. For Belden 1588A, each pair has a different number of twists. Use the blue blue/white pair for the 1-Wire network since this pair has the most twists. If using a CAT5 cable from another manufacture, examine the twist count for each pair and use the pair that has the most twists per inch. Document if you do this or any other deviation from one of the wiring standards.
5. We suggest that you follow some sort of in-house plant color scheme to help keep track of your 1-Wire cables. By selecting a particular color cable for your entire plant for your 1-Wire cables you can help different it from other twisted pair cables you may have. So you could reserve orange for instance for 1-Wire cables and some other color for your Ethernet cables. The important thing is to document this and be consistent.
a. Where possible add your standard wiring chart to the inside of any device cases for reference, this can make it during future maintenance for proper wiring connections and standards to be maintained.
6. Try to avoid routing 1-Wire cables near strong EMI fields such as motors. Remember the 1-Wire cable acts as an antenna. Any induced noise on the cables often presents problems. This noise, generally show up as an increased data transmission error rate (or no data transmission at all). Typically control of the slope of the transitions between logic levels is used to minimize cable transmission line reflection noise. Induced power spikes on the cabling can be of fairly low energy levels that only lead to transmission errors. Or the noise can be large enough potentially to create fatal voltage/current spikes or glitches, which can cause premature hardware failure. These spikes can often slowly stress or destroy the built in chip protection devices on board the 1-Wire network circuitry. Generally higher energy levels (such as lightning or
Version 1.0 8/19/04 | 59

electrical surges22) induced from remote events (or nearby electrical fields) are often the cause of this sort of noise and are more likely to lead to total part failure.

7. For common mode RF interference reduction, try looping the 1-Wire cable through a single ferrite toroid core a few times. You can experiment with the size of the toroid and how many turns you need for the desired suppression. You should experience little or no signal loss in the 1-Wire bus itself.

General
1. Have backup components in case of failures (having a backup bus master and a known good working cable can be very useful for trouble shooting device problems).

22 1-Wire Surge Protection (http://pond1.gladstonefamily.net:8080/surge-protection.html) ideas from Philip Gladstone

Version 1.0 8/19/04 | 60

### The Devices

Bus Masters
Configure the circuitry of the bus master so that it maintains constant impedance equal to that of the cable impedance. For example since the recommended CAT 5 cable has an impedance of 100Ω, use a bus master with a 100Ω impedance, or add circuitry to the existing one to meet 100Ω.

Select a bus master suitable for your needs. Extensive 1-Wire bus testing has produced data on working limits that should be observed when using the available standard interface devices listed below. The following includes suggested limitations that should be observed when designing 1-Wire networks with these masters:

2. We recommend the bus masters based on the advanced network driver described in the Dallas Application note #244. The Advanced Bus Interface is a specially designed circuit for use with large and small 1-Wire networks. It has special provisions to operate reliably when connected to a network with high weight and radius values, up to 500m.
a. The LINK is a good implementation of this and has many advanced features besides the driver.

The Link Interface
uses a Advanced
Bus Interface
i. These are:
1. Better timing selection for sample points
2. Relaxed timing
3. Uses a higher threshold logic 0 switching point (1.2 to 1.6 volts) than the 0.8 volts of the Dallas specification. This allows greater noise immunity (at the cost of not being exactly in spec)
4. Multiple sample point tests (best 2 out of 3) to help overcome possible noise at sample point time.
b. Be aware that the LINK uses an RS232-E interface so check for compatibility with your system before use.
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

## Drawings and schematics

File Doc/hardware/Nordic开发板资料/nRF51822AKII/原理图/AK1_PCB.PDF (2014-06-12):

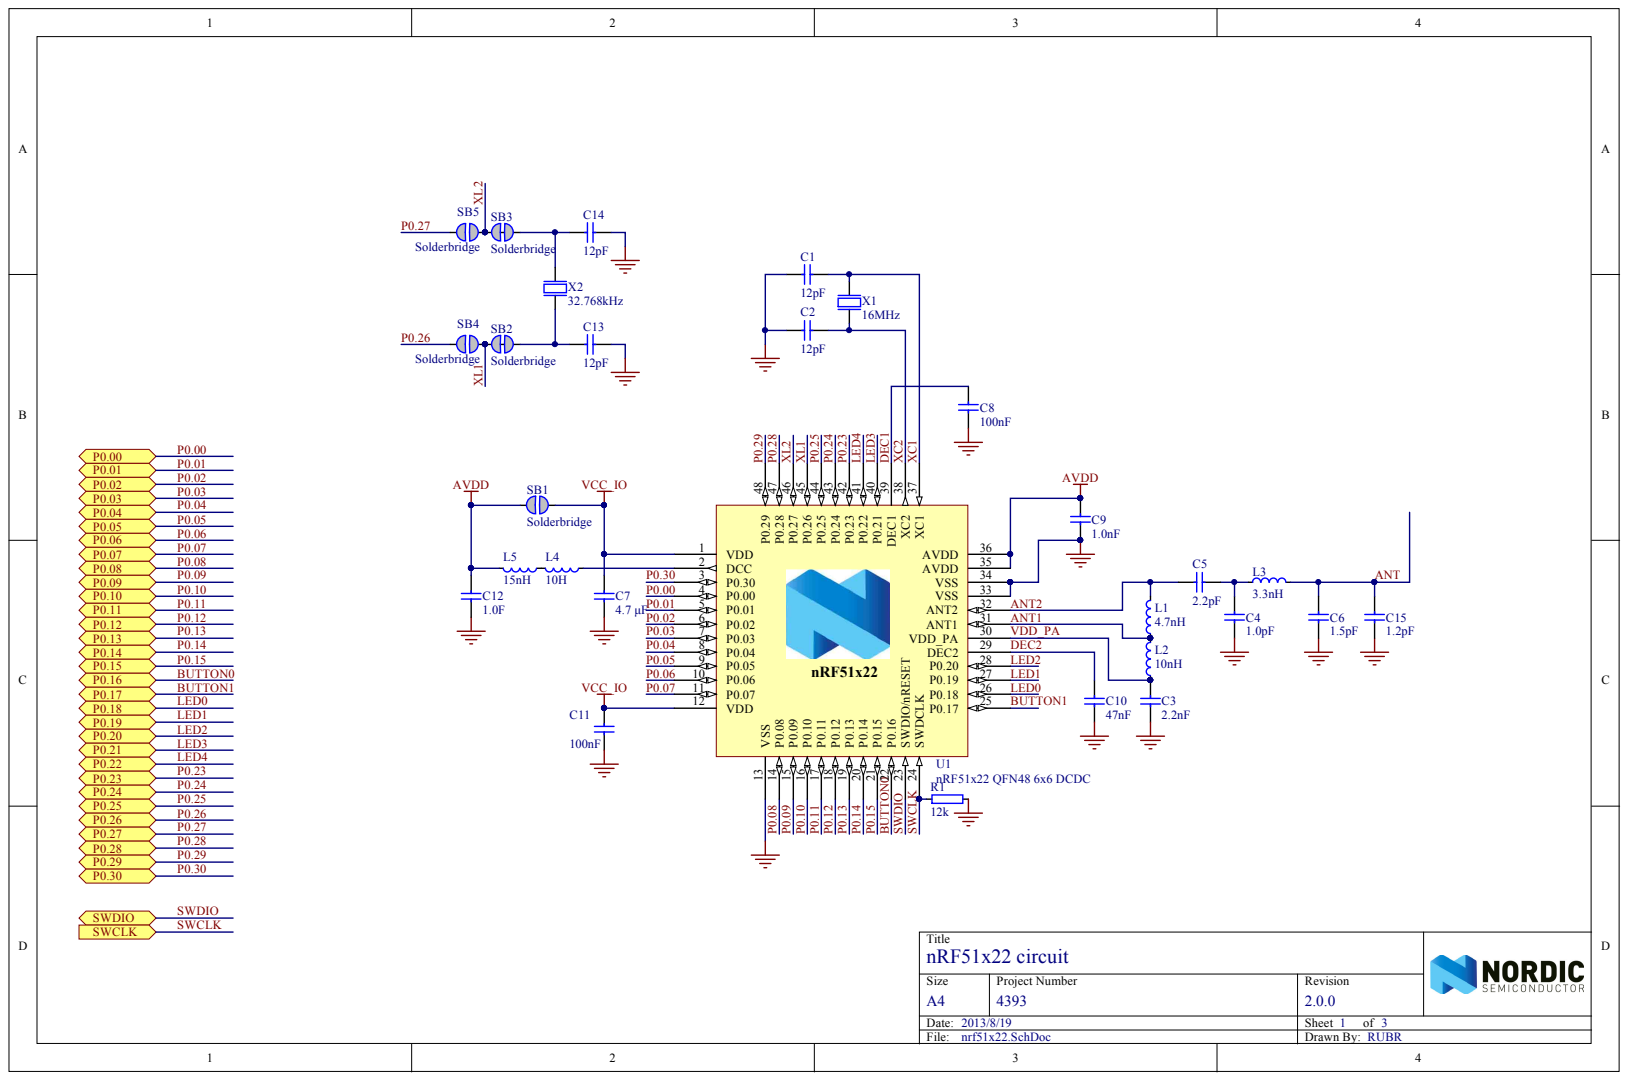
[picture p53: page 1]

VDD_P A
DEC 2
LED2 LED1

Title Size nRF51x22 circuit

A4 | P roje ct Numbe r 4393 | R evision 2.0.0

Date : | She et 1 of 3
File : nr f51x22. S chDoc | Dr awn By: RUB R

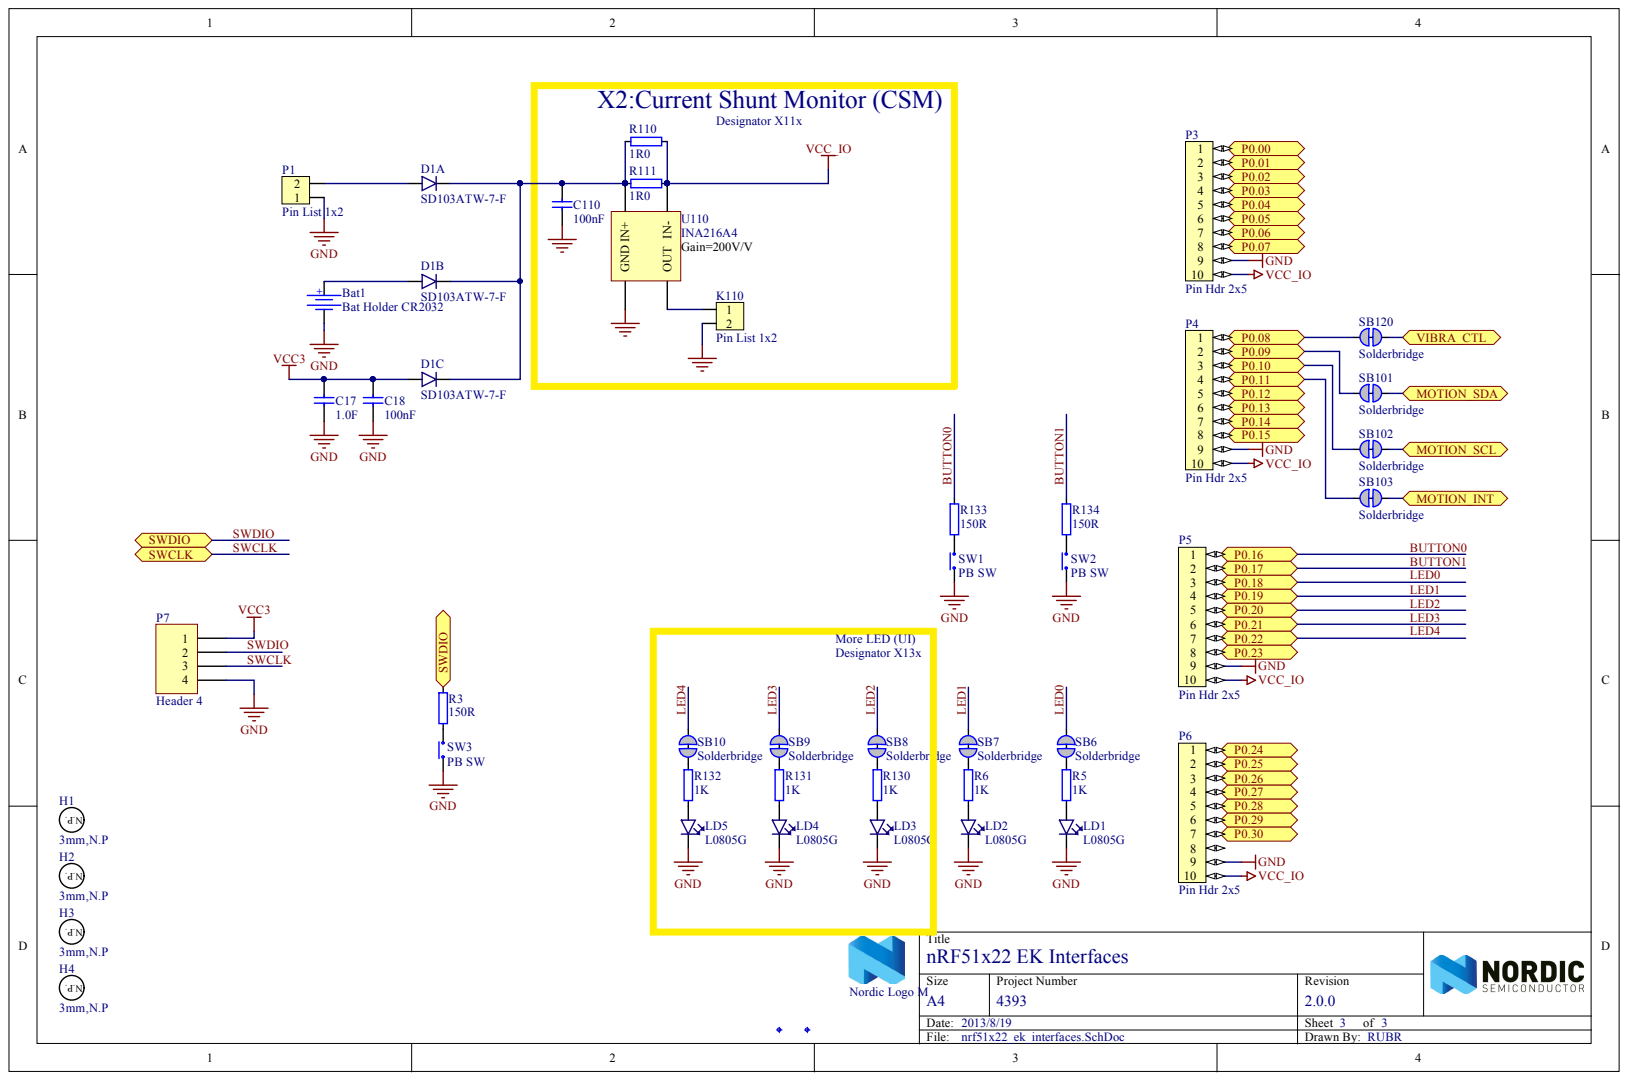
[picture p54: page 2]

X2:Current Shunt Monitor (CSM) Designator X11x

Title Size nRF51x22 EK Interfaces

M A4 | P roje ct Numbe r 4393 | R evision 2.0.0

: | 3 3
: nr f51x22_ek_inte r fa c es. chDoc | Dr RUB R

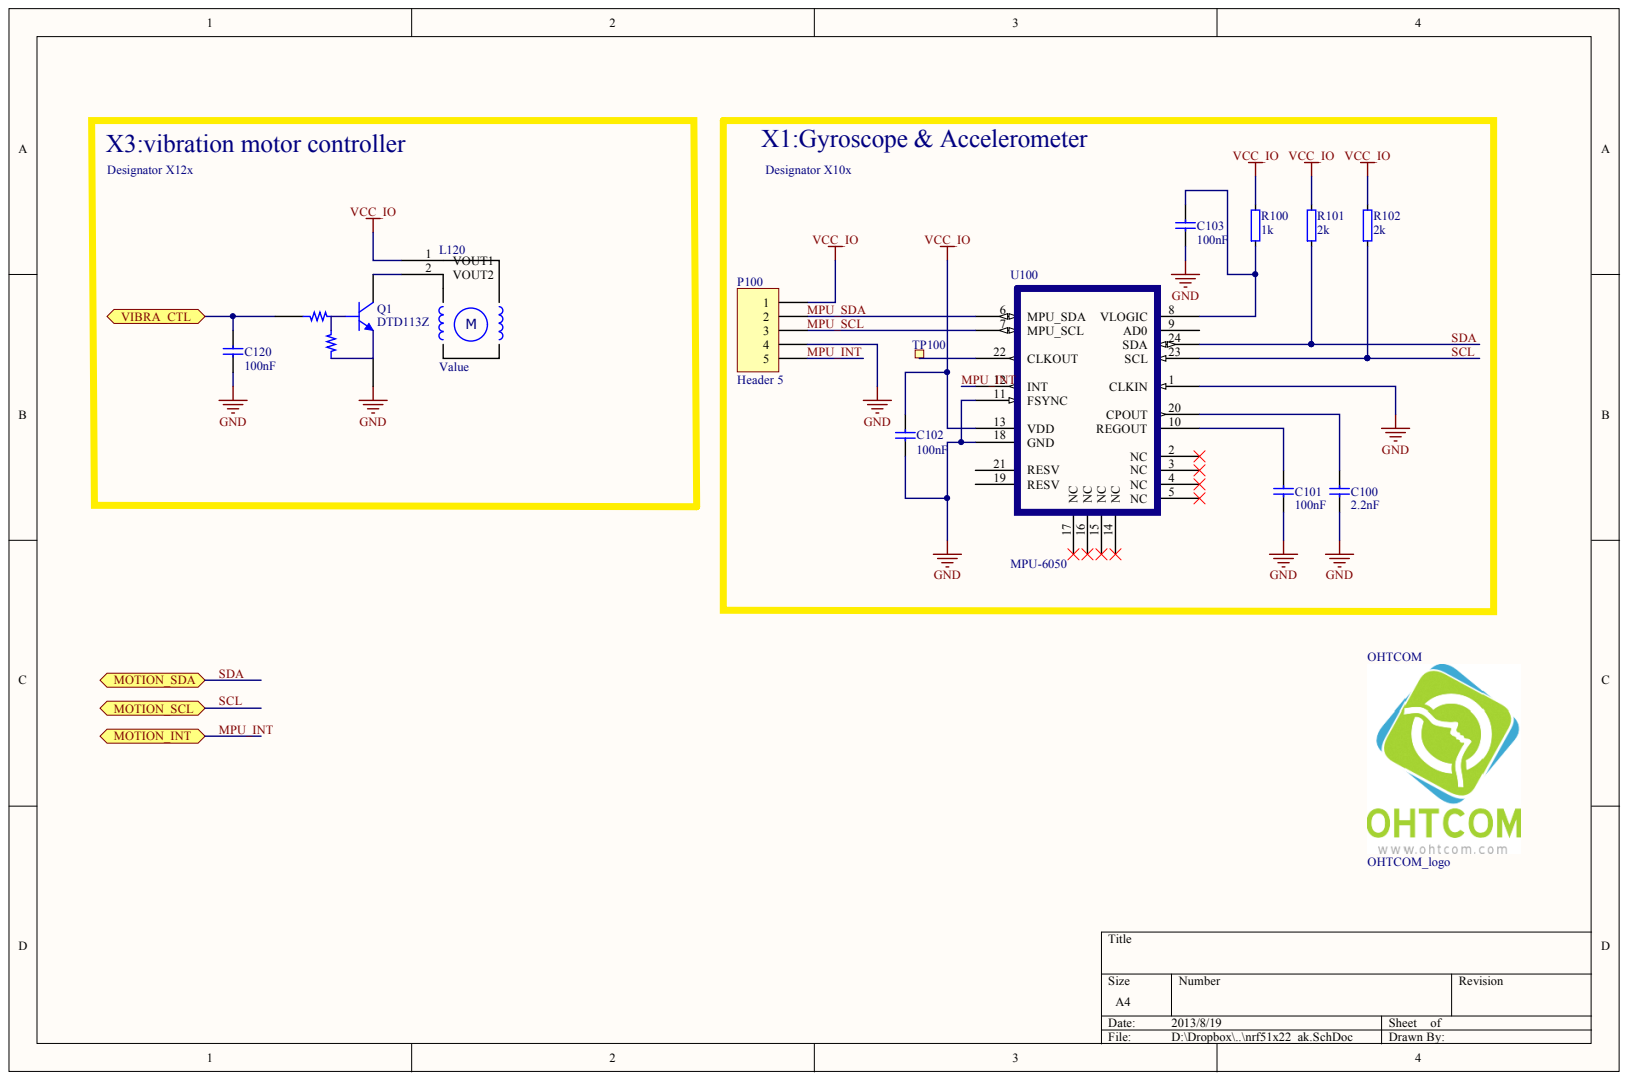
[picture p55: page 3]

VDD 13
GND 18 RESV 19

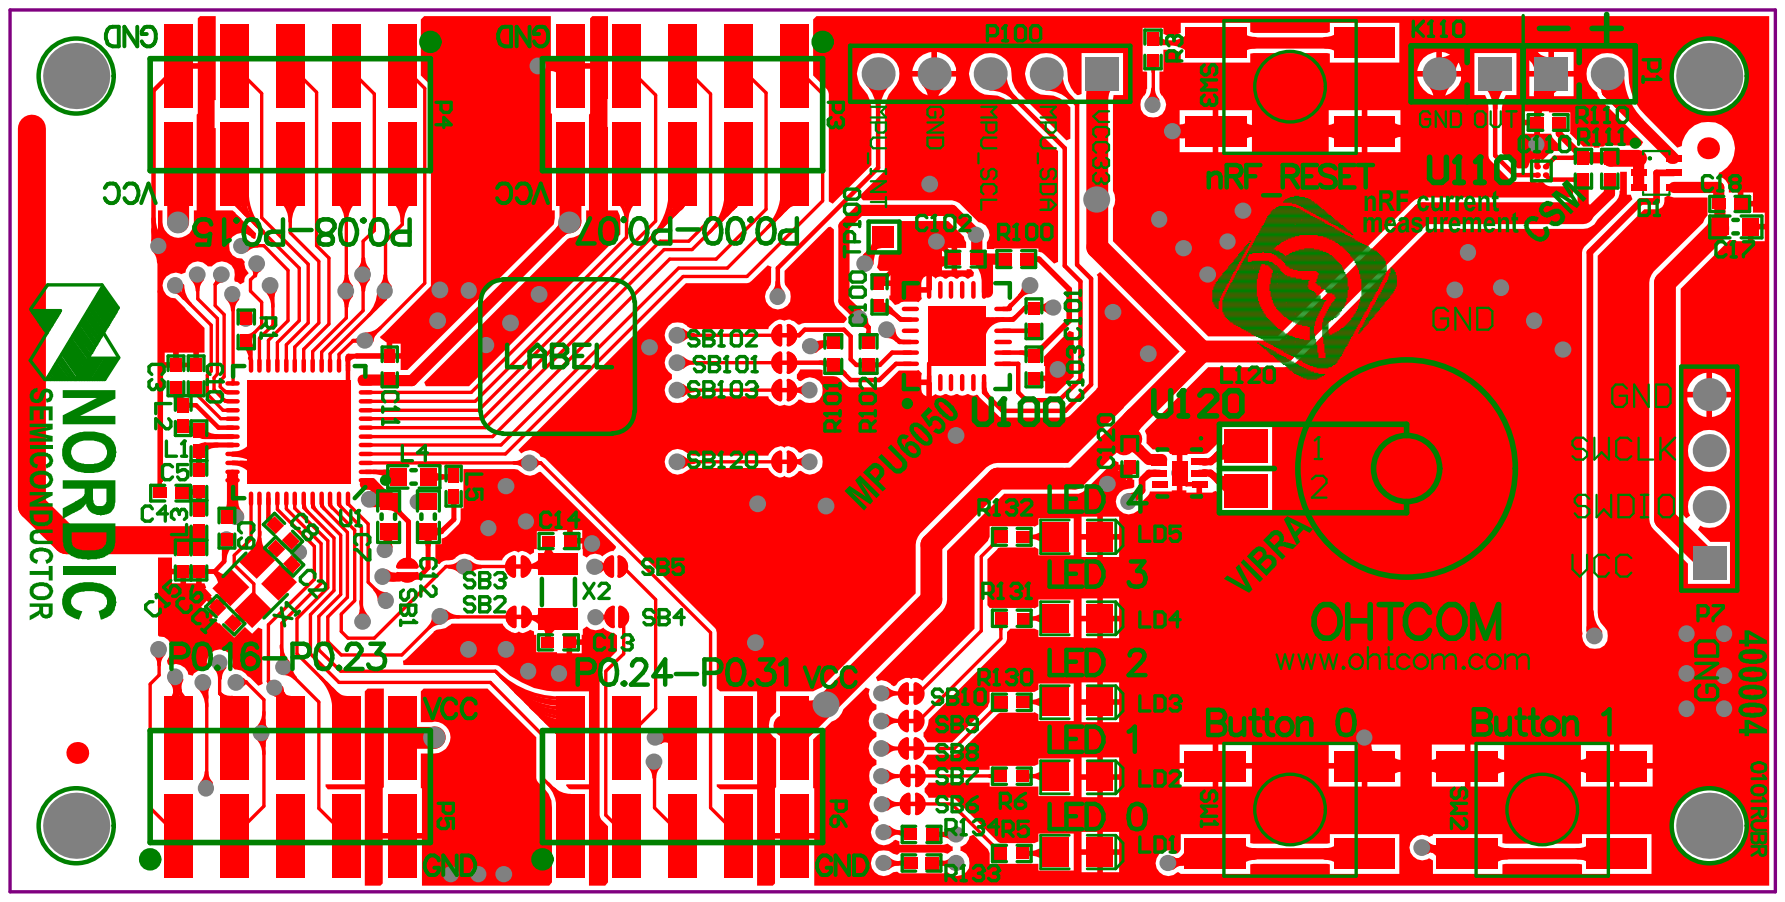
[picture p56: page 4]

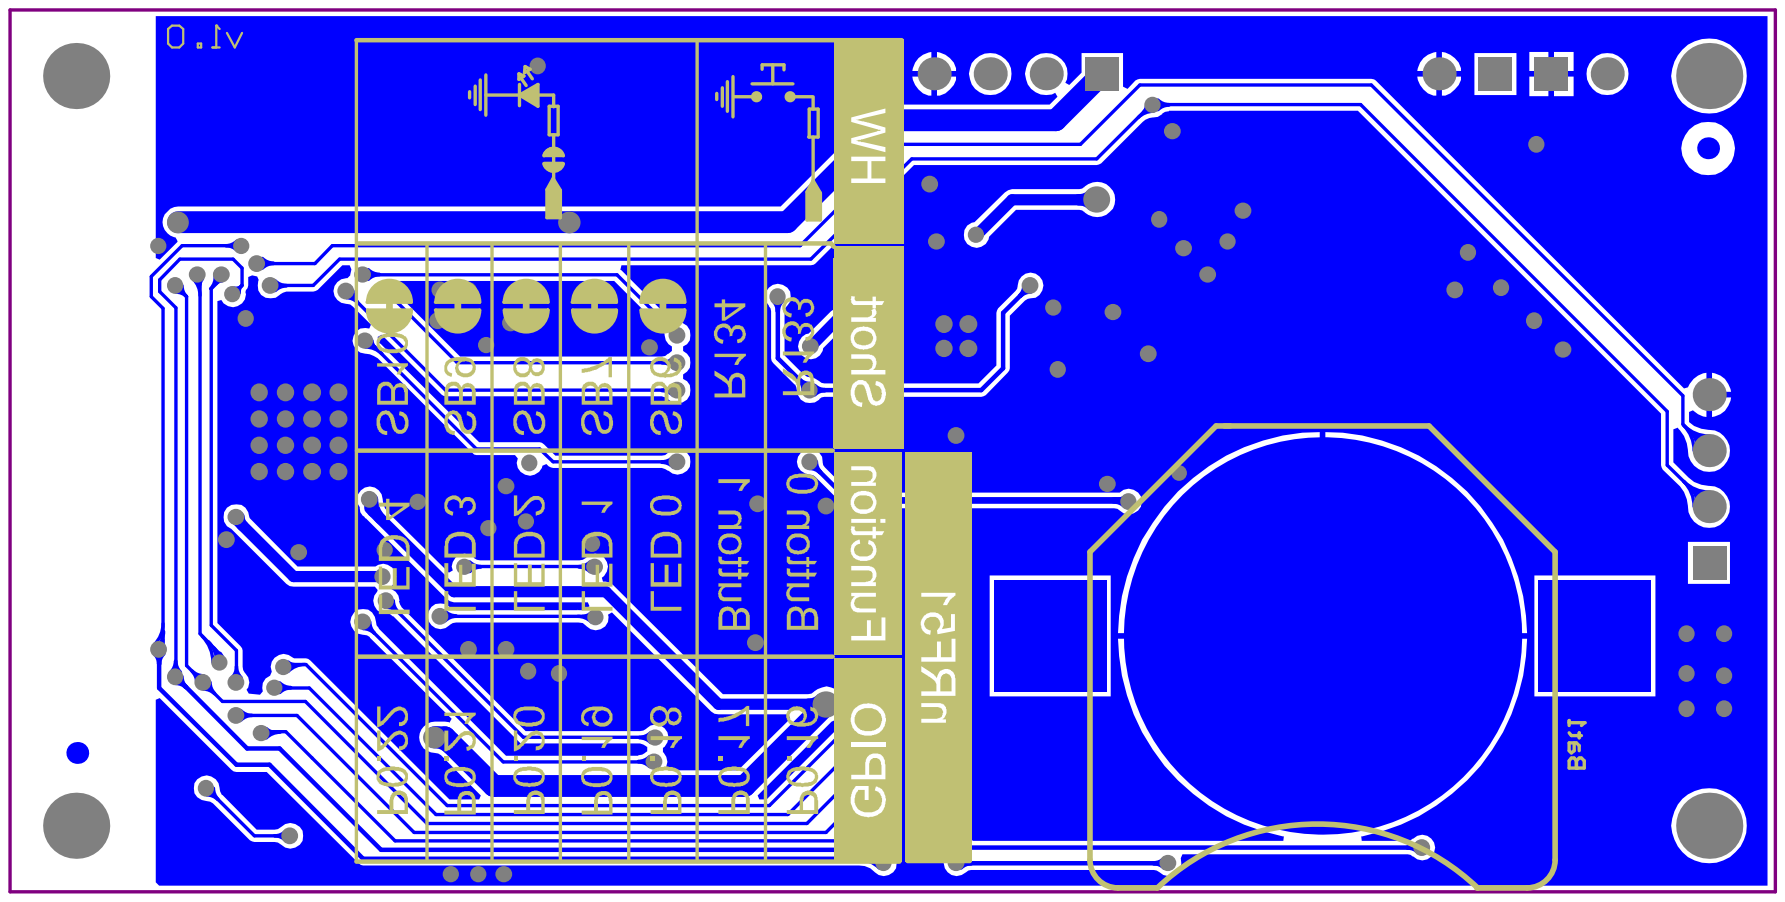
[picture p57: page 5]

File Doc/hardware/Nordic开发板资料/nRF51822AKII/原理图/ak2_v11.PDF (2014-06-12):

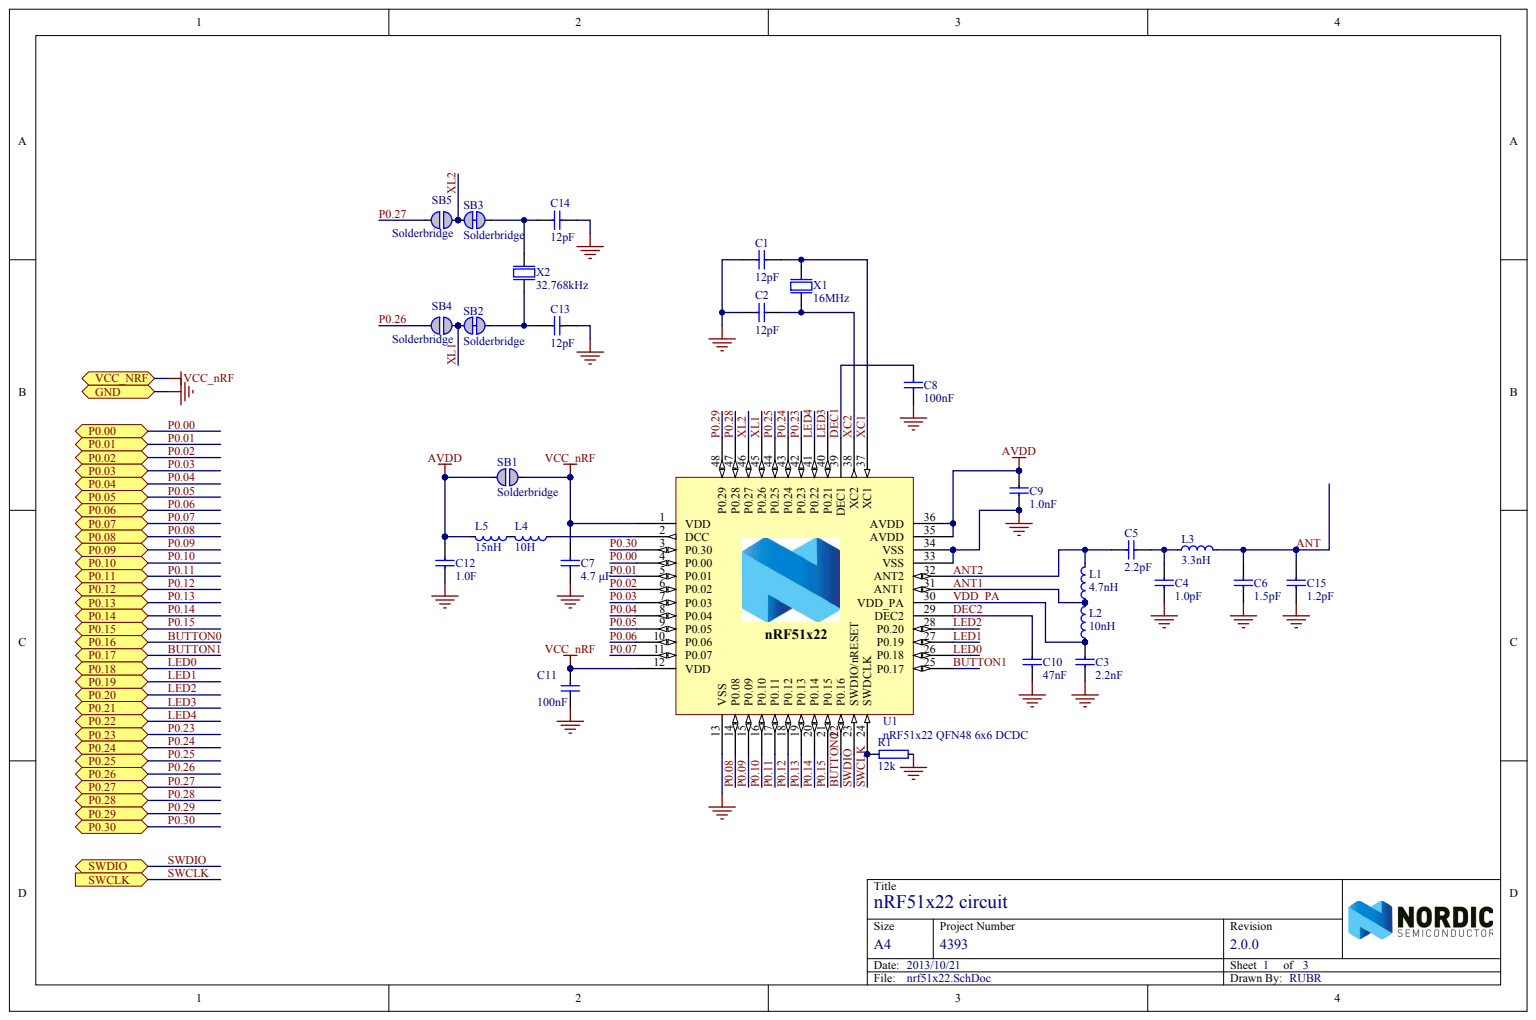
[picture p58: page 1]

VDD_PA
DEC2
LED2 LED1

Title nRF51x22 circuit

Size A4 | Project Number 4393 | Revision 2.0.0

Date: 2013/10/21 | Sheet 1 of 3
File: nrf51x22.SchDoc | Drawn By : RUBR

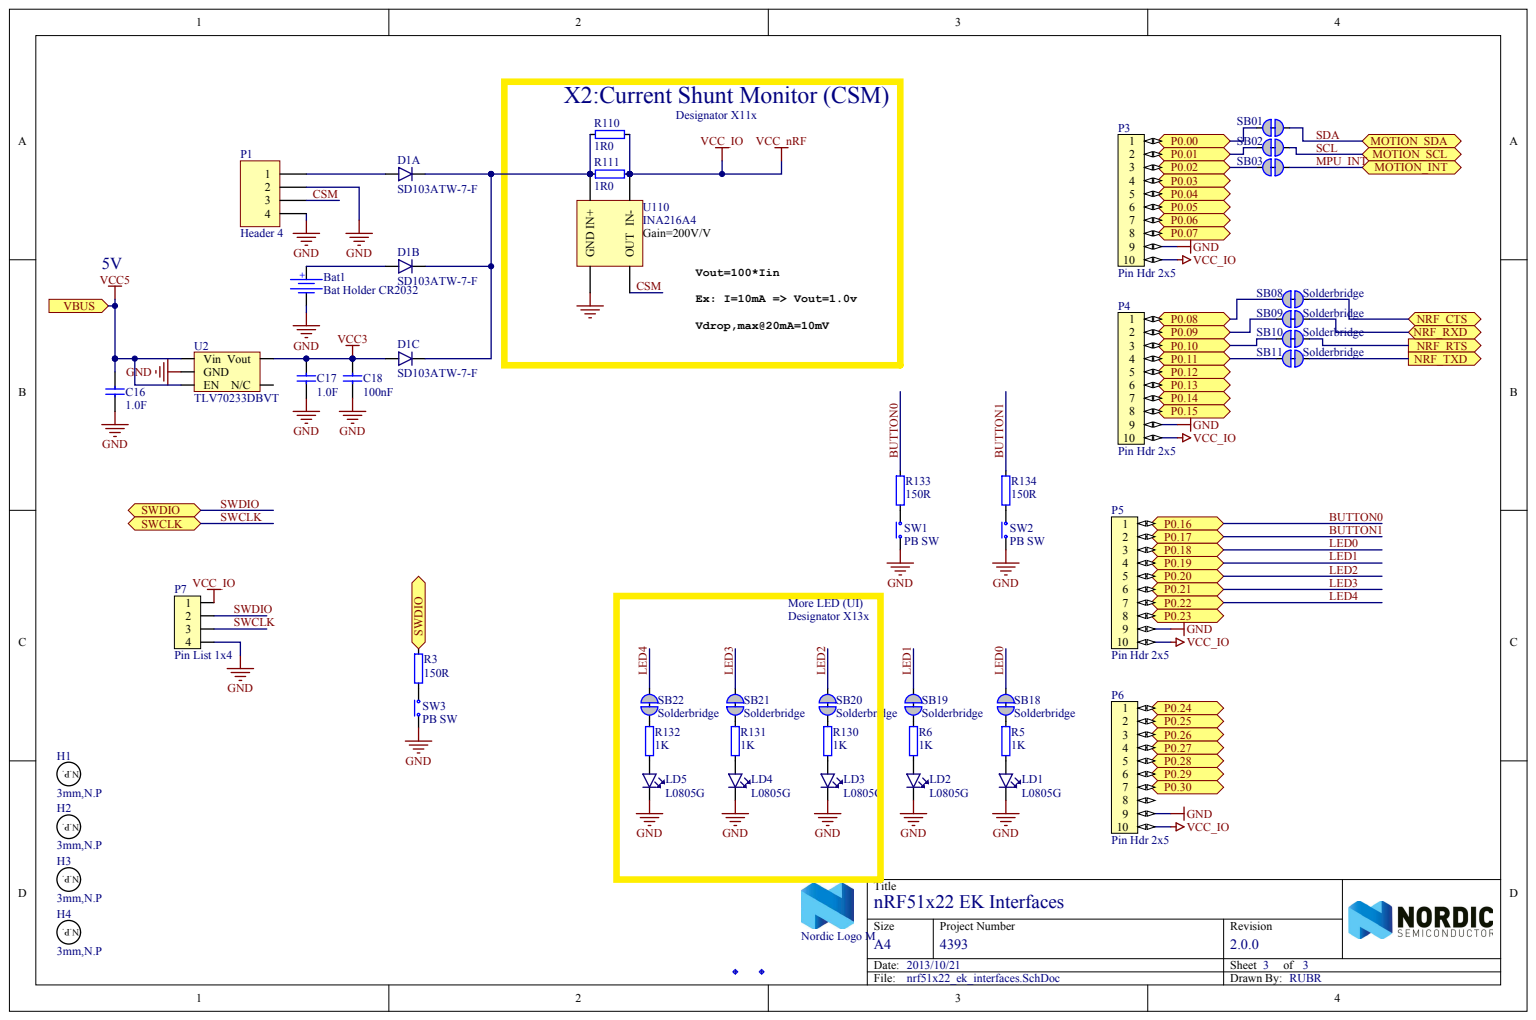
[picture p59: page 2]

X2:Current Shunt Monitor (CSM)

Title nRF51x22 EK Interfaces

Size A4 | Project Number 4393 | Revision 2.0.0

Date: 2013/10/21 | Sheet 3 of 3
File: nrf51x22_ek_interfaces.SchDoc | Drawn By: RUBR

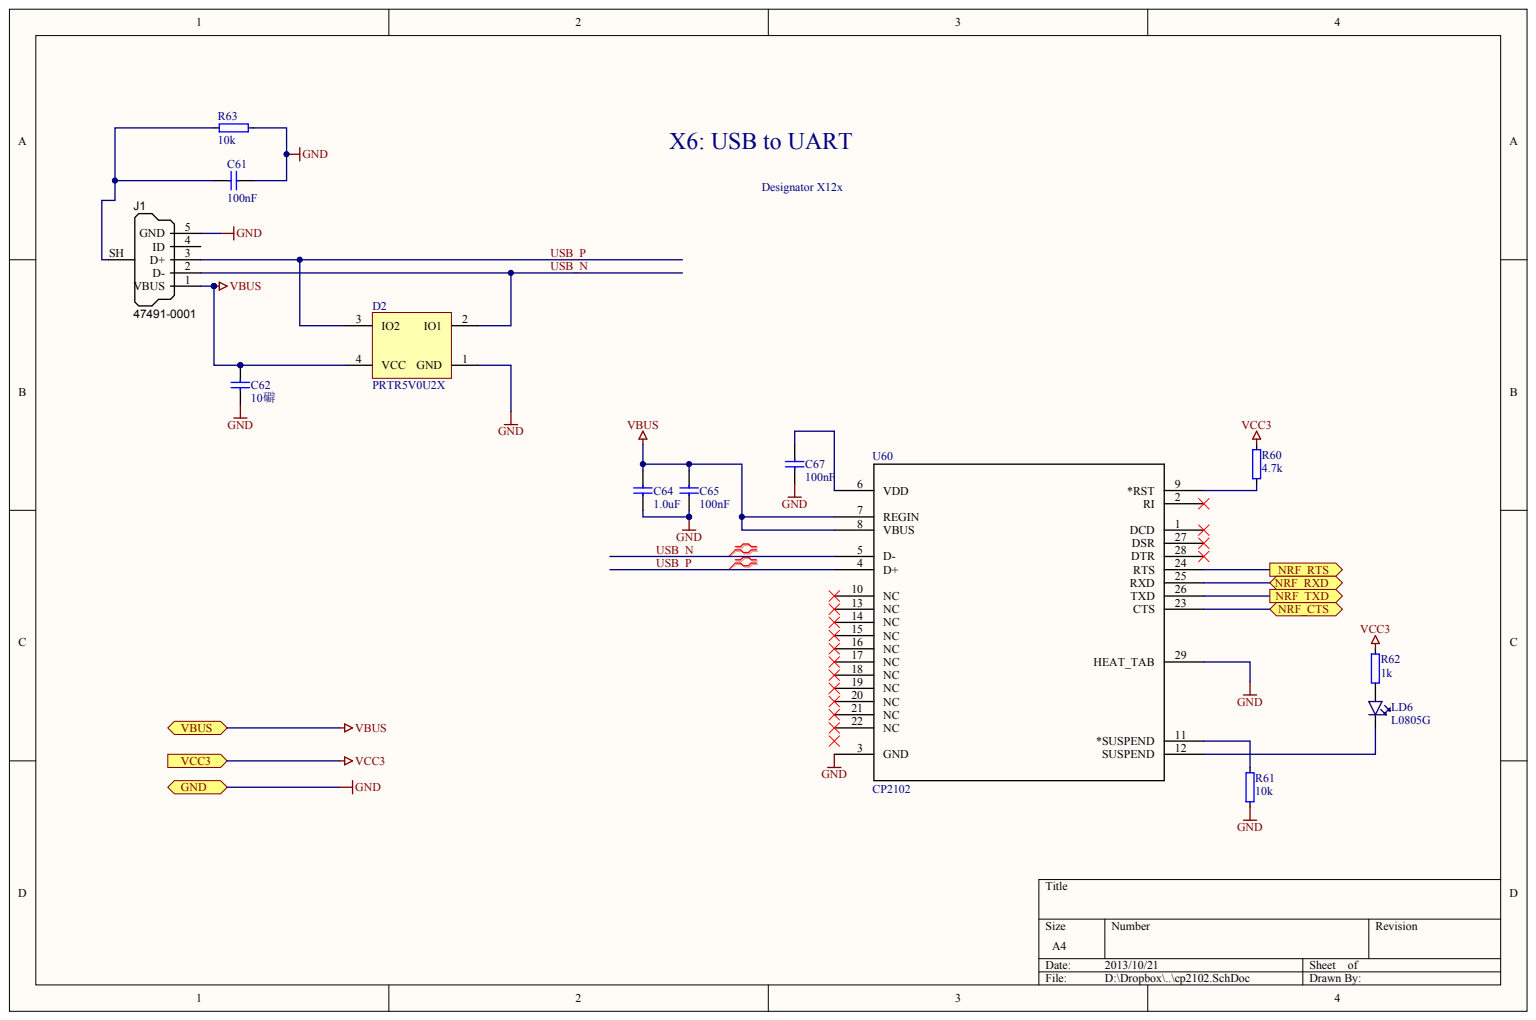
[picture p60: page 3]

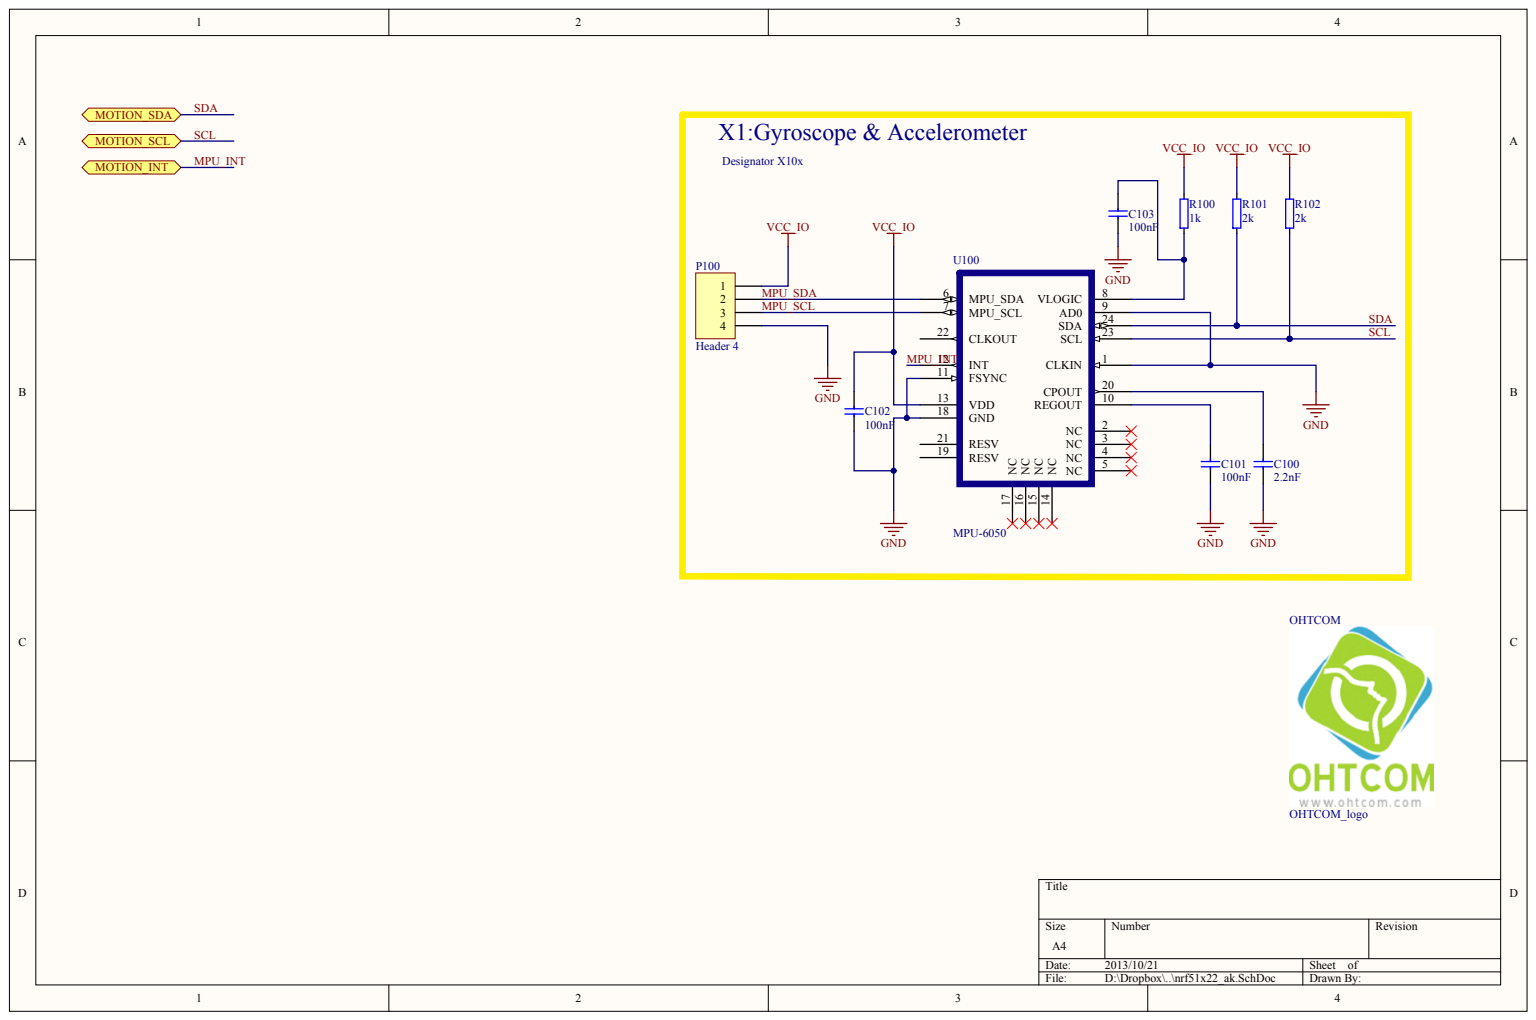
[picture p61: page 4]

VDD 13
GND 18 | 2

RESV 21

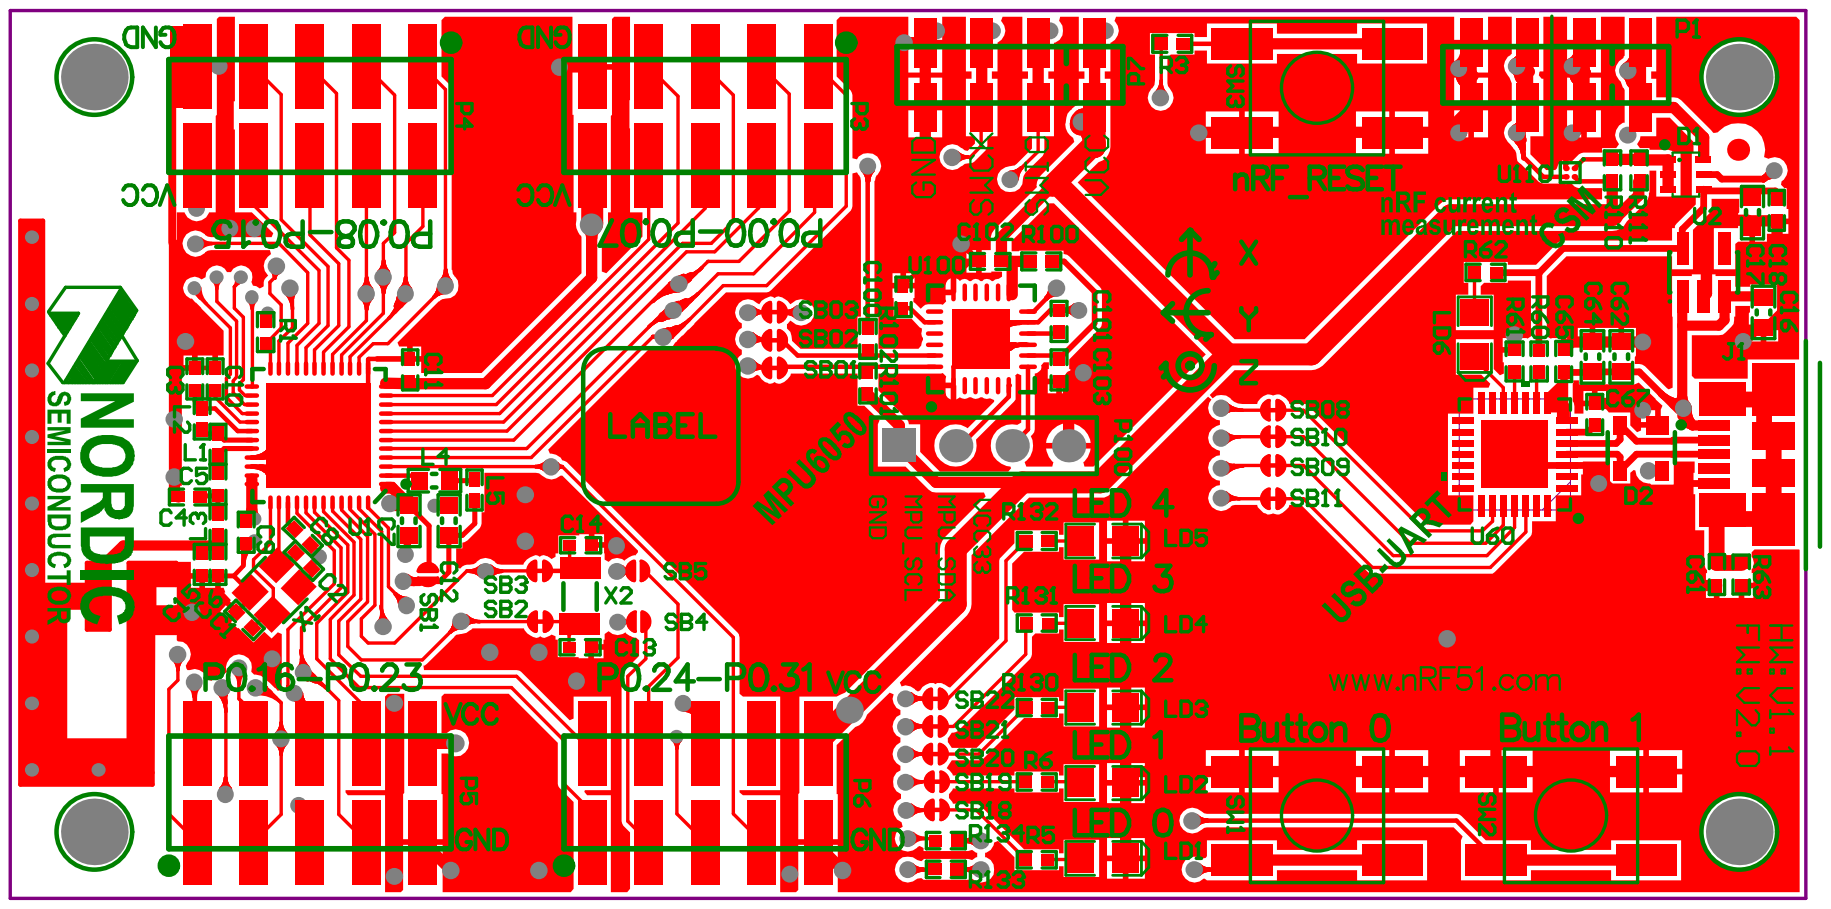
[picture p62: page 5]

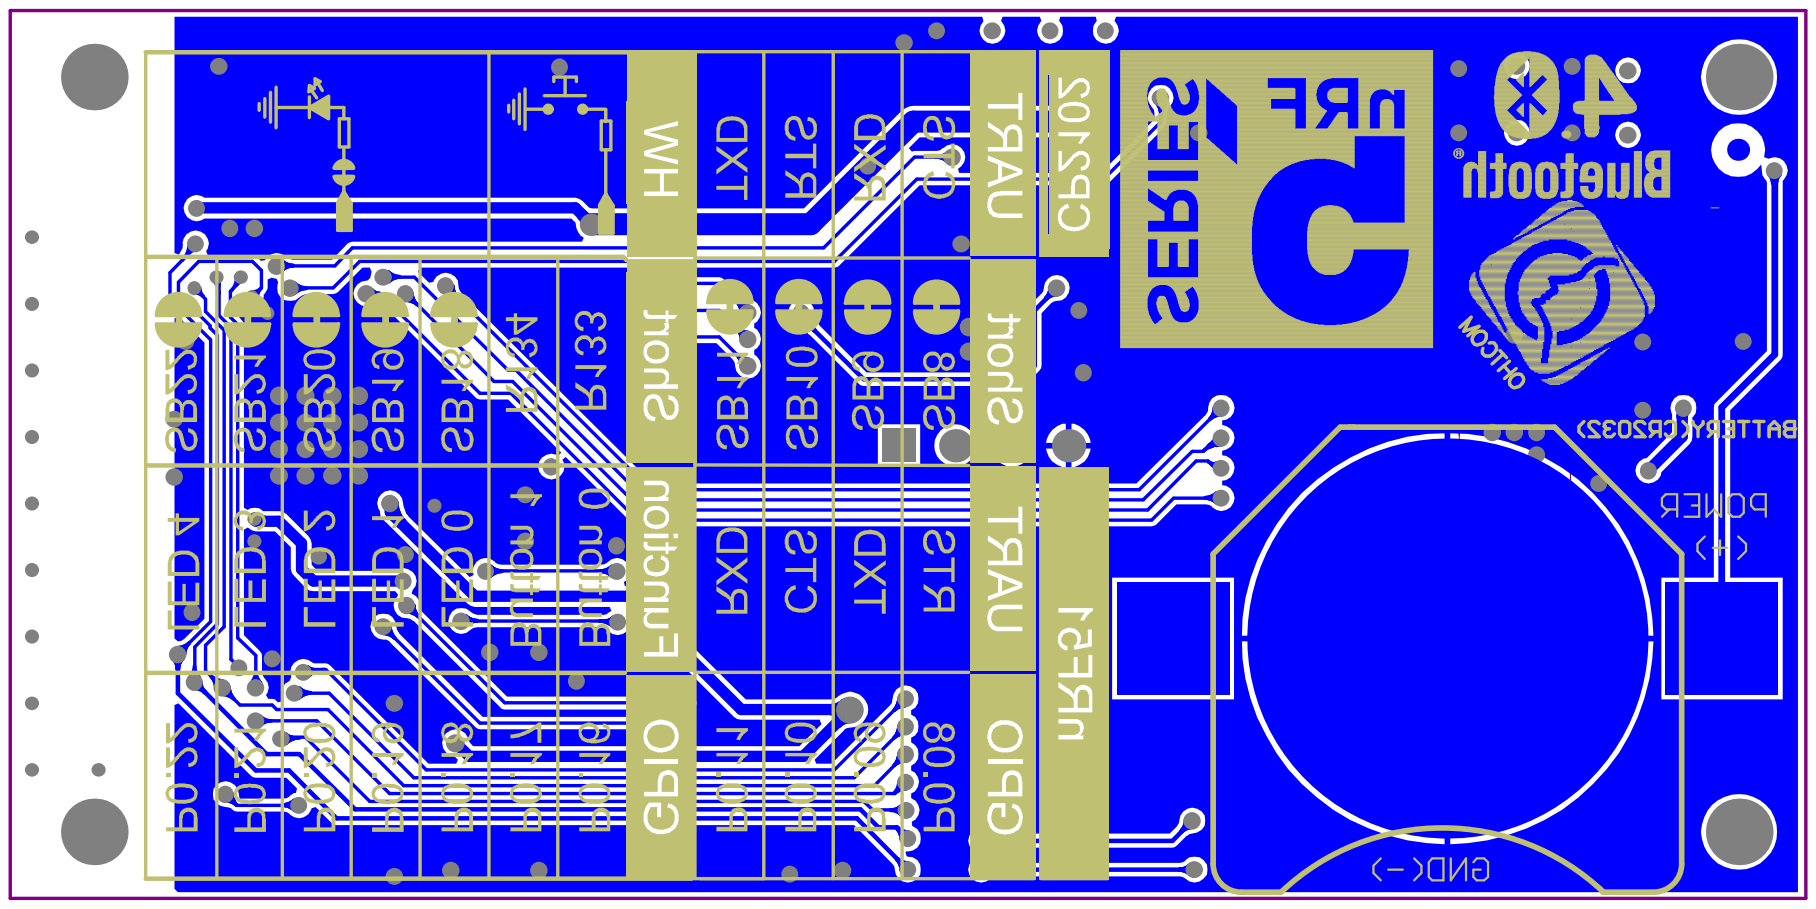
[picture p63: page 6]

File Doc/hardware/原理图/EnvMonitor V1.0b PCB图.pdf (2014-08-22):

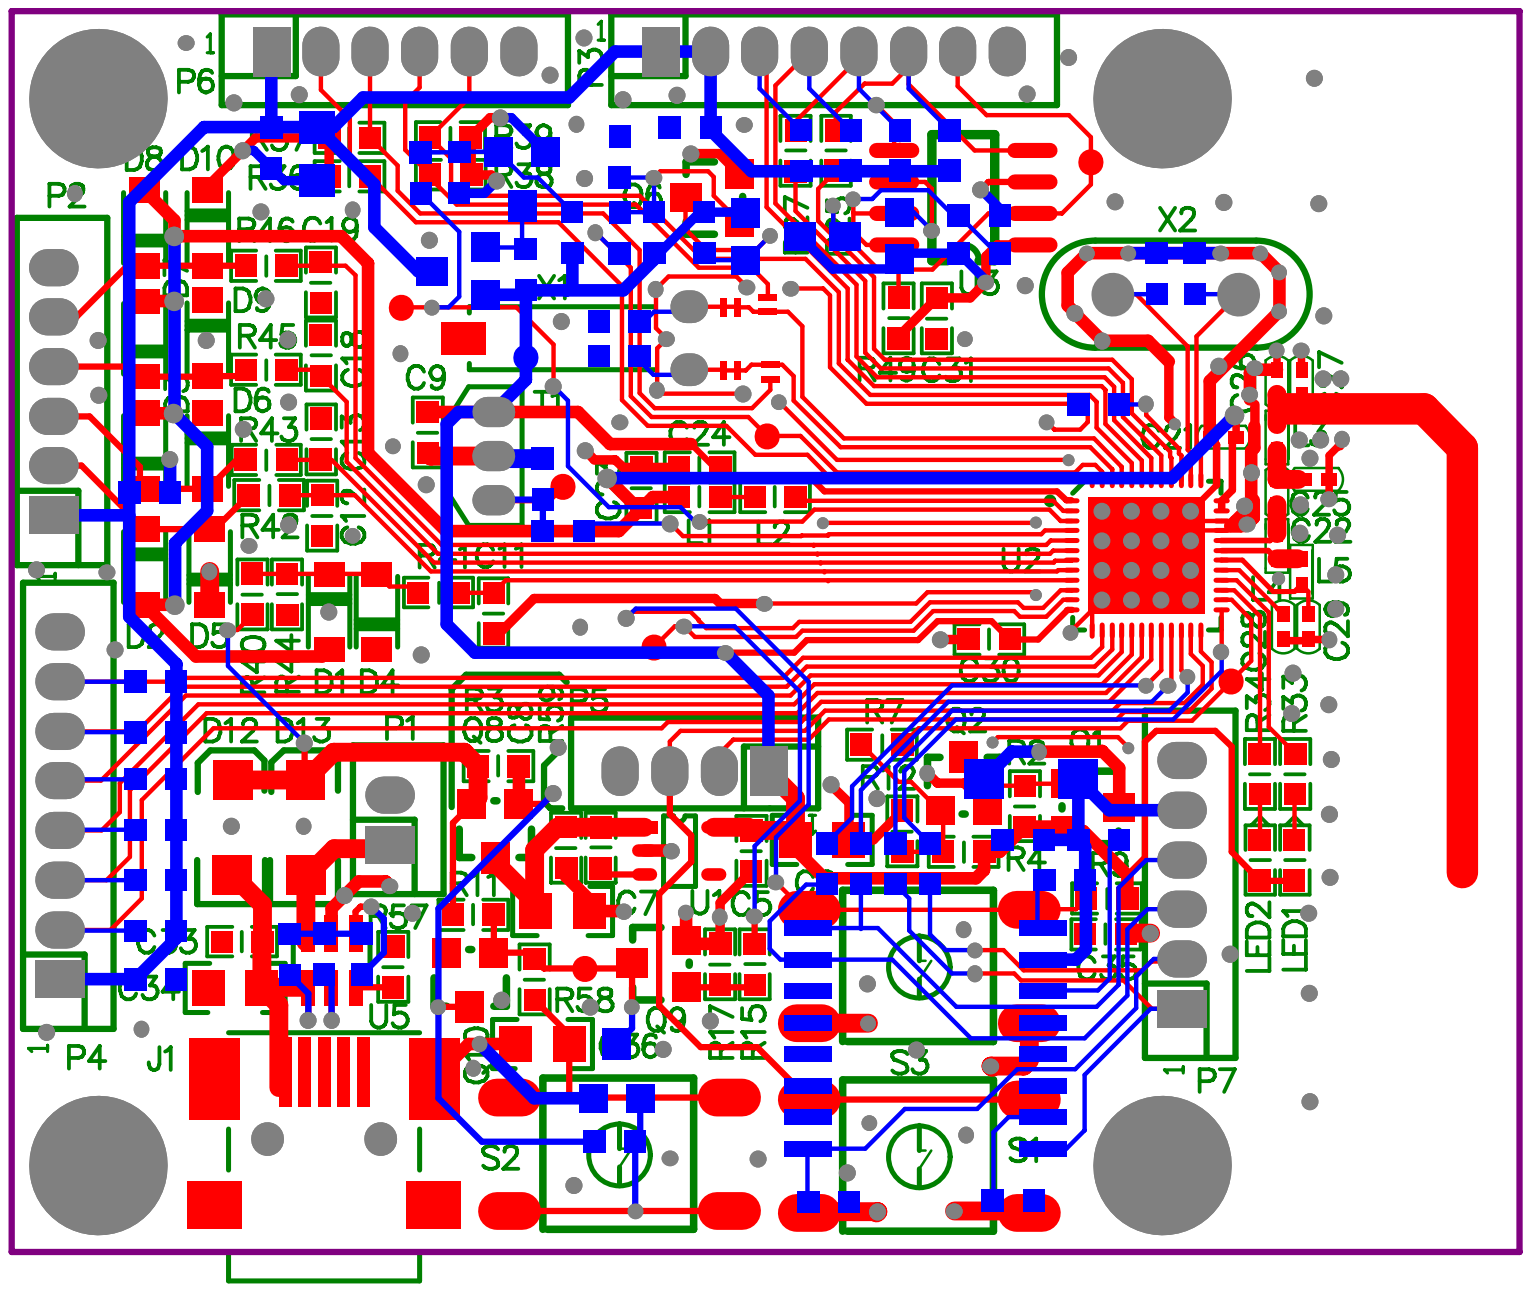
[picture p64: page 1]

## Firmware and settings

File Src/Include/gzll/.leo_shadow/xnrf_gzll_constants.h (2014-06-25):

//@+leo-ver=4-thin
//@+node:gan0ling.20140624153650.3683:@shadow nrf_gzll_constants.h
//@@language c
//@@tabwidth -4
//@+others
//@-others
/* Copyright (c) 2011 Nordic Semiconductor. All Rights Reserved.
 *
 * The information contained herein is property of Nordic Semiconductor ASA.
 * Terms and conditions of usage are described in detail in NORDIC
 * SEMICONDUCTOR STANDARD SOFTWARE LICENSE AGREEMENT.
 *
 * Licensees are granted free, non-transferable use of the information. NO
 * WARRANTY of ANY KIND is provided. This heading must NOT be removed from
 * the file.
 *
 * $LastChangedRevision: 32956 $
 */


/**
 * @file
 * @brief Gazell Link Layer constants and default values.
 *
 * NOTE! Changing values here has no effect. They are only provided as a reference.
 */

#ifndef NRF_GZLL_CONSTANTS_H__
#define NRF_GZLL_CONSTANTS_H__


/**
 * @addtogroup gzll_02_api
 * @{
 */

 
/*****************************************************************************/
/** @name Hardware resources used by Gazell */
/*****************************************************************************/
#define NRF_GZLL_HIGH_IRQ_PRIORITY 0        ///< Interrupt priority the Gazell timer and the radio
#define NRF_GZLL_LOW_IRQ_PRIORITY 1         ///< Interrupt priority for Gazell callback functions.

#ifndef USE_SD_HW_RESOURCES
#define NRF_GZLL_SWI_IRQn SWI0_IRQn              ///< Software interrupt # used for callback functions.
#define NRF_GZLL_SWI_IRQ_HANDLER SWI0_IRQHandler ///< Software interrupt handler used for callback functions.

#define NRF_GZLL_TIMER NRF_TIMER2                               ///< Timer to be used as flywheel timer.
#define NRF_GZLL_TIMER_PERPOWER_Msk POWER_PERPOWER_TIMER2_Msk   ///< PERPOWER mask for the timer.
#define NRF_GZLL_TIMER_IRQn TIMER2_IRQn                         ///< Interrupt # for the timer.
#define NRF_GZLL_TIMER_IRQ_HANDLER TIMER2_IRQHandler            ///< Interrupt handler for the timer.           

// In addition, Gazell uses the radio peripheral and radio interrupts.
               
/*
 * PPI configuration 
 */
#define NRF_GZLL_PPI_EEP0 (NRF_PPI -> CH0_EEP)      ///< Gazell PPI event endpoint 0
#define NRF_GZLL_PPI_TEP0 (NRF_PPI -> CH0_TEP)      ///< Gazell PPI task endpoint 0
#define NRF_GZLL_PPI_EEP1 (NRF_PPI -> CH1_EEP)      ///< Gazell PPI event endpoint 1
#define NRF_GZLL_PPI_TEP1 (NRF_PPI -> CH1_TEP)      ///< Gazell PPI task endpoint 1
#define NRF_GZLL_PPI_EEP2 (NRF_PPI -> CH2_EEP)      ///< Gazell PPI event endpoint 2
#define NRF_GZLL_PPI_TEP2 (NRF_PPI -> CH2_TEP)      ///< Gazell PPI task endpoint 2

#define NRF_GZLL_PPI_CHEN_MSK_0_AND_1 (0x03)        ///< Channel enable/disable mask for PPI endpoint 0 and 1.
#define NRF_GZLL_PPI_CHEN_MSK_2 (0x04)              ///< Channel enable/disable mask for PPI endpoint 2.

#else

#define NRF_GZLL_SWI_IRQn SWI1_IRQn              ///< Software interrupt # used for callback functions.
#define NRF_GZLL_SWI_IRQ_HANDLER SWI1_IRQHandler ///< Software interrupt handler used for callback functions.

#define NRF_GZLL_TIMER NRF_TIMER0                               ///< Timer to be used as flywheel timer.
#define NRF_GZLL_TIMER_PERPOWER_Msk POWER_PERPOWER_TIMER0_Msk   ///< PERPOWER mask for the timer.
#define NRF_GZLL_TIMER_IRQn TIMER0_IRQn                         ///< Interrupt # for the timer.
#define NRF_GZLL_TIMER_IRQ_HANDLER TIMER0_IRQHandler            ///< Interrupt handler for the timer.           

// In addition, Gazell uses the radio peripheral and radio interrupts.
               
/*
 * PPI configuration 
 */
#define NRF_GZLL_PPI_EEP0 (NRF_PPI -> CH8_EEP)      ///< Gazell PPI event endpoint 0
#define NRF_GZLL_PPI_TEP0 (NRF_PPI -> CH8_TEP)      ///< Gazell PPI task endpoint 0
#define NRF_GZLL_PPI_EEP1 (NRF_PPI -> CH9_EEP)      ///< Gazell PPI event endpoint 1
#define NRF_GZLL_PPI_TEP1 (NRF_PPI -> CH9_TEP)      ///< Gazell PPI task endpoint 1
#define NRF_GZLL_PPI_EEP2 (NRF_PPI -> CH10_EEP)      ///< Gazell PPI event endpoint 2
#define NRF_GZLL_PPI_TEP2 (NRF_PPI -> CH10_TEP)      ///< Gazell PPI task endpoint 2

#define NRF_GZLL_PPI_CHEN_MSK_0_AND_1 (0x300)        ///< Channel enable/disable mask for PPI endpoint 0 and 1.
#define NRF_GZLL_PPI_CHEN_MSK_2 (0x400)              ///< Channel enable/disable mask for PPI endpoint 2.

#endif

#define NRF_GZLL_CONST_PIPE_COUNT 8                 ///< Number of TX pipes (at least one for each Device-Host pairs).
#define NRF_GZLL_CONST_FIFO_LENGTH 3                ///< Maximum number of packets allowed in a TX or RX FIFO.
#define NRF_GZLL_CONST_MAX_TOTAL_PACKETS 6          ///< Maximum number of packets available for reservation at any one time.
#define NRF_GZLL_CONST_MAX_PAYLOAD_LENGTH 32        ///< Maximum allowed payload length in bytes. 
#define NRF_GZLL_CONST_CALLBACK_QUEUE_LENGTH 10     ///< Maximum number of notifications allowed in the callback queue.
/** @} */
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

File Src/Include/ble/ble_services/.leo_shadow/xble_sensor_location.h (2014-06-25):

//@+leo-ver=4-thin
//@+node:gan0ling.20140624153650.3883:@shadow ble_sensor_location.h
//@@language c
//@@tabwidth -4
//@+others
//@-others
/* Copyright (c) 2012 Nordic Semiconductor. All Rights Reserved.
 *
 * The information contained herein is property of Nordic Semiconductor ASA.
 * Terms and conditions of usage are described in detail in NORDIC
 * SEMICONDUCTOR STANDARD SOFTWARE LICENSE AGREEMENT.
 *
 * Licensees are granted free, non-transferable use of the information. NO
 * WARRANTY of ANY KIND is provided. This heading must NOT be removed from
 * the file.
 *
 */

 /* Attention!
*  To maintain compliance with Nordic Semiconductor ASA抯 Bluetooth profile
*  qualification listings, this section of source code must not be modified.
*/
 
#ifndef BLE_SENSOR_LOCATION_H__
#define BLE_SENSOR_LOCATION_H__

typedef enum {
    BLE_SENSOR_LOCATION_OTHER        = 0 ,  /**<-- Other        */
    BLE_SENSOR_LOCATION_TOP_OF_SHOE  = 1 ,  /**<-- Top of shoe  */
    BLE_SENSOR_LOCATION_IN_SHOE      = 2 ,  /**<-- In shoe      */
    BLE_SENSOR_LOCATION_HIP          = 3 ,  /**<-- Hip          */
    BLE_SENSOR_LOCATION_FRONT_WHEEL  = 4 ,  /**<-- Front Wheel  */
    BLE_SENSOR_LOCATION_LEFT_CRANK   = 5 ,  /**<-- Left Crank   */
    BLE_SENSOR_LOCATION_RIGHT_CRANK  = 6 ,  /**<-- Right Crank  */
    BLE_SENSOR_LOCATION_LEFT_PEDAL   = 7 ,  /**<-- Left Pedal   */
    BLE_SENSOR_LOCATION_RIGHT_PEDAL  = 8 ,  /**<-- Right Pedal  */
    BLE_SENSOR_LOCATION_FRONT_HUB    = 9 ,  /**<-- Front Hub    */
    BLE_SENSOR_LOCATION_REAR_DROPOUT = 10,  /**<-- Rear Dropout */
    BLE_SENSOR_LOCATION_CHAINSTAY    = 11,  /**<-- Chainstay    */
    BLE_SENSOR_LOCATION_REAR_WHEEL   = 12,  /**<-- Rear Wheel   */
    BLE_SENSOR_LOCATION_REAR_HUB     = 13,  /**<-- Rear Hub     */
}ble_sensor_location_t;

#define BLE_NB_MAX_SENSOR_LOCATIONS 14

#endif // BLE_SENSOR_LOCATION_H__

//@-node:gan0ling.20140624153650.3883:@shadow ble_sensor_location.h
//@-leo

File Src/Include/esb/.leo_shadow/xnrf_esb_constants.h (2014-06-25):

//@+leo-ver=4-thin
//@+node:gan0ling.20140624153650.3708:@shadow nrf_esb_constants.h
//@@language c
//@@tabwidth -4
//@+others
//@-others
/* Copyright (c) 2012 Nordic Semiconductor. All Rights Reserved.
 *
 * The information contained herein is property of Nordic Semiconductor ASA.
 * Terms and conditions of usage are described in detail in NORDIC
 * SEMICONDUCTOR STANDARD SOFTWARE LICENSE AGREEMENT.
 *
 * Licensees are granted free, non-transferable use of the information. NO
 * WARRANTY of ANY KIND is provided. This heading must NOT be removed from
 * the file.
 *
 * $LastChangedRevision: 32956 $
 */


/**
 * @file
 * @brief Enhanced ShockBurst constants and default values.
 *
 * NOTE! Changing values here has no effect. They are only provided as a reference.
 */

#ifndef NRF_ESB_CONSTANTS_H__
#define NRF_ESB_CONSTANTS_H__

/**
 * @addtogroup esb_02_api
  * @{
*/


/*****************************************************************************/
/** @name Hardware resources used by Enhanced ShockBurst */
/*****************************************************************************/
#define NRF_ESB_HIGH_IRQ_PRIORITY 0        ///< Interrupt priority the ESB timer and the radio
#define NRF_ESB_LOW_IRQ_PRIORITY 1         ///< Interrupt priority for ESB callback functions.

#ifndef USE_SD_HW_RESOURCES
#define NRF_ESB_SWI_IRQn SWI0_IRQn              ///< Software interrupt # used for callback functions.
#define NRF_ESB_SWI_IRQ_HANDLER SWI0_IRQHandler ///< Software interrupt handler used for callback functions.

#define NRF_ESB_TIMER NRF_TIMER2                               ///< Timer to be used as flywheel timer.
#define NRF_ESB_TIMER_PERPOWER_Msk POWER_PERPOWER_TIMER2_Msk   ///< PERPOWER mask for the timer.
#define NRF_ESB_TIMER_IRQn TIMER2_IRQn                         ///< Interrupt # for the timer.
#define NRF_ESB_TIMER_IRQ_HANDLER TIMER2_IRQHandler            ///< Interrupt handler for the timer.           

// In addition, ESB uses the radio peripheral and radio interrupts.
               
/*
 * PPI configuration 
 */
#define NRF_ESB_PPI_EEP0 (NRF_PPI -> CH0_EEP)   ///< ESB PPI event endpoint 0.
#define NRF_ESB_PPI_TEP0 (NRF_PPI -> CH0_TEP)   ///< ESB PPI task endpoint 0.
#define NRF_ESB_PPI_EEP1 (NRF_PPI -> CH1_EEP)   ///< ESB PPI event endpoint 1.
#define NRF_ESB_PPI_TEP1 (NRF_PPI -> CH1_TEP)   ///< ESB PPI task endpoint 1.
#define NRF_ESB_PPI_EEP2 (NRF_PPI -> CH2_EEP)   ///< ESB PPI event endpoint 2.
#define NRF_ESB_PPI_TEP2 (NRF_PPI -> CH2_TEP)   ///< ESB PPI task endpoint 2.

#define NRF_ESB_PPI_CHEN_MSK_0_AND_1 (0x03)     ///< Channel enable/disable mask for PPI endpoint 0 and 1.
#define NRF_ESB_PPI_CHEN_MSK_2 (0x04)           ///< Channel enable/disable mask for PPI endpoint 2.
#else
#define NRF_ESB_SWI_IRQn SWI1_IRQn              ///< Software interrupt # used for callback functions.
#define NRF_ESB_SWI_IRQ_HANDLER SWI1_IRQHandler ///< Software interrupt handler used for callback functions.

#define NRF_ESB_TIMER NRF_TIMER0                               ///< Timer to be used as flywheel timer.
#define NRF_ESB_TIMER_PERPOWER_Msk POWER_PERPOWER_TIMER0_Msk   ///< PERPOWER mask for the timer.
#define NRF_ESB_TIMER_IRQn TIMER0_IRQn                         ///< Interrupt # for the timer.
#define NRF_ESB_TIMER_IRQ_HANDLER TIMER0_IRQHandler            ///< Interrupt handler for the timer.           

// In addition, ESB uses the radio peripheral and radio interrupts.
               
/*
 * PPI configuration 
 */
#define NRF_ESB_PPI_EEP0 (NRF_PPI -> CH8_EEP)   ///< ESB PPI event endpoint 0.
#define NRF_ESB_PPI_TEP0 (NRF_PPI -> CH8_TEP)   ///< ESB PPI task endpoint 0.
#define NRF_ESB_PPI_EEP1 (NRF_PPI -> CH9_EEP)   ///< ESB PPI event endpoint 1.
#define NRF_ESB_PPI_TEP1 (NRF_PPI -> CH9_TEP)   ///< ESB PPI task endpoint 1.
#define NRF_ESB_PPI_EEP2 (NRF_PPI -> CH10_EEP)   ///< ESB PPI event endpoint 2.
#define NRF_ESB_PPI_TEP2 (NRF_PPI -> CH10_TEP)   ///< ESB PPI task endpoint 2.

#define NRF_ESB_PPI_CHEN_MSK_0_AND_1 (0x300)     ///< Channel enable/disable mask for PPI endpoint 0 and 1.
#define NRF_ESB_PPI_CHEN_MSK_2 (0x400)           ///< Channel enable/disable mask for PPI endpoint 2.

#endif

#define NRF_ESB_CONST_PIPE_COUNT 8              ///< Number of TX pipes (at least one for each Device-Host pairs).
#define NRF_ESB_CONST_FIFO_LENGTH 3             ///< Maximum number of packets allowed in a TX or RX FIFO.
#define NRF_ESB_CONST_MAX_TOTAL_PACKETS 6       ///< Maximum number of packets available for reservation at any one time.
#define NRF_ESB_CONST_MAX_PAYLOAD_LENGTH 32     ///< Maximum allowed payload length in bytes. 
#define NRF_ESB_CONST_CALLBACK_QUEUE_LENGTH 10  ///< Maximum number of notifications allowed in the callback queue.
/** @} */
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

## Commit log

2014-06-10 删除重复的资料
2014-06-10 1.电源分析 2.管脚资源中隐藏不需要的列
    [nRF51822硬件设计相关分析.xlsx, 管脚资源.xlsx]
2014-06-10 添加SDK等资料
2014-06-10 添加SDK
2014-06-10 芯片选型
    [管脚资源.xlsx]
2014-06-10 添加传感器参数
2014-06-10 1.标注nRF51_serials_reference_manual 2.电源方案初步决定。
    [nRF51822硬件设计相关分析.xlsx]
2014-06-10 Create 传感器选型指南
2014-06-10 电源初步方案，待专业硬件人员探讨
    [nRF51822硬件设计相关分析.xlsx]
2014-06-11 热拔插方案谈谈
    [nRF51822硬件设计相关分析.xlsx]
2014-06-11 1.添加单总线相关资料 2.设备模块化，准备用单总线EEPROM保存信息
    [nRF51822硬件设计相关分析.xlsx]
2014-06-11 添加IO口电平的考虑
    [nRF51822硬件设计相关分析.xlsx]
2014-06-11 希望大家能指出不足，我会尽快改进，其他条目会尽快更新
    [湿敏芯片.xlsx, 空气质量芯片.xlsx, 芯片.xlsx]
2014-06-12 增加选型条件
2014-06-12 Update 传感器选型指南
2014-06-12 隐藏所有开发板管脚资源
    [管脚资源.xlsx]
2014-06-12 更改电源方式，选取DC/DC方式。
    [nRF51822硬件设计相关分析.xlsx]
2014-06-12 添加了电感电容的推荐值，以及电压监控阀值。
    [nRF51822硬件设计相关分析.xlsx]
2014-06-12 1.用户升级的考虑 2.新增一个开发板的资料。从淘宝上购买的。
    [nRF51822硬件设计相关分析.xlsx]
2014-06-12 新加代码目录，不过还没有编译成功
2014-06-13 可以正常编译，调试
2014-06-13 修改仓库地址
2014-06-13 完成EnvMonitor Block Diagram制作
    [系统框图.xlsx]
2014-06-13 增加文件内容列表
2014-06-13 设备热拔插的方案分析 重命名README为README.md
    [nRF51822硬件设计相关分析.xlsx]
2014-06-14 添加coreutil 修改Eclipse使可以本地编译
2014-06-16 锂电池相关资料
2014-06-16 增加DC converter分析资料
2014-06-16 编译环境修改
2014-06-16 增加.gitignore
2014-06-17 温度芯片选型 EnvMonitor软件框图
    [系统框图.xlsx, 芯片选型.xlsx, 软件框图.xlsx]
2014-06-18 新增按键 多增一个彩色LED
    [系统框图.xlsx]
2014-06-18 软件框图ok
    [软件框图.xlsx]
2014-06-18 添加FatFS库，还没有编译
2014-06-18 添加系统升级Sequence Diagram
    [软件框图.xlsx]
2014-06-19 添加原理图文件，初稿。
    [EnvMonitor.PcbLib, EnvMonitor.PrjPcb, EnvMonitor.SchDoc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]
2014-06-19 memory_layout 软件框图 SPI Flash datasheet
    [memory_layout.xlsx, 软件框图.xlsx]
2014-06-20 添加NRF51822参考手册翻译
2014-06-20 14章翻译完毕
2014-06-20 移动到Note目录
2014-06-20 Nordic SDK scheduler翻译
2014-06-20 Scheduler设计草图
    [软件框图.xlsx]
2014-06-25 添加Leo Editor开发环境
    [软件框图.xlsx]
2014-06-25 OneWire Driver header file
2014-06-26 DS2482状态寄存器描述
2014-06-26 1-Wire Detail Design
    [软件框图.xlsx]
2014-06-27 原理图Review相关资料
    [memory_layout.xlsx]
2014-06-27 添加原理图Review记录，方便大家一起讨论
2014-06-27 6/27原理图
2014-06-27 原理图位置
2014-06-27 增加三个修改点
2014-06-27 review更新
2014-06-27 修改格式
2014-06-27 原理图中添加Logo
2014-06-27 修改原理图摆放位置，以更容易发现PDF版本的原理图
    [nRF51822硬件设计相关分析.xlsx]
2014-06-27 原理图review；SPI Flash Reset
2014-06-27 原理图Review：S1防抖
2014-06-27 原理图分析Review完。还不够详尽，等硬件做好后，再通过示波器详细分析，并更新相关文档
2014-06-27 USB to SPI Converter datasheet
    [软件框图.xlsx]
2014-06-27 介绍资料更新
2014-06-28 astah工具提示
2014-06-30 原理图和原理图分析资料
    [Charge.SchDoc, EnvMonitor.PrjPcb, EnvMonitor.SchDoc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]
2014-06-30 remove 不用的datasheet
2014-06-30 SensorBoard UML
    [软件框图.xlsx]
2014-06-30 修改LeoEditor编译环境，能够正常编译
2014-06-30 SensorManager UML
    [nRF51822硬件设计相关分析.xlsx]
2014-06-30 power annotation
2014-07-01 修改根目录下README.md，添加系统框图。
    [系统框图.xlsx]
2014-07-01 添加空格，防止两个图片拼成一个
2014-07-01 更新原理图
    [Charge.SchDoc, EnvMonitor.PrjPcb, EnvMonitor.SchDoc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]
2014-07-01 第一版管脚资源做成
    [管脚资源.xlsx]
2014-07-01 在线监测序列图
2014-07-02 1.添加SensorBoard CMD设计草稿 2.增加ROMDriver模块，负责操作1-Wire EEPROM
    [memory_layout.xlsx, 系统框图.xlsx]
2014-07-03 新增OneWireROM模块 SensorBoard配置信息读取流程ok
    [memory_layout.xlsx]
2014-07-04 SensorBoard 配置信息读取完成
    [memory_layout.xlsx]
2014-07-05 更改EEPROM Layout
    [memory_layout.xlsx]
2014-07-07 BoardManager 修改
2014-07-09 build手册
2014-07-09 添加编译和下载段落
2014-07-09 I2CDriver redesign
2014-07-10 删除PinMuxCfg模块
2014-07-11 减少代码大小
2014-07-12 删除不必要的文件
    [芯片.xlsx]
2014-07-14 SensorCapture UML
2014-07-14 add mxml。XML读写库
2014-07-14 SensorCapture模块设计完成
2014-07-15 新AD工程
    [Charge.SchDoc, EnvMonitor V1.0a.PcbDoc, EnvMonitor V1.0a.PrjPcb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]
2014-07-15 DataStorage新接口
2014-07-17 SensorUploader设计完了
2014-07-18 SensorQuery设计完了
2014-07-19 SensorQuerys设计完成
2014-07-20 Scheduler模块设计完成
2014-07-20 添加mxml忘记提交的文件
2014-07-20 重命名PinMuxCfg为SettingManager
2014-07-20 添加SettingManager的LEO文件
2014-07-20 Scheduler_Register函数编写
2014-08-06 Scheduler模块编码完成
2014-08-22 添加PCB的PDF版本
2014-08-22 Layout以及函数接口的一些更改
    [memory_layout.xlsx]
2014-08-22 Initializer模块编码完成
2014-08-22 SystemDebug接口定义完了
2014-08-22 更新LeoEditor开发环境
2014-08-22 更新MakeFile，添加Scheduler模块的编译
2014-08-22 添加前进后退等快捷键
